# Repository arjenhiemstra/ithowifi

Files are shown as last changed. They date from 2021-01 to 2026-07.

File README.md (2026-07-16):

# ithowifi
ESP based WiFi controller for Itho devices

*(note: I'm in no way a professional hardware/software engineer and have no background in these subjects. I like this for a hobby, to learn and to share my projects)*

Finished boards can be ordered in my webshop:
[https://www.nrgwatch.nl](http://www.nrgwatch.nl)
or in my Tindie store:
[https://www.tindie.com/products/19680/](https://www.tindie.com/products/19680/)

|CVE Add-on|non-CVE wifi module|
|:---:|:---:|
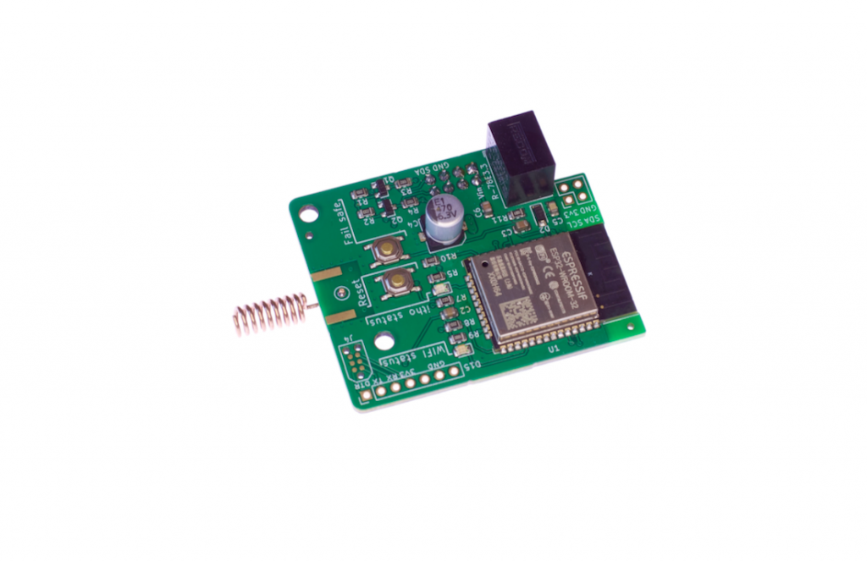
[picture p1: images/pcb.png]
CVE Add-on PCB
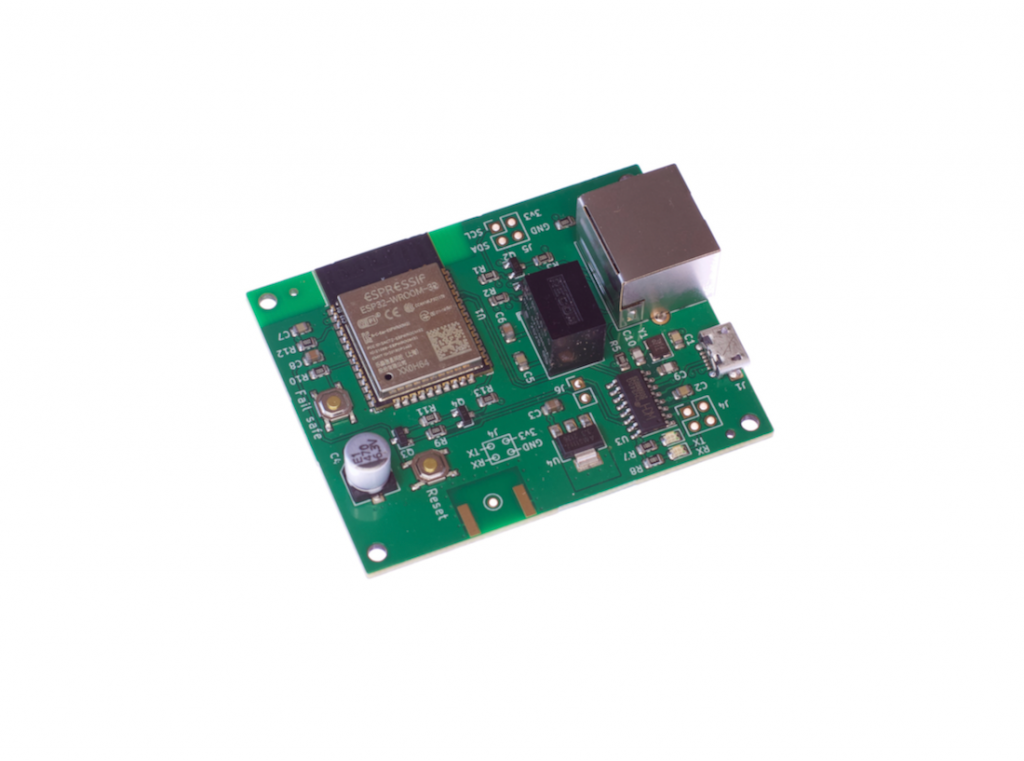
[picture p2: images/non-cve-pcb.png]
non-CVE module PCB
|  |  |

## WiFi add-on to control itho central ventilation units

-   Control your Itho Daalderop ventilation unit with one simple add-on module
-   No hardware changes needed to the Itho unit, no warranty void
-   Control fan speed through the web interface, REST API v2, MQTT, or Home Assistant
-   Send remote commands via virtual remotes (I2C) or RF remotes (CC1101 wireless)
-   RF standalone mode for devices without I2C connection (e.g. HRU 400)
-   OTA firmware updates directly from the web interface
-   Easily integrate in any home automation system through MQTT or REST API
-   Companion integrations available:
    - [Home Assistant](https://github.com/arjenhiemstra/ithowifi-ha-integration) (REST API, elementary)
    - [Home Assistant](https://github.com/jasperslits/haithowifi) (MQTT API, feature rich)
    - [Homey](https://homey.app/en-nl/app/nl.monkeysoft.nrgwatch/Itho-Daalderop/) (REST API)
    - [Homebridge](https://github.com/SanderBaron/homebridge-itho-daalderop-HUE) (Apple HomeKit, REST API / MQTT)
-   Installation can be done in minutes
-   Detailed installation manual and setup wizard

### CVE models (IthiWiFi CVE add-on - I2C):
-   CVE ECO 2 (also sold by 'Heatrae Sadia' in the UK)
-   CVE ECO RFT (SE/SP, HE/HP)
-   CVE-S ECO / PAK / Optima / CO2
-   HRU 200 ECO (also sold as 'Elektrodesign EHR 140 Akor BP' and 'Heatrae Sadia Advance Plus')

### NON-CVE models (IthiWiFi NON-CVE add-on - I2C):
-   HRU ECO fan
-   HRU 150 / 200 / 250 / 300 / 350
-   DemandFlow / QualityFlow
-   WPU 4G / 5G (heat pump)
-   AutoTemp

### RF standalone mode (IthiWiFi NON-CVE add-on wuth CC1101):
-   HRU 400
-   Most Itho devices controllable via RF (CC1101 module required)
-   Status data received wirelessly via 31DA/31D9 RF messages

####   Note about CVE and HRU200 firmware:
The CVE add-on controls the Itho unit in standard or medium mode setting only. If you leave the Itho in low or high setting, it won't accept I2C commands from the add-on (Itho designed behaviour). Adding a CC1101 RF module and/or using the virtual remote function can circumvent this issue. The virtual remote function can also be used to force medium mode before sending commands.

## APIs

The add-on provides multiple ways to integrate with your home automation system:

-   **REST API v2** — RESTful endpoints at `/api/v2/*` with JSON request/response format. [OpenAPI spec](https://github.com/arjenhiemstra/ithowifi/wiki/REST-API-v2) available.
-   **MQTT** — publish device status, receive commands. Compatible with Home Assistant MQTT Discovery.
-   **WebSocket** — real-time bidirectional communication used by the web interface.

## OTA Firmware Updates

Firmware can be updated directly from the web interface:
-   Select a firmware version from the dropdown (stable and beta versions available)
-   Click Install — the device downloads and flashes the firmware automatically
-   Manual upload via file is also supported

## Hardware:

A sample hardware design (KiCad) is included, this module can be plugged on the Itho main PCB directly without extra components.
The design files and BOM can be found in the [hardware repo](https://github.com/arjenhiemstra/ithowifi_hardware).

## Further information:

More information is available on the wiki and in the manual:
|  |  |
|---|---|
|Wiki:  |https://github.com/arjenhiemstra/ithowifi/wiki  |
|Dutch:  |https://github.com/arjenhiemstra/ithowifi/raw/master/handleiding.pdf  |
|English:  |https://github.com/arjenhiemstra/ithowifi/raw/master/manual.pdf  |

## Support this project:
If you like this project and would like to support it, please contribute with code updates, wiki edits, pull requests etc. You could also buy me a coffee as appreciation.
I will be really thankfull for anything even if it is just a kind comment towards my work, because that helps me a lot.

"Buy Me A Coffee" (https://www.buymeacoffee.com/nrgwatch)

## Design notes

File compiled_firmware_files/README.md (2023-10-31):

# Hardware revisions

Make sure to flash the correct firmware file! 
Flashing a firmware file for the wrong hardware revision will brick the device. This is reversible but especially with revision 2 you need extra hardware (USB-TTL adapter with a good power supply) to do so.

## CVE Add-on

Hardware revision 1:

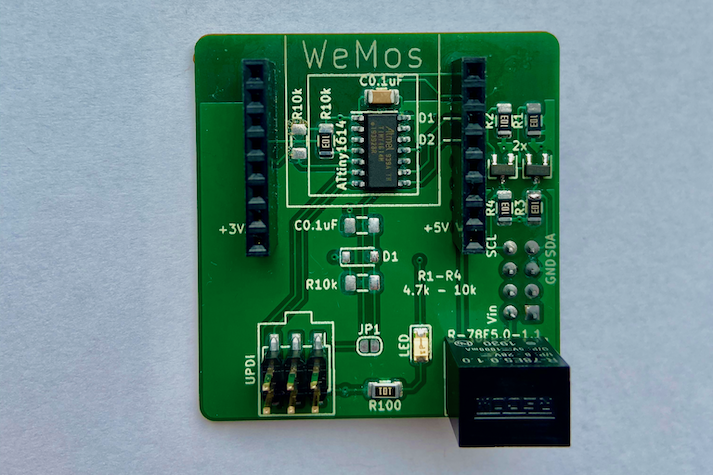
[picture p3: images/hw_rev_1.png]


Hardware revision 2:

Hardware revision 2

## non-CVE wifi module

Hardware revision 1:

Hardware revision 1

Since firmware version 2.6.0 hardware revision 2 and the non-cve module use the same firmware file.

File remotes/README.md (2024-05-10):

**Remotes known to be working**

An overview of supported remotes can be found here:
[remotes.pdf](https://github.com/arjenhiemstra/ithowifi/blob/master/remotes/remotes.pdf)

**Remotes known to be partly working**

RFT-Auto-N (04-00161) and RFT-N (04-00160) currently only work in legacy (uni-directional) mode

Since [2.9.0-beta1](https://github.com/arjenhiemstra/ithowifi/releases/tag/Version-2.9.0-beta1)
Bi-Directional join and communication is supported (partially). There might still be a error indication but most functionality should work for the RFT-Auto-N (04-00161), RFT-N (04-00160) and Itho Spider (03-00476) 

**Remotes known to be not working**

536-0106, seems like it uses a different (older) version of the protocol.

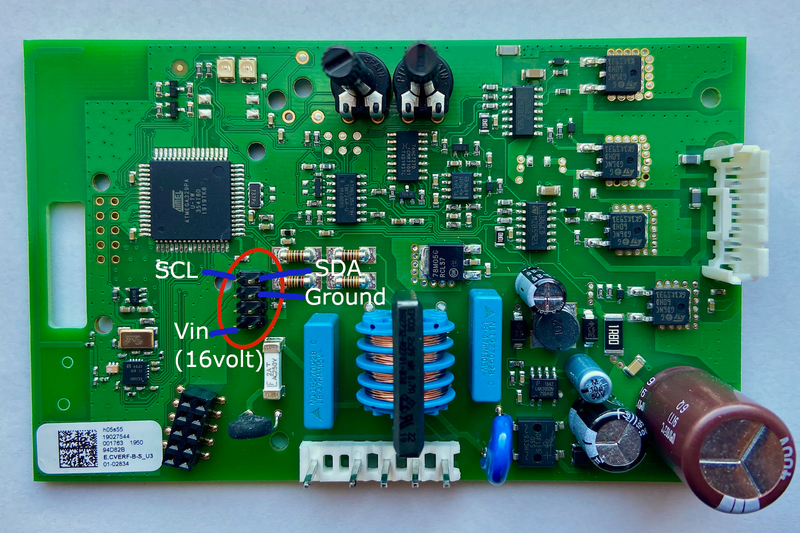
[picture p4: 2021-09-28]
images/wiki/pinout_itho.png

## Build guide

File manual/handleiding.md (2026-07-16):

NRG.Watch logo

# Itho WiFi add-on — Gebruikershandleiding

**Versie:** V1.13

**Datum:** 14-06-2026

| | |
|---|---|
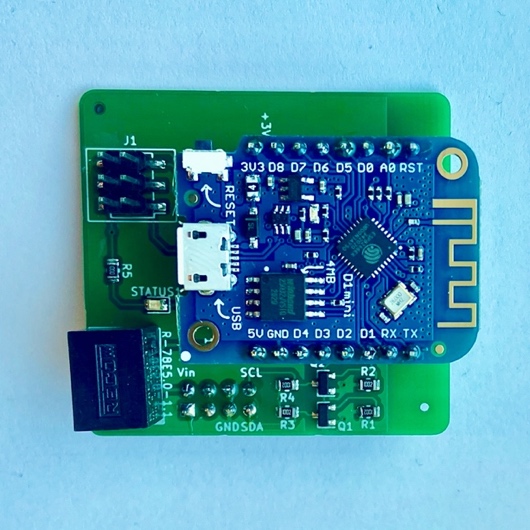
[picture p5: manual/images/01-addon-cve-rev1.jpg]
CVE add-on revisie 1.x
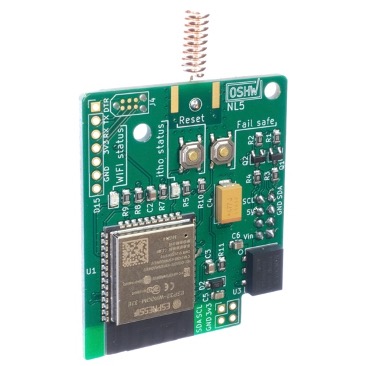
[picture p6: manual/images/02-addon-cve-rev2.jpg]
CVE add-on revisie 2.x
|  |  |
| **CVE add-on revisie 1.x** | **CVE add-on revisie 2.x** |
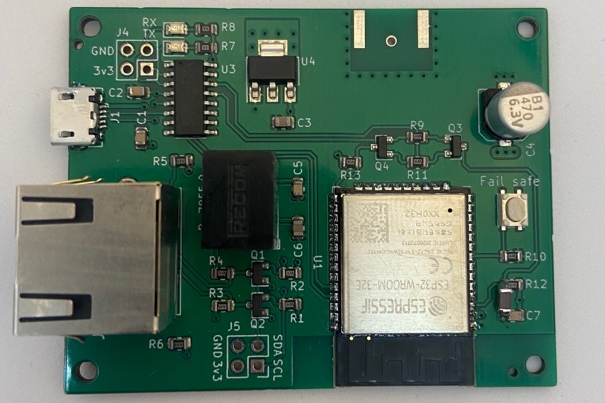
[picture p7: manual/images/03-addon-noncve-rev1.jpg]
Non-CVE add-on revisie 1.x
|  | |
| **Non-CVE add-on revisie 1.x** | |

---

## Inhoudsopgave

- [Voorwoord](#voorwoord)
- [Fysieke Installatie CVE Add-on](#fysieke-installatie-cve-add-on)
- [Fysieke Installatie non-CVE Add-on](#fysieke-installatie-non-cve-add-on)
- [Extra informatie voor de HRU250 en HRU300](#extra-informatie-voor-de-hru250-en-hru300)
- [Add-on Instellen](#add-on-instellen)
- [Gebruik (Webinterface, API)](#gebruik-webinterface-api)
- [Apparaat-specifieke informatie](#apparaat-specifieke-informatie)
- [Temperatuur/Vochtsensor](#temperatuurvochtsensor)
- [Virtual Remote](#virtual-remote)
- [RF-Module](#rf-module)
- [Firmware bijwerken](#firmware-bijwerken)
- [Module resetten](#module-resetten)
- [Hmmm, maar…. Waar vind ik verdere informatie?](#hmmm-maar-waar-vind-ik-verdere-informatie)
- [Hardware revisies](#hardware-revisies)
- [Installatievoorbeeld](#installatievoorbeeld)
- [Node-RED automatiseringsvoorbeeld](#node-red-automatiseringsvoorbeeld)
- [Ondersteunde afstandsbedieningen](#ondersteunde-afstandsbedieningen)

---

## Voorwoord

Bedankt voor de aanschaf van een (of meerdere) add-on modules, veel plezier met het gebruik!

Een belangrijke waarschuwing vooraf! Verschillende Itho apparaten (in ieder geval de CVE's en HRU200) zijn niet aanraakveilig als er spanning op staat, ook de laag voltage delen niet. Haal daarom altijd de spanning van het apparaat bij het installeren van een add-on op de printplaat. Zo voorkom je schade aan jezelf en je itho! Indien nodig, bedien de knopjes op de printplaat van de CVE add-on alleen met materiaal dat geen stroom kan geleiden.

Dit is een beknopte handleiding om je op weg te helpen de add-on fysiek te installeren en te verbinden met je eigen wifi netwerk. Informatie over verdere specifieke installaties is online te vinden.

Deze handleiding, de plug-ins voor oa. Home Assistant en Homey, de wiki en verdere informatie online zijn een community effort, een verzameling van bijdragen van gebruikers voor gebruikers. Zonder deze bijdragen was oa. dit document er niet geweest. Het wordt zeer gewaardeerd als je aanvullingen, aanpassingen en/of suggesties hebt!

**Bronnen waar verdere informatie te vinden is:**

- Wiki pagina: <https://github.com/arjenhiemstra/ithowifi/wiki>
- Tweakers.net forum: <https://gathering.tweakers.net/forum/list_message/82125986>
- Tweakers.net forum (WPU specifiek): <https://gathering.tweakers.net/forum/list_messages/2154474>
- Meest gestelde vragen: <https://gathering.tweakers.net/forum/list_messages/1976492/0#label-faq>

---

## Fysieke Installatie CVE Add-on

Om de add-on (PCB) goed te beschermen, leveren wij deze in een antistatisch zakje.

Hieronder volgt een genummerde lijst met handelingen, om de installatie van de add-on te realiseren.

1. Haal de add-on uit het antistatische zakje;
2. U treft naast de add-on, ook een PCB-afstandshouder aan, leg deze even apart.
3. Haal nu de spanning van de Itho ventilatie-unit, door de stekker uit de wandcontactdoos te halen;
4. Om bij de basisprint van de Itho te komen, haalt u de deksel van de unit. Dat kan door met een platte schroevendraaier de klemnokken aan de boven- en onderzijde te ontgrendelen. U ziet nu het kastje waarin de basisprint zit, deze is eenvoudig te bereiken door het deurtje te openen of in geval van een zwarte kap kan deze verwijderd worden door wat zijwaartse druk te combineren met een trek beweging naar boven. Zie de installatie & gebruik handleiding van de fabrikant, voor eventuele andere/specifieke instructies;
5. Plaats nu de PCB-afstandshouder met de kromme / korte kant in het gat op de itho basisprint dat overeenkomt met het gat op de add-on. Door gebruik van deze afstandshouder reduceert de kans, dat door trillingen, gesoldeerde punten mogelijk lostrillen. Eventueel kan deze stap ook na het testen van de add-on gedaan worden;
6. Het plaatsen van de add-on, benodigd geen speciaal gereedschap of andere materialen.
   U kunt, de add-on plaatsen door deze op de 2×4 pin interface aan te brengen.
   Zie Installatievoorbeeld, in het rood omcirkeld, waar de 2×4 pin interface zich bevindt op de basisprint;
7. Breng nu de spanning van de Itho terug door de stekker in de wandcontactdoos te plaatsen.
8. Als de initialisatie succesvol is, licht de Itho status led (zie Hardware revisies) kort op. Vervolgens blijft deze uit. Dit is een teken dat de communicatie, tussen de Itho basis/hoofdprint en add-on succesvol is gestart. De wifi status led zal knipperen als indicatie dat er een access point gestart is.
9. Nu is de add-on geïnstalleerd, sluit het kastje van de basisprint en plaatst u de deksel terug op de unit.

---

## Fysieke Installatie non-CVE Add-on

Om de add-on (PCB) goed te beschermen, leveren wij deze in een antistatisch zakje. Indien u een behuizing mee besteld hebt is de add-on al in de behuizing geplaatst. Laat de add-on in de behuizing zitten, het verwijderen van de print uit de behuizing kan de behuizing beschadigen.

Hieronder volgt een genummerde lijst met handelingen, om de fysieke installatie van de add-on te realiseren.

1. Haal, indien van toepassing, de add-on uit het antistatische zakje;
2. Zoek de COM/Service poort op je Itho device. Dit is aansluiting die lijkt op een netwerkpoort (RJ45 connector). Sluit de add-on met een goede, korte (CAT6a, STP, 25cm) netwerk kabel aan op de COM/Service poort;
3. De add-on is geïnstalleerd en zal een access point starten.

**Nb.** Stroom voor de add-on komt via de netwerkkabel vanuit de aangesloten Itho. In uitzonderlijke gevallen lijkt de Itho niet voldoende stroom te kunnen leveren (bepaalde revisies van de HRU300). Hierdoor is de communicatie met de HRU niet altijd stabiel. Sluit in dat geval een USB voeding aan op de add-on. In alle andere gevallen is dit niet nodig.

---

## Extra informatie voor de HRU250 en HRU300

Om de add-on te kunnen gebruiken met de HRU250 en HRU300 zijn een adapter bordje en PCI-e splitter kabel nodig.

Om deze te installeren:

1. Verwijder de PCI-e kabel uit de HMI van de HRU.
2. Sluit de PCI-e kabel van de HMI aan op de PCI-e splitterkabel.
3. Sluit 1 kant van de splitterkabel aan op de HMI, sluit de overgebleven kant aan op het HRU250/300 adapter bordje.
4. Met de netwerkkabel kan het adapter bordje verbonden worden met de add-on.

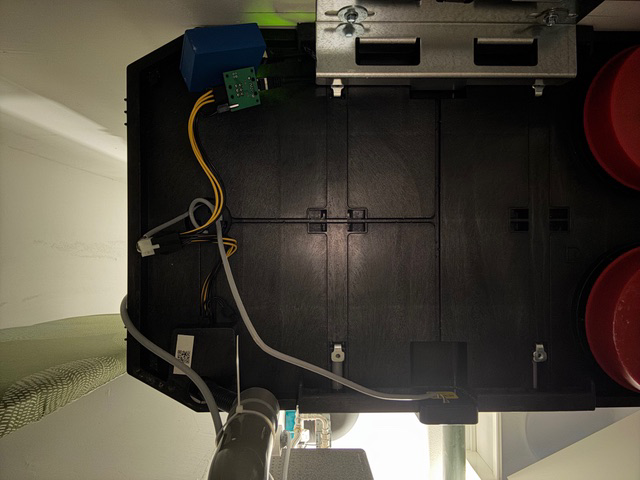
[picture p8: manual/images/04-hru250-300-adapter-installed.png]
HRU250/300 adapter installatie


### Bediening van de HRU250 en HRU300

Deze modellen zijn iets beperkter in de bediening via de add-on in vergelijking met andere Itho modellen. Om deze HRU te bedienen moet je gebruik maken van de CC1101 RF module op de add-on. De Virtual Remote optie werkt bij deze HRU modellen niet.

Om gebruik te maken van de RF module moet deze via de web interface van de add-on geactiveerd worden, dat kan onder het menu "System settings". Na een reboot komt er een menu item bij genaamd "RF Devices". Hier kan een RF device geconfigureerd worden. Dit RF device moet vervolgens gekoppeld worden aan de HRU. Volg hiervoor dezelfde procedure als waarmee ook fysieke remotes gekoppeld worden.

---

## Add-on Instellen

Hieronder treft je een genummerde lijst met stappen om de basis instellingen van de add-on te maken.

### Add-on instellen — *Verbinden met de add-on*

1. Na het aansluiten start de add-on automatisch een WiFi access point. De WiFi status led knippert dan 1x per seconde (zie Hardware revisies).

   Let op: zolang de add-on nog geen verbinding heeft met je WiFi-netwerk, blijft het access point actief. Zodra de add-on verbonden is, schakelt het access point na de ingestelde tijd (standaard 15 minuten) automatisch uit. Deze tijd is aan te passen in de instellingen.

2. Maak met je telefoon, tablet of computer verbinding met het WiFi netwerk van de add-on:
   - Netwerknaam (SSID): **nrg-itho-XXXX** (de laatste 4 tekens zijn uniek per add-on)
   - Wachtwoord: **password**

3. Open een browser en ga naar:
   `http://nrg-itho-XXXX.local` (vervang XXXX door de 4 tekens uit de netwerknaam)
   Werkt dit niet (bijv. op Android)? Ga dan naar <http://192.168.4.1>

### Add-on instellen — *Setup Wizard*

Vanaf firmware versie 3.0 start automatisch een Setup Wizard die je in een aantal stappen door de configuratie leidt:

**Stap 1 — WiFi**

Vul de naam (SSID) en het wachtwoord van je eigen WiFi netwerk in. Optioneel kun je een eigen hostname instellen. Klik op Connect en wacht tot de verbinding bevestigd wordt. Noteer het IP-adres dat getoond wordt — dit heb je nodig om de add-on later te bereiken vanuit je eigen netwerk.

**Stap 2 — Device**

De wizard detecteert automatisch welk type Itho apparaat is aangesloten (bijv. CVE-Silent, HRU 350, DemandFlow) en stelt de meest voorkomende standaardinstellingen in. Bij apparaten zonder I2C-verbinding (bijv. HRU 400) wordt de optie aangeboden om RF standalone modus te activeren.

**Stap 3 — RF** (wordt overgeslagen als er geen CC1101 RF module aanwezig is)

Hier configureer je de RF-afstandsbedieningen. Je kunt een afstandsbediening koppelen (join) met de Itho apparaat, of deze stap overslaan en later via het menu "RF Devices" instellen.

Werk je in RF-standalone modus (een apparaat zonder I2C, bijvoorbeeld de HRU 400)? Dan is dit het moment om een geëmuleerde RFT CO2-remote aan de Itho te koppelen — daarmee stuur je het apparaat vervolgens aan en lees je de status uit.

**Stap 4 — MQTT** (optioneel)

Vul de gegevens van je MQTT server in als je de add-on wilt koppelen aan Home Assistant, Domoticz of een ander domotica platform via MQTT. Schakel eventueel Home Assistant MQTT Auto Discovery in zodat de add-on automatisch als apparaat in Home Assistant verschijnt.

**Stap 5 — HA Discovery** (wordt overgeslagen als MQTT niet is ingeschakeld)

Configureer welke sensoren en statusinformatie via HA Auto Discovery beschikbaar worden gesteld aan Home Assistant.

### Add-on instellen — *Na de wizard*

Verbind je telefoon/computer weer met je eigen WiFi netwerk en open de browser op het IP-adres uit de wizard.

Alle instellingen zijn ook achteraf aan te passen via de web interface. De wizard hoeft niet opnieuw doorlopen te worden.

---

## Gebruik (Webinterface, API)

De Itho unit is nu d.m.v. de web interface (<http://nrg-itho-A1B2.local>, A1B2 vervangen), via MQTT of WebAPI te bedienen.

Wil je de add-on via MQTT koppelen aan domotica? Dan heb je een MQTT-server (broker) nodig. De web interface en de WebAPI werken overigens ook zonder MQTT. Heb je nog geen MQTT-server, dan vind je via onderstaande link een prima voorbeeld hoe je deze installeert op bijvoorbeeld een Raspberry Pi:

<https://randomnerdtutorials.com/how-to-install-mosquitto-broker-on-raspberry-pi/>

### Itho bedienen

Er zijn verschillende mogelijkheden om de Itho te bedienen en de settings aan te passen.

Voor CVE's en de HRU 200 zijn er 2 manieren om de snelheid te regelen: remote-commando's (virtual of RF) en het traploze PWM2I2C-protocol. Voor andere apparaten (bijvoorbeeld de HRU 350) zijn alleen de remote-commando's (virtual remote en/of RF-remote) beschikbaar. Voor de HRU 250 en HRU 300 werken uitsluitend RF-remote commando's. Om RF-remote commando's te versturen moet de CC1101 RF-module aanwezig zijn op de add-on. Virtual-remote commando's (waarbij de add-on een fysieke remote emuleert) worden via de fysieke I2C-verbinding met de Itho verstuurd.

Wat per apparaat precies mogelijk is, staat in het hoofdstuk [Apparaat-specifieke informatie](#apparaat-specifieke-informatie).

Meer details over de verschillende mogelijkheden en de eventuele beperkingen zijn op de wiki te vinden:

<https://github.com/arjenhiemstra/ithowifi/wiki/Controlling-the-speed-of-a-fan>

### Koppeling met Home Domotica software

De add-on kan met andere apparaten en domotica gekoppeld worden via MQTT en de WebAPI. De details hiervan staan in het kopje *De API gebruiken* hieronder.

Voor de meest gebruikte platforms zijn er kant-en-klare integraties:

- **Home Assistant — MQTT Auto Discovery.** Schakel je MQTT in met Home Assistant MQTT Auto Discovery, dan wordt de add-on automatisch als apparaat in Home Assistant geconfigureerd met een basis configuratie. Deze kan handmatig aangepast en uitgebreid worden.
- **Home Assistant — losse integraties.** Er zijn daarnaast twee community-integraties voor Home Assistant:
  - [ithowifi-ha-integration](https://github.com/arjenhiemstra/ithowifi-ha-integration) — gebruikt de REST API (lokaal, eenvoudig).
  - [haithowifi](https://github.com/jasperslits/haithowifi) — gebruikt de MQTT API (uitgebreider).
- **Homey.** De [Itho Daalderop-app](https://homey.app/en-nl/app/nl.monkeysoft.nrgwatch/Itho-Daalderop/) in de Homey app store gebruikt de WebAPI (REST); MQTT is daarvoor niet nodig.
- **Homebridge (Apple HomeKit).** De community-plugin [Homebridge Itho Daalderop HUE](https://github.com/SanderBaron/homebridge-itho-daalderop-HUE) brengt je CVE naar Apple HomeKit. Hij communiceert via de WebAPI of MQTT (MQTT aanbevolen voor directe updates) en biedt optioneel een koppeling met Philips Hue.
- **Domoticz en andere platforms.** Koppeling verloopt via MQTT (of de WebAPI).

### De API gebruiken (WebAPI en MQTT)

De add-on heeft twee API's waarmee je de Itho kunt uitlezen en bedienen, bijvoorbeeld vanuit eigen scripts of domotica: een **WebAPI** (HTTP) en een **MQTT API**. Beide accepteren dezelfde commando's.

De volledige en altijd actuele lijst met endpoints en commando's voor jouw firmwareversie vind je in de web interface onder het menu **API** (interactieve documentatie). De onderliggende OpenAPI-specificatie is ook rechtstreeks op te halen via `http://<add-on>/api/openapi.json`.

**WebAPI (HTTP)**

Er zijn twee varianten:

- **REST API (v2)** — een JSON-API onder `/api/v2/…`. Een greep uit de endpoints:
  - `GET /api/v2/deviceinfo` — apparaat- en firmware-informatie
  - `GET /api/v2/ithostatus` — alle actuele statuswaarden
  - `GET /api/v2/speed` en `GET /api/v2/lastcmd` — huidige snelheid en laatste commando
  - `GET /api/v2/remotes`, `/api/v2/vremotes` en `/api/v2/rfstatus` — (virtuele) remotes en RF-status
  - `GET` en `PUT /api/v2/settings` — instellingen uitlezen en wijzigen
  - `POST /api/v2/command` — een commando sturen (bijvoorbeeld een ventilatiestand)
  - `POST /api/v2/vremote` en `POST /api/v2/rfremote/command`, `/co2`, `/demand`, `/config` — virtual- en RF-remote commando's
  - `POST /api/v2/wpu/outside_temp` en `/api/v2/wpu/manual_control` — WPU-specifiek
- **Legacy API (v1)** — eenvoudige uitlees-API in query-stijl via `/api.html`, bijvoorbeeld:
  - `http://<add-on>/api.html?get=ithostatus`
  - `http://<add-on>/api.html?get=currentspeed` (overige waarden: `lastcmd`, `queue`, `remotesinfo`)

  Het uitlezen en wijzigen van instellingen is verplaatst naar de REST API (`GET`/`PUT /api/v2/settings`).

**MQTT API**

Als MQTT is geconfigureerd, gebruikt de add-on onderstaande topics. Het *base topic* is instelbaar (standaard `itho`):

- `itho/cmd` — publiceer hier je commando's naar de add-on (dezelfde set als de WebAPI).
- `itho/cmd/response` — het antwoord van de add-on op een commando.
- `itho/state` — hier publiceert de add-on een JSON met alle statuswaarden.
- `itho/lwt` — de online/offline status van de add-on (Last Will & Testament).

Een werkend voorbeeld (Node-RED) dat naar `itho/cmd` publiceert, staat in het [Node-RED automatiseringsvoorbeeld](#node-red-automatiseringsvoorbeeld).

---

## Apparaat-specifieke informatie

De add-on herkent automatisch welk Itho-apparaat is aangesloten en past de beschikbare instellingen en uitleesbare statuswaarden daarop aan. Hieronder staat per apparaat(groep) hoe het wordt aangestuurd, welke informatie de add-on uitleest en waar je op moet letten.

Naast de hieronder per apparaat beschreven aansturing kan vanaf de add-on bij **elke ventilator (CVE en HRU)** en **DemandFlow** een RFT CO2-remote geëmuleerd worden. Na koppeling met het apparaat kan het daarmee traploos van 0–100% aangestuurd worden, in stapjes van een half procent. Dit werkt zowel bij een I2C-aansluiting als in RF-standalone modus. Alleen bij de CVE's kan deze RF-communicatie minder betrouwbaar zijn; zie het hoofdstuk *CVE-familie* hieronder.

> **Let op:** welke statuswaarden en instellingen precies beschikbaar zijn, hangt af van het model én de firmwareversie van het Itho-apparaat. De web interface en de API-pagina tonen altijd de actuele, volledige lijst voor jouw apparaat. De waarden hieronder zijn voorbeelden van wat een apparaat zoal rapporteert.

### CVE-familie (CVE, CVE-Silent, HRU 200)

**Modellen:** CVE, CVE-Silent en de HRU 200 (in de web interface herkend als *CVE-SilentExtPlus*). Ook de CVE ECO2 en CVE-SilentExt worden herkend, maar bieden alleen basisstatus.

**Aansturing:** deze units communiceren via de fysieke I2C-verbinding op de basisprint. De snelheid kan op twee manieren geregeld worden:

- **Remote-commando's** — een *virtual remote* die de add-on emuleert, of een fysieke/RF-remote (RF vereist de CC1101-module).
- **PWM2I2C** — een traploos protocol voor staploze regeling (0–100%). Dit is alleen beschikbaar op de CVE's en de HRU 200, niet op de andere apparaten.

Standaard staat de add-on in PWM2I2C-modus; de remote-modus kun je instellen via *System settings*.

> **Let op (modellen met ingebouwde CO2-sensor):** bij CVE-S Optima Inside-modellen met een ingebouwde CO2-sensor werkt PWM2I2C niet — de PWM2I2C-commando's worden overruled door de interne CO2-sensor. Gebruik bij deze modellen virtual remote-aansturing.

**Wat de add-on uitleest (o.a.):** ventilatieniveau/-setpoint (%), gevraagd en actueel toerental (rpm), gekozen stand, foutcode, opstartteller, bedrijfsuren, **CO2-waarde (ppm)**, klepstand en aanwezigheidstimer. Nieuwere CVE's hebben een ingebouwde vochtsensor — zie het hoofdstuk [Temperatuur/Vochtsensor](#temperatuurvochtsensor).

De **CVE-Silent** meldt aanvullend onder meer de hoogst gemeten CO2 (ppm) en RH (%), de interne luchtvochtigheid (%) en temperatuur (°C) en afwezigheidstimers. De **HRU 200** heeft de meest uitgebreide set van de familie, met daarnaast onder meer filtergebruik (uren), buiten- en afblaastemperatuur, gemiddelde uitblaastemperatuur, bypassmodus en -stand, en de maximale CO2-/RH-niveaus.

> **Let op (RF bij CVE's):** bij de CVE's zitten de antennes van de add-on en de unit dicht bij elkaar. Dit kan bij RF-aansturing (zoals een geëmuleerde RFT CO2-remote) tot communicatieproblemen leiden. Gebruik bij de CVE's daarom bij voorkeur de I2C-aansturing (virtual remote of PWM2I2C).

### HRU warmteterugwinning via I2C (HRU 350, HRU ECO-fan)

**Modellen:** HRU 350 en HRU ECO-fan.

**Aansturing:** via de I2C-verbinding, met remote-commando's (virtual remote of RF). Het traploze PWM2I2C-protocol is bij deze modellen **niet** beschikbaar — alleen de remote-standen/commando's.

**Wat de add-on uitleest (o.a.):** gevraagde ventilatiestand (%), balans (%), toevoer- en afvoerventilator (zowel gevraagd als actueel toerental), toevoer-, afvoer-, ruimte- en buitentemperatuur (°C), klep- en bypassstand, vorst- en boilertimers, filterteller, globale foutcode, actuele modus, hoogst gemeten CO2 (ppm) en RH (%), luchtkwaliteit (%) en de resterende override-timer. De HRU ECO-fan rapporteert een vergelijkbare set rond toevoer/afvoer, temperaturen, bypass en filtergebruik.

> **DuoZone:** HRU-units met twee zones (DuoZone) worden herkend; de zonegegevens verschijnen op de RF Status-pagina van de web interface (en via `GET /api/v2/rfstatus`).

### HRU 250 / HRU 300

**Aansturing:** deze modellen worden **uitsluitend via RF (CC1101)** aangestuurd en uitgelezen — de Virtual Remote-optie werkt hier niet. Er moet daarvoor een RF-remote vanaf de add-on gekoppeld worden.

**Speciale hardware:** een adapterbordje en een PCI-e splitterkabel zijn nodig. De fysieke installatie hiervan staat in het hoofdstuk [Extra informatie voor de HRU250 en HRU300](#extra-informatie-voor-de-hru250-en-hru300). Bij sommige revisies van de HRU 300 kan de unit te weinig stroom leveren; sluit in dat geval een USB-voeding aan op de add-on.

**Wat de add-on uitleest (o.a.):** buiten- en gemengde-luchttemperatuur (°C), toevoer- en afvoerdebiet (m³/h), inlaat-, afvoer- en uitgeblazen-luchttemperatuur (°C), relatieve en absolute ventilatorsnelheid (%), de massflow in- en uitgaand (kg/h), bypassstand (%), gewenste inlaattemperatuur, uitgebreide vorstgegevens, motortoerental (rpm), de hoogst gemeten RH/CO2 en het stroomverbruik van de ventilator (mA).

### Apparaten zonder I2C — RF-standalone (bijv. HRU 400)

Sommige units (bijvoorbeeld de HRU 400) hebben geen voor de add-on bruikbare I2C-verbinding. Hiervoor is de **RF-standalone modus**: de add-on slaat I2C volledig over en werkt alleen via RF (CC1101).

- **Activeren:** de Setup Wizard biedt dit aan bij apparaten zonder I2C; later kan het ook via *System settings*.
- Vanaf de add-on kan een RFT CO2-remote geëmuleerd worden. Nadat deze aan de HRU is gekoppeld, kan de HRU hiermee traploos aangestuurd worden van 0–100% in stapjes van een half procent.
- Met een gekoppelde, geëmuleerde RFT CO2-remote kan periodiek de status (zoals ventilatiestand en temperaturen) opgevraagd worden.

Voor deze modus is een CC1101 RF-module vereist.

### DemandFlow

**Aansturing:** via de I2C-verbinding. DemandFlow is een vraaggestuurd ventilatiesysteem met meerdere ruimtes; bediening en uitlezing lopen via de web interface, MQTT en de WebAPI.

**Wat de add-on uitleest (o.a.):** bedrijfsstatus en -modus, relatieve vochtigheid per badkamer (%), afvoerventilator (%), CO2 in het plenum (ppm) plus de berekende CO2 per ruimte (keuken, toilet, woonkamer, slaapkamers, enzovoort), de berekende klep-/flapstanden en het berekende luchtdebiet per ruimte (m³/h), en de foutcode.

### AutoTemp

**Modellen:** AutoTemp en AutoTemp Basic.

**Aansturing:** via de I2C-verbinding. AutoTemp is een zoneregeling (per kamer), bijvoorbeeld voor vloerverwarming; bediening en uitlezing via de web interface, MQTT en de WebAPI.

**Wat de add-on uitleest (o.a.):** modus, conditie en foutcode, en per ruimte (tot 12 kamers) de gemeten temperatuur, het setpoint en het afgegeven vermogen (% en kW), plus de klepstanden per verdeler/zone.

### WPU (warmtepomp)

De WPU is een warmtepomp (in de firmware aangeduid als *Heatpump*), geen ventilatie-apparaat. Het heeft veruit de uitgebreidste set uitleesbare waarden.

**Aansturing:** via de I2C-verbinding; uitlezing en instellingen via de web interface, MQTT en de WebAPI.

**Wat de add-on uitleest (o.a.):** een groot aantal temperaturen (buiten, boiler boven/onder, verdamper, zuig- en persgas, vloeistof, bron aan/af, CV-aanvoer en -retour, °C), CV-druk (bar), het stroomverbruik van compressor en elektrisch element (A), pompsnelheden voor CV, bron en boiler (%), klepstanden, de status van compressor/element/steunverwarming, diverse timers en een foutcode met gedetailleerde foutbytes.

> De foutbytes worden als ruwe waarden getoond; een vertaaltabel naar omschrijvingen zit niet in de add-on. Raadpleeg voor de betekenis de documentatie van Itho.

### Overige herkende apparaten

De add-on herkent daarnaast nog diverse andere Itho-apparaten op naam (zoals Air curtain, LoadBoiler, GGBB, CO2 relay, OLB, RF+, Extended (Plus), AreaFlow en RF_CO2). Hiervan toont de add-on de basisinformatie, maar (nog) geen uitgebreide instellingen of statuslijst.

---

## Temperatuur/Vochtsensor

Nieuwe Itho CVE units worden standaard geleverd met een vochtsensor. De add-on kan deze sensor uitlezen.

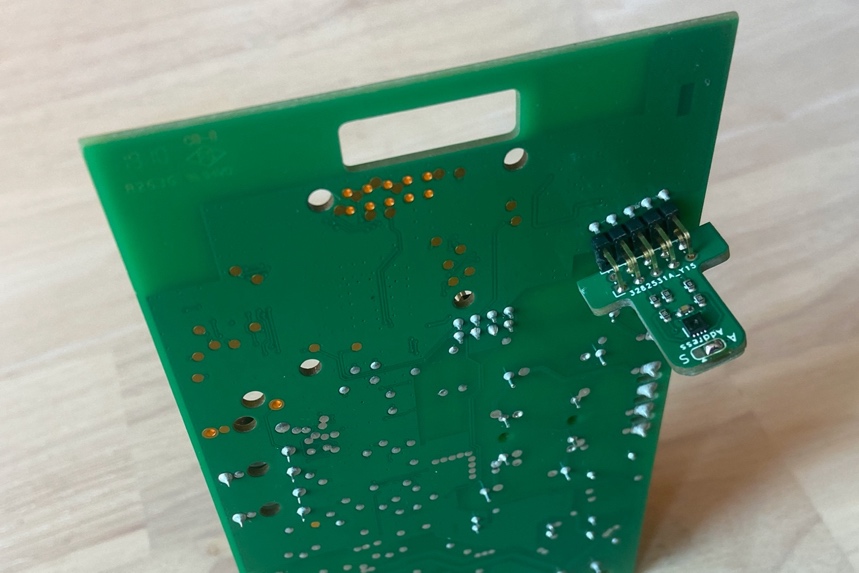
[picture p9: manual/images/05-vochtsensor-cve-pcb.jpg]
CVE PCB met vochtsensor


Oudere Itho modellen zonder vochtsensor zijn, met wat tweakers skills, ook uit te rusten met een temperatuur/vochtsensor.

De aansluitingen van de vochtsensor zijn als volgt en corresponderende aansluitingen op de add-on print zijn aangegeven met rode markeringen en labels.

| | |
|---|---|
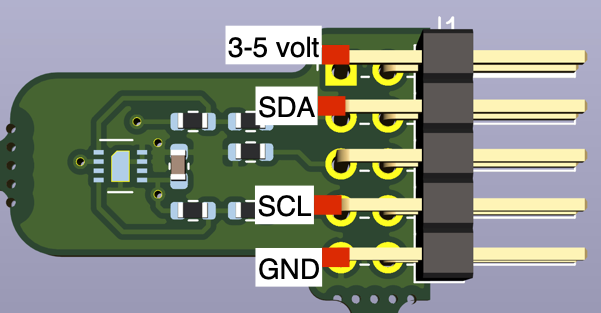
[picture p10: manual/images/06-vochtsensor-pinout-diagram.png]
Vochtsensor pinout diagram
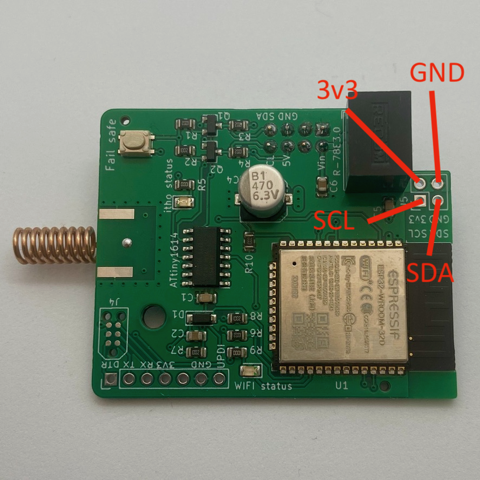
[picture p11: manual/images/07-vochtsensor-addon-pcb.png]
Add-on PCB met SCL/SDA/3v3/GND markering
|  |  |

Hier is een voorbeeld te vinden van een tweaker die dit succesvol heeft gedaan:

<https://gathering.tweakers.net/forum/list_message/66500576#66500576>

---

## Virtual Remote

De add-on kan zich voordoen als een of meer **virtuele remotes**. Een virtuele remote emuleert een fysieke afstandsbediening volledig in software en stuurt de Itho rechtstreeks aan via de **I2C-verbinding** (de bedrade verbinding op de basisprint). Hiervoor is dus géén CC1101 RF-module nodig.

**Welke apparaten?** Virtuele remotes werken bij de via I2C aangesloten ventilatie-apparaten, zoals de CVE-familie, de HRU 350 en de HRU ECO. De meeste fan-apparaten hebben baat bij minstens één virtuele remote voor de bediening. Ze werken **niet** bij de HRU 250, HRU 300 en HRU 400; die worden uitsluitend via RF aangestuurd (zie [RF-Module](#rf-module)).

**Koppelen.** Net als een fysieke remote moet ook een virtuele remote eerst aan de Itho gekoppeld (joined) worden. De add-on kan hiervoor automatisch een join-commando sturen (optie *Send join command*, bij de eerstvolgende keer inschakelen).

**Verschil met een geëmuleerde RF-remote.** Een *virtuele remote* communiceert via de bedrade **I2C-verbinding** met de Itho; een *geëmuleerde RF-remote* communiceert **draadloos via de CC1101-module** (868 MHz), net als een fysieke afstandsbediening. Gebruik een virtuele remote bij apparaten met een I2C-verbinding, en een geëmuleerde RF-remote bij apparaten die alleen via RF werken (HRU 250/300/400) of om draadloze sensoren (zoals RFT CO2) te emuleren.

---

## RF-Module

Voor RF-functionaliteit is een CC1101-module op de add-on nodig.

De CC1101 module kan de RF-signalen van Itho-afstandsbedieningen ontvangen en versturen.
De meest verkochte afstandsbedieningen van Itho worden ondersteund.

**Een bestaande remote overzetten naar de add-on.** Een bestaande fysieke afstandsbediening kan overgezet worden naar de add-on, zodat de add-on de RF-commando's van die remote ontvangt en vertaalt naar de Itho. De remote wordt daarbij van de Itho ontkoppeld en aan de add-on gekoppeld, volgens onderstaande procedure.

> **Let op:** de keuze voor het afhandelen van RF commando's van bestaande remotes via de add-on is niet beschikbaar voor de HRU 250, HRU 300 en HRU 400. Het monitoren van RF communicatie is wel mogelijk. Laat daarom bestaande RF remotes gekoppeld aan de Itho en koppel de add-on als extra remote aan je HRU.

1. Ontleer de afstandsbediening door een leave commando te versturen binnen de eerste 2 minuten nadat je de Itho unit aan hebt gezet (op de afstandsbediening doe je dat door alle 4 de knoppen tegelijkertijd in te drukken);
2. Als je dat nog niet gedaan hebt; stel de add-on module verder in en activeer (als laatste) de RF-module onder het menu "System settings";
3. De add-on reboot;
4. Als de RF-module correct gedetecteerd is verschijnt in hetzelfde menu de optie om Itho afstandsbedieningen te beheren. Voeg pas afstandsbedieningen toe, nadat de Itho unit uit learn/leave mode is (dus minimaal 2 minuten na inschakelen) anders wordt de remote opnieuw aan de Itho gekoppeld;
5. Zet de add-on in learn/leave mode (via de web interface);
6. Verstuur een learn commando met je remote (meestal 2 diagonaal tegenover elkaar liggende knoppen tegelijkertijd indrukken, zie anders de handleiding van de specifieke remote);
7. Als het goed is komt nu je remote ID op de eerste vrije positie te staan (zie plaatje hieronder), mocht na meerdere pogingen nog niet slagen, dan kan het zijn dat de remote (nog) niet wordt ondersteund. Neem dan contact op met support.

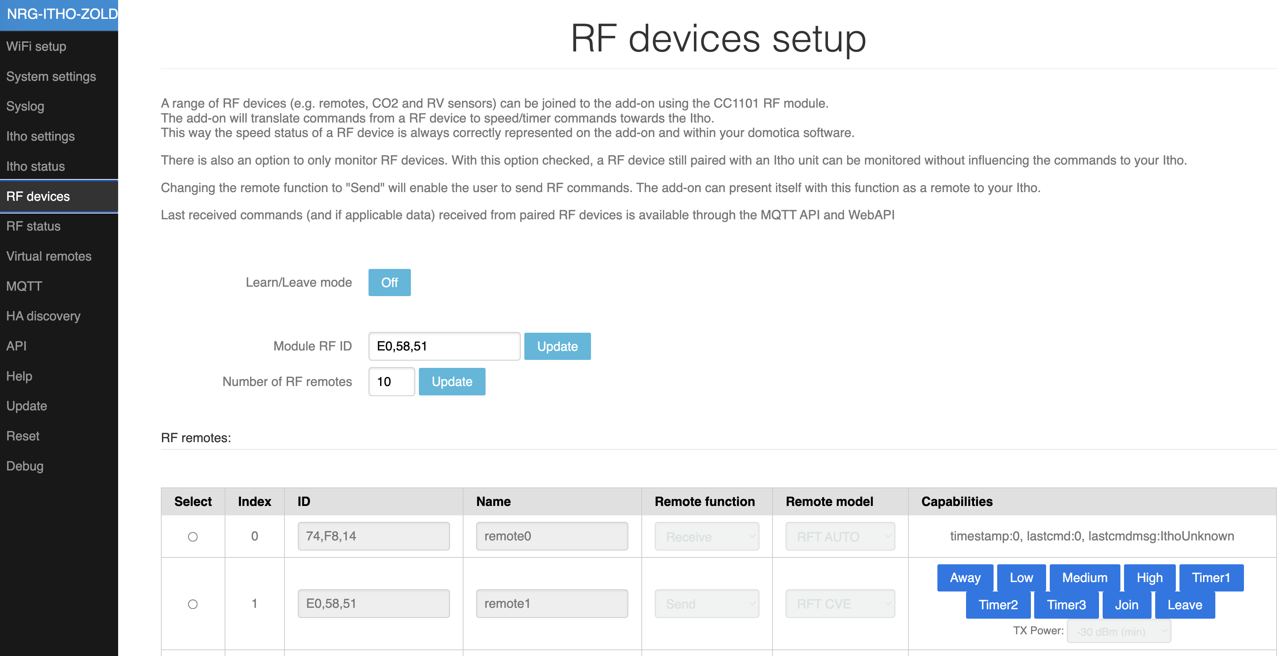
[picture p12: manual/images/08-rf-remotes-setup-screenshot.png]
RF Remotes setup screenshot


**De add-on als geëmuleerde RF-remote.** De add-on kan zich ook voordoen als een geëmuleerde RF-remote: via de CC1101-module gedraagt de add-on zich draadloos als een Itho-afstandsbediening. Met de *Remote function* op **Send** verstuurt de add-on draadloos snelheids- en timercommando's naar de Itho. Dit wordt gebruikt bij apparaten zonder bruikbare I2C-verbinding (zoals de HRU 250, HRU 300 en HRU 400) en om bijvoorbeeld een RFT CO2-sensor te emuleren.

Voordat een geëmuleerde RF-remote werkt, moet deze eenmalig aan de Itho gekoppeld (joined) worden — net als een fysieke remote. Zet de Itho daarvoor in zijn koppel-/learn-modus (zie handleiding van je Itho) en start het koppelen met de blauwe join-knop bij de betreffende remote op de **RF devices**-pagina. Daarna is de add-on te gebruiken zoals een echte fysieke remote.

**Opmerking:** Er is een debug optie om RF-commando's zichtbaar te maken in de web interface. Stel hiervoor op de **Syslog** pagina, bij *RF Debug log level*, één van de volgende niveaus in:

- **Level 1:** toont alle herkende Itho remote commando's incl. remote ID
- **Level 2:** toont alle RF-pakketten die vanaf een ingestelde remote komen (zie <https://github.com/arjenhiemstra/ithowifi/tree/master/remotes> voor meer details hoe dit te gebruiken)
- **Level 3:** toont alle RF-pakketten die verwerkt worden (hier zitten waarschijnlijk heel veel niet Itho gerelateerde pakketten tussen)
- **Level 0:** schakelt de debug-optie weer uit

De RF-log verschijnt op de **Syslog** pagina zodra het eerste RF-commando ontvangen is.

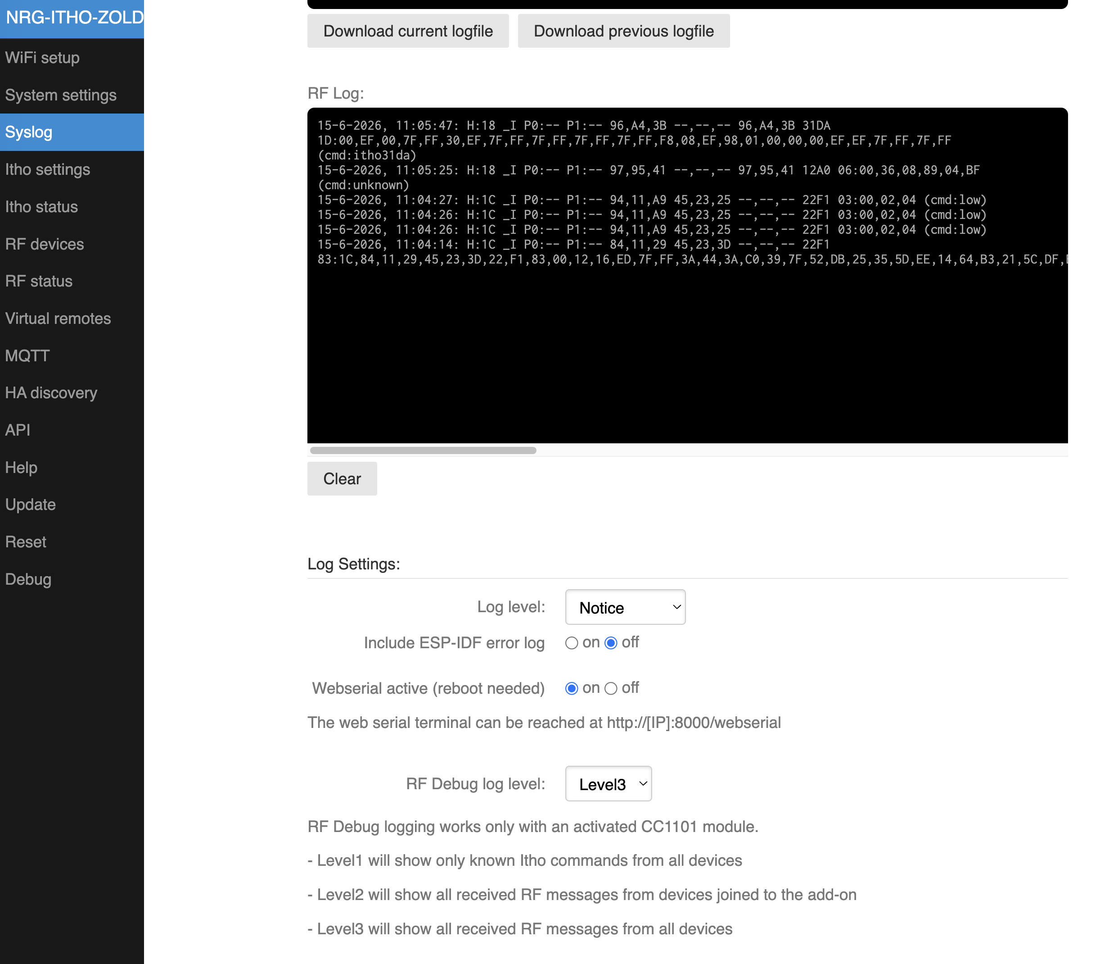
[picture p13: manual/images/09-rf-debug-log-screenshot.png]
RF debug log screenshot


---

## Firmware bijwerken

De firmware van de add-on werk je eenvoudig bij via de web interface.

1. Open de web interface en ga naar het menu **Update**.
2. Kies welke firmware je wilt installeren:
   - **Stable** — de aanbevolen, stabiele versie.
   - **Beta** — de nieuwste testversie met de laatste functies (kan nog fouten bevatten).
3. Klik op de knop **Install**.
4. De add-on haalt de gekozen firmware automatisch op van GitHub en installeert deze. Volg de voortgang op de pagina; zodra de update klaar is, herstart de add-on automatisch.

Bij een normale update blijven je instellingen behouden. Alleen een factory reset wist de configuratie (zie [Module resetten](#module-resetten)).

**Voortgang in Home Assistant.** Beide Home Assistant-integraties — de REST- en de MQTT-variant — tonen de add-on als *update entity*; tijdens een update wordt de voortgang als voortgangsbalk getoond.

**Zelf een firmwarebestand uploaden.** Lukt het automatisch ophalen niet (bijvoorbeeld zonder internetverbinding), dan kun je op de Update-pagina ook handmatig een `.bin`-firmwarebestand uploaden. Datzelfde kan via de nood-firmware na een failsafe boot (zie [Module resetten](#module-resetten)).

---

## Module resetten

### Fail safe boot / module factory reset

Mocht het onverhoopt voorkomen dat de module door een verkeerde configuratie niet meer bereikbaar is, dan is het mogelijk om de module te booten in fail safe mode. Hierbij wordt het bestandssysteem met configuratie bestanden geformatteerd, en start de module een vereenvoudigde web interface waarmee het mogelijk is om een nieuwe firmware te flashen.

De procedure voor deze reset is als volgt:

1. reset knop indrukken
2. wachten totdat de WiFi status led snel gaat knipperen (2x per sec)
3. druk vervolgens binnen 2 sec op de "Fail save" (sommige revisies "default") knop
4. Kort hierna zal het wifi ledje 1x per seconde gaan knipperen
5. Als je geen nieuwe firmware wilt flashen, sla dan deze stop over.
   De add-on heeft nu een access point gestart met een vereenvoudige "nood" firmware. Hiermee kan alleen een nieuwe firmware geflashed worden. De webpagina is te bereiken op het volgende adres: <http://192.168.4.1/update>
   Het uploaden van een nieuwe firmware kan een minuut duren, wacht rustig af totdat de pagina refreshed en het resultaat laat zien.
6. reset knop indrukken

hierna zijn alle instellingen gewist en zal de add-on in factory default mode starten.

Er is ook een youtube filmpje beschikbaar die deze procedure laat zien:
<https://youtu.be/3sWclzq73n4>

Deze methode is alleen beschikbaar als er gebruik wordt gemaakt van een 'officiële' firmware of, een firmware die hierop gebaseerd is.

**Hardware revisies t/m 2.5** (zie achterkant add-on):

Om deze mode te activeren voor de hardware revisies t/m versie 2.5 moet een andere procedure gevolgd worden:

Verbind de twee metalen vlakjes waarbij 'failsafe' staat op de print met elkaar. Dit gaat het makkelijkst met een soldeerbout en een beetje soldeer of door de vlakjes met bijvoorbeeld een schroevendraaier met elkaar te verbinden.

Bij het aanzetten van de Itho met de add-on geinstalleerd zal de add-on de fail save procedure uitvoeren en alle instellingen verwijderen. Ook kan eventueel een nieuwe firmware geladen worden zoals eerder beschreven.

Verwijder na deze procedure de eventueel aanwezige soldeerverbinding, en neem de module weer in gebruik zoals beschreven in deze handleiding.

---

## Hmmm, maar…. Waar vind ik verdere informatie?

Er staat ontzettend veel nuttige informatie op de wiki:
<https://github.com/arjenhiemstra/ithowifi/wiki>
Deze is voor gebruikers en door gebruikers. Voel je vrij om hier ook aanpassingen te doen.

Op tweakers.net, loopt een draadje op het forum over deze add-on.
Hier staat ook meer informatie over het gebruik van deze add-on, in combinatie met bv. Home Assistant, Domoticz andere systemen.

Verder kun je daar terecht voor vragen.
De link is: <https://gathering.tweakers.net/forum/list_messages/1976492/0>

Voor verdere vragen, feedback en code aanpassingen kun je contact opnemen via <info@nrgwatch.nl> of <https://www.github.com/arjenhiemstra/ithowifi>.

---

## Hardware revisies

Afbeeldingen kunnen iets afwijken met het product dat u ontvangen heeft, de werking is echter gelijk.

**Hardware revisie 1:**

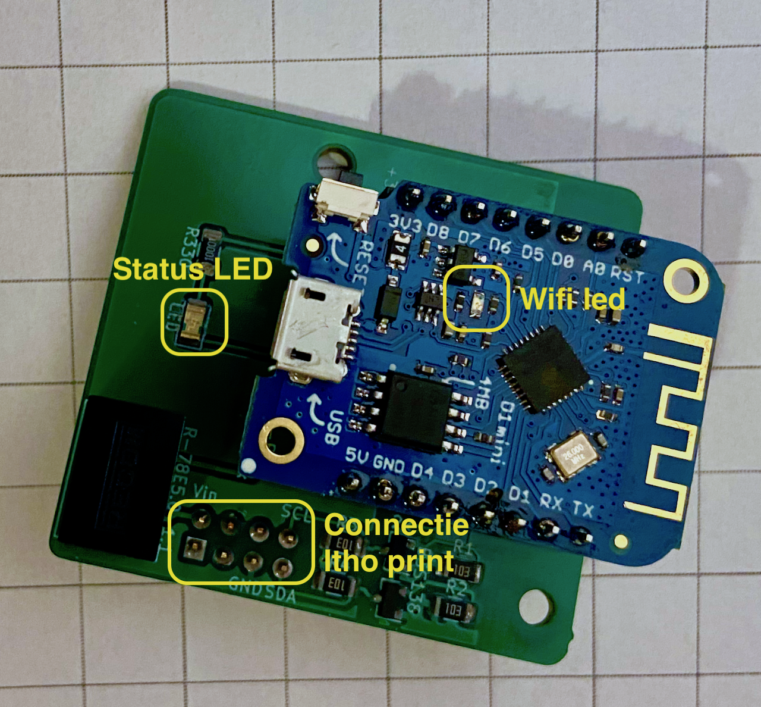
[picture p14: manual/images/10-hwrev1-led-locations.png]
Hardware revisie 1 — Status LED, Wifi led, Connectie itho print


**Hardware revisie 2 (nieuwe revisies met fail safe knop):**

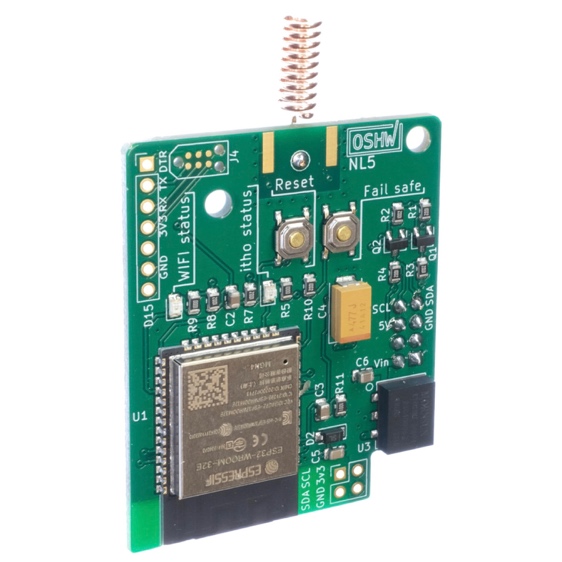
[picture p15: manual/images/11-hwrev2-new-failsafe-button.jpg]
Hardware revisie 2 met fail safe knop


**Hardware revisie 2 (oude revisies met failsafe soldeer optie):**

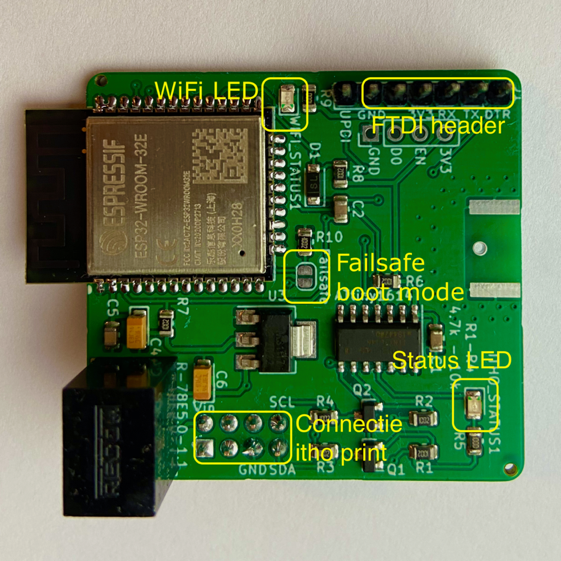
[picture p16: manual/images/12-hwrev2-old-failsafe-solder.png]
Hardware revisie 2 met failsafe soldeer optie


---

## Installatievoorbeeld

Installatie header voor de add-on in de rode cirkel.
Afhankelijk van de productiedatum van de Itho box, kan de print er iets anders uit zien.

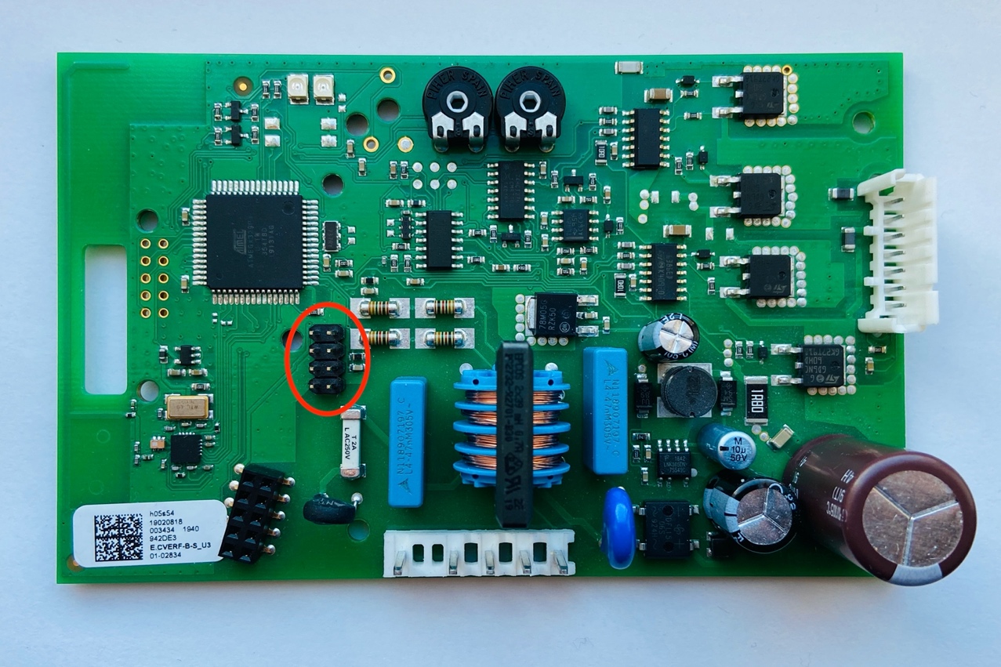
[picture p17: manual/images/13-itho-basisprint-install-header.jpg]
Itho basisprint met installatie header rood omcirkeld


Add-on correct geïnstalleerd:

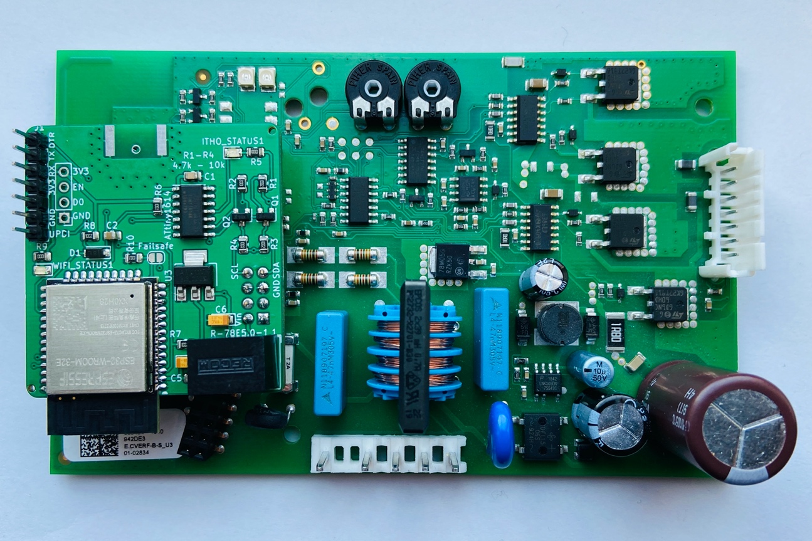
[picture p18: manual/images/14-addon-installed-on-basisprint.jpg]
Add-on correct geïnstalleerd op basisprint


---

## Node-RED automatiseringsvoorbeeld

Hieronder treft u een Node-red voorbeeld aan:

```json
[{"id":"78e45008.cda2f","type":"mqtt out","z":"79360772.4553e8","name":"itho","topic":"itho/cmd","qos":"0","retain":"true","broker":"b4eed736.102278","x":430,"y":1000,"wires":[]},{"id":"98cc2161.c3896","type":"inject","z":"79360772.4553e8","name":"itho level 127","topic":"","payload":"127","payloadType":"str","repeat":"","crontab":"","once":false,"onceDelay":0.1,"x":170,"y":1000,"wires":[["78e45008.cda2f"]]},{"id":"5a4ffa98.c88454","type":"inject","z":"79360772.4553e8","name":"itho level 254","topic":"","payload":"254","payloadType":"str","repeat":"","crontab":"","once":false,"onceDelay":0.1,"x":170,"y":1060,"wires":[["78e45008.cda2f"]]},{"id":"1e824b95.a04104","type":"inject","z":"79360772.4553e8","name":"itho level 0","topic":"","payload":"0","payloadType":"str","repeat":"","crontab":"","once":false,"onceDelay":0.1,"x":160,"y":940,"wires":[["78e45008.cda2f"]]},{"id":"b4eed736.102278","type":"mqtt-broker","z":"","name":"MQTT Server","broker":"192.168.1.2","port":"1883","clientid":"","usetls":false,"compatmode":false,"keepalive":"60","cleansession":true,"birthTopic":"","birthQos":"0","birthPayload":"","closeTopic":"","closeQos":"0","closePayload":"","willTopic":"","willQos":"0","willPayload":""}]
```

---

## Ondersteunde afstandsbedieningen

Itho afstandsbedieningen die werkend zijn getest:

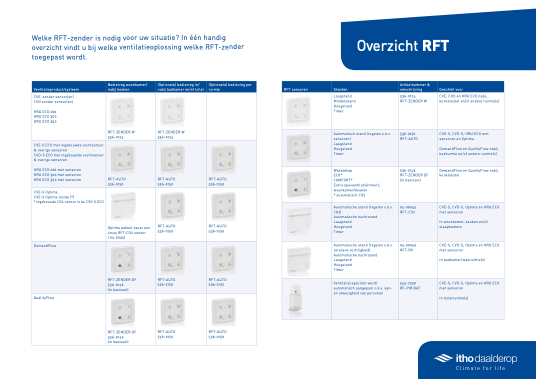
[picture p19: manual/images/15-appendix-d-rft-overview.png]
Overzicht RFT-zenders Itho Daalderop


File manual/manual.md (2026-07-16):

NRG.Watch logo

# Itho WiFi add-on — User Manual

**Version:** V1.13

**Date:** 14-06-2026

| | |
|---|---|
| CVE add-on revision 1.x | CVE add-on revision 2.x |
| **CVE add-on revision 1.x** | **CVE add-on revision 2.x** |
| Non-CVE add-on revision 1.x | |
| **Non-CVE add-on revision 1.x** | |

---

## Table of Contents

- [Foreword](#foreword)
- [Physical Installation CVE Add-on](#physical-installation-cve-add-on)
- [Physical Installation non-CVE Add-on](#physical-installation-non-cve-add-on)
- [Additional information for the HRU250 and HRU300](#additional-information-for-the-hru250-and-hru300)
- [Configuring the Add-on](#configuring-the-add-on)
- [Usage (Web interface, API)](#usage-web-interface-api)
- [Device-specific information](#device-specific-information)
- [Temperature/Humidity sensor](#temperaturehumidity-sensor)
- [Virtual Remote](#virtual-remote)
- [RF Module](#rf-module)
- [Updating firmware](#updating-firmware)
- [Resetting the module](#resetting-the-module)
- [Hmmm… where do I find more information?](#hmmm-where-do-i-find-more-information)
- [Hardware revisions](#hardware-revisions)
- [Installation example](#installation-example)
- [Node-red automation example](#node-red-automation-example)
- [Supported remotes](#supported-remotes)

---

## Foreword

Thank you for purchasing one (or more) add-on modules — enjoy using it!

An important warning first! Several Itho devices (at least the CVE's and the HRU200) are not touch-safe when powered, including the low-voltage parts. Therefore, always disconnect power from the device when installing an add-on on the circuit board. This prevents harm to yourself and to your Itho! If needed, operate the buttons on the CVE add-on circuit board only with a non-conductive material.

This is a concise manual to help you physically install the add-on and connect it to your own WiFi network. Information about further specific installations can be found online.

This manual, the plug-ins for e.g. Home Assistant and Homey, the wiki and further information online are a community effort — a collection of contributions from users for users. Without these contributions this document, among other things, would not exist. Additions, changes and/or suggestions are highly appreciated!

**Sources where further information can be found:**

- Wiki page: <https://github.com/arjenhiemstra/ithowifi/wiki>
- Tweakers.net forum: <https://gathering.tweakers.net/forum/list_message/82125986>
- Tweakers.net forum (WPU specific): <https://gathering.tweakers.net/forum/list_messages/2154474>
- Frequently asked questions: <https://gathering.tweakers.net/forum/list_messages/1976492/0#label-faq>

---

## Physical Installation CVE Add-on

To properly protect the add-on (PCB), we deliver it in an antistatic bag.

Below is a numbered list of steps to complete the installation of the add-on.

1. Take the add-on out of the antistatic bag;
2. Besides the add-on, you will also find a PCB spacer — set it aside for now.
3. Now disconnect power from the Itho ventilation unit by pulling the plug from the wall socket;
4. To reach the Itho's main board, remove the cover of the unit. This can be done by releasing the clips on the top and bottom with a flat screwdriver. You now see the housing that contains the main board; it is easily reached by opening the little door, or in case of a black cap it can be removed by combining some sideways pressure with an upward pulling motion. See the manufacturer's installation & user manual for any other/specific instructions;
5. Now place the PCB spacer with the curved / short side into the hole on the Itho main board that matches the hole on the add-on. Using this spacer reduces the chance of soldered joints vibrating loose over time. This step can optionally also be done after testing the add-on;
6. Placing the add-on requires no special tools or other materials.
   You can place the add-on by mounting it onto the 2×4 pin interface.
   See Installation example, circled in red, for where the 2×4 pin interface is located on the main board;
7. Now restore power to the Itho by inserting the plug into the wall socket.
8. If initialization is successful, the Itho status LED (see Hardware revisions) lights up briefly. After that it stays off. This indicates that communication between the Itho main board and the add-on has started successfully. The WiFi status LED will blink to indicate that an access point has been started.
9. The add-on is now installed; close the main board housing and place the cover back on the unit.

---

## Physical Installation non-CVE Add-on

To properly protect the add-on (PCB), we deliver it in an antistatic bag. If you ordered an enclosure with it, the add-on is already placed in the enclosure. Leave the add-on in the enclosure; removing the board from the enclosure can damage the enclosure.

Below is a numbered list of steps to complete the physical installation of the add-on.

1. If applicable, take the add-on out of the antistatic bag;
2. Find the COM/Service port on your Itho device. This is a connection that looks like a network port (RJ45 connector). Connect the add-on to the COM/Service port with a good, short (CAT6a, STP, 25cm) network cable;
3. The add-on is installed and will start an access point.

**Note.** Power for the add-on comes through the network cable from the connected Itho. In exceptional cases the Itho appears unable to supply enough power (certain revisions of the HRU300). As a result, communication with the HRU is not always stable. In that case, connect a USB power supply to the add-on. In all other cases this is not necessary.

---

## Additional information for the HRU250 and HRU300

To use the add-on with the HRU250 and HRU300, an adapter board and a PCI-e splitter cable are required.

To install these:

1. Remove the PCI-e cable from the HRU's HMI.
2. Connect the PCI-e cable of the HMI to the PCI-e splitter cable.
3. Connect one end of the splitter cable to the HMI, and the remaining end to the HRU250/300 adapter board.
4. The adapter board can be connected to the add-on with the network cable.

HRU250/300 adapter installation

### Controlling the HRU250 and HRU300

These models are somewhat more limited in control via the add-on compared to other Itho models. To control this HRU you must use the CC1101 RF module on the add-on. The Virtual Remote option does not work on these HRU models.

To use the RF module it must be activated via the add-on's web interface, under the "System settings" menu. After a reboot, an additional menu item named "RF Devices" appears. Here an RF device can be configured. This RF device must then be paired with the HRU. Follow the same procedure used to pair physical remotes.

---

## Configuring the Add-on

Below is a numbered list of steps to make the basic settings of the add-on.

### Configuring the add-on — *Connecting to the add-on*

1. After connecting, the add-on automatically starts a WiFi access point. The WiFi status LED then blinks once per second (see Hardware revisions).

   Note: as long as the add-on is not yet connected to your WiFi network, the access point stays active. Once the add-on is connected, the access point automatically switches off after the configured time (15 minutes by default). This time can be changed in the settings.

2. Connect your phone, tablet or computer to the add-on's WiFi network:
   - Network name (SSID): **nrg-itho-XXXX** (the last 4 characters are unique per add-on)
   - Password: **password**

3. Open a browser and go to:
   `http://nrg-itho-XXXX.local` (replace XXXX with the 4 characters from the network name)
   Doesn't work (e.g. on Android)? Then go to <http://192.168.4.1>

### Configuring the add-on — *Setup Wizard*

From firmware version 3.0 onward, a Setup Wizard automatically starts and guides you through the configuration in a number of steps:

**Step 1 — WiFi**

Enter the name (SSID) and password of your own WiFi network. Optionally you can set a custom hostname. Click Connect and wait until the connection is confirmed. Note the IP address that is shown — you need it to reach the add-on later from your own network.

**Step 2 — Device**

The wizard automatically detects which type of Itho device is connected (e.g. CVE-Silent, HRU 350, DemandFlow) and applies the most common default settings. For devices without an I2C connection (e.g. the HRU 400), the option to activate RF standalone mode is offered.

**Step 3 — RF** (skipped if no CC1101 RF module is present)

Here you configure the RF remotes. You can pair (join) a remote with the Itho device, or skip this step and set it up later via the "RF Devices" menu.

Working in RF-standalone mode (a device without I2C, for example the HRU 400)? Then this is the moment to pair an emulated RFT CO2 remote with the Itho — you then use it to control the device and read out its status.

**Step 4 — MQTT** (optional)

Enter the details of your MQTT server if you want to connect the add-on to Home Assistant, Domoticz or another home automation platform via MQTT. Optionally enable Home Assistant MQTT Auto Discovery so the add-on automatically appears as a device in Home Assistant.

**Step 5 — HA Discovery** (skipped if MQTT is not enabled)

Configure which sensors and status information are made available to Home Assistant via HA Auto Discovery.

### Configuring the add-on — *After the wizard*

Reconnect your phone/computer to your own WiFi network and open the browser at the IP address from the wizard.

All settings can also be changed afterwards via the web interface. The wizard does not need to be run again.

---

## Usage (Web interface, API)

The Itho unit can now be controlled via the web interface (<http://nrg-itho-A1B2.local>, replace A1B2), via MQTT or the WebAPI.

Do you want to connect the add-on to home automation via MQTT? Then you need an MQTT server (broker). Note that the web interface and the WebAPI also work without MQTT. If you don't have an MQTT server yet, the link below provides a good example of how to install one on, for example, a Raspberry Pi:

<https://randomnerdtutorials.com/how-to-install-mosquitto-broker-on-raspberry-pi/>

### Controlling the Itho

There are several ways to control the Itho and change its settings.

For CVE's and the HRU 200 there are 2 ways to control the speed: remote commands (virtual or RF) and the stepless PWM2I2C protocol. For other devices (for example the HRU 350) only the remote commands (virtual remote and/or RF remote) are available. For the HRU 250 and HRU 300 only RF remote commands work. To send RF remote commands the CC1101 RF module must be present on the add-on. Virtual remote commands (where the add-on emulates a physical remote) are sent via the physical I2C connection with the Itho.

What is exactly possible per device is described in the [Device-specific information](#device-specific-information) chapter.

More details about the various options and any limitations can be found on the wiki:

<https://github.com/arjenhiemstra/ithowifi/wiki/Controlling-the-speed-of-a-fan>

### Connecting to home automation software

The add-on can be connected to other devices and home automation via MQTT and the WebAPI. The details are described under the *Using the API* heading below.

For the most commonly used platforms there are ready-made integrations:

- **Home Assistant — MQTT Auto Discovery.** If you enable MQTT with Home Assistant MQTT Auto Discovery, the add-on is automatically configured as a device in Home Assistant with a basic configuration. This can be adjusted and extended manually.
- **Home Assistant — separate integrations.** In addition, there are two community integrations for Home Assistant:
  - [ithowifi-ha-integration](https://github.com/arjenhiemstra/ithowifi-ha-integration) — uses the REST API (local, basic).
  - [haithowifi](https://github.com/jasperslits/haithowifi) — uses the MQTT API (more extensive).
- **Homey.** The [Itho Daalderop app](https://homey.app/en-nl/app/nl.monkeysoft.nrgwatch/Itho-Daalderop/) in the Homey app store uses the WebAPI (REST); MQTT is not required for it.
- **Homebridge (Apple HomeKit).** The community plugin [Homebridge Itho Daalderop HUE](https://github.com/SanderBaron/homebridge-itho-daalderop-HUE) brings your CVE to Apple HomeKit. It talks to the add-on via the WebAPI or MQTT (MQTT recommended for instant updates) and optionally integrates with Philips Hue.
- **Domoticz and other platforms.** Integration is done via MQTT (or the WebAPI).

### Using the API (WebAPI and MQTT)

The add-on has two APIs with which you can read out and control the Itho, for example from your own scripts or home automation: a **WebAPI** (HTTP) and an **MQTT API**. Both accept the same commands.

The complete and always up-to-date list of endpoints and commands for your firmware version is in the web interface under the **API** menu (interactive documentation). The underlying OpenAPI specification can also be retrieved directly via `http://<add-on>/api/openapi.json`.

**WebAPI (HTTP)**

There are two variants:

- **REST API (v2)** — a JSON API under `/api/v2/…`. A selection of the endpoints:
  - `GET /api/v2/deviceinfo` — device and firmware information
  - `GET /api/v2/ithostatus` — all current status values
  - `GET /api/v2/speed` and `GET /api/v2/lastcmd` — current speed and last command
  - `GET /api/v2/remotes`, `/api/v2/vremotes` and `/api/v2/rfstatus` — (virtual) remotes and RF status
  - `GET` and `PUT /api/v2/settings` — read and change settings
  - `POST /api/v2/command` — send a command (for example a ventilation level)
  - `POST /api/v2/vremote` and `POST /api/v2/rfremote/command`, `/co2`, `/demand`, `/config` — virtual and RF remote commands
  - `POST /api/v2/wpu/outside_temp` and `/api/v2/wpu/manual_control` — WPU-specific
- **Legacy API (v1)** — a simple read-only API in query style via `/api.html`, for example:
  - `http://<add-on>/api.html?get=ithostatus`
  - `http://<add-on>/api.html?get=currentspeed` (other values: `lastcmd`, `queue`, `remotesinfo`)

  Reading and changing settings has moved to the REST API (`GET`/`PUT /api/v2/settings`).

**MQTT API**

If MQTT is configured, the add-on uses the topics below. The *base topic* is configurable (default `itho`):

- `itho/cmd` — publish your commands to the add-on here (same set as the WebAPI).
- `itho/cmd/response` — the add-on's response to a command.
- `itho/state` — the add-on publishes a JSON with all status values here.
- `itho/lwt` — the online/offline status of the add-on (Last Will & Testament).

A working example (Node-RED) that publishes to `itho/cmd` is in the [Node-red automation example](#node-red-automation-example).

---

## Device-specific information

The add-on automatically detects which Itho device is connected and adapts the available settings and readable status values accordingly. Below is described, per device (group), how it is controlled, which information the add-on reads out and what to watch out for.

In addition to the per-device control described below, the add-on can emulate an RFT CO2 remote for **every fan (CVE and HRU)** and for **DemandFlow**. After pairing it with the device, it can be controlled steplessly from 0–100%, in steps of half a percent. This works both with an I2C connection and in RF-standalone mode. Only with the CVE's can this RF communication be less reliable; see the *CVE family* section below.

> **Note:** which status values and settings are exactly available depends on the model and the firmware version of the Itho device. The web interface and the API page always show the current, complete list for your device. The values below are examples of what a device typically reports.

### CVE family (CVE, CVE-Silent, HRU 200)

**Models:** CVE, CVE-Silent and the HRU 200 (recognized in the web interface as *CVE-SilentExtPlus*). The CVE ECO2 and CVE-SilentExt are also recognized, but only provide basic status.

**Control:** these units communicate via the physical I2C connection on the main board. The speed can be controlled in two ways:

- **Remote commands** — a *virtual remote* emulated by the add-on, or a physical/RF remote (RF requires the CC1101 module).
- **PWM2I2C** — a stepless protocol for continuous control (0–100%). This is only available on the CVE's and the HRU 200, not on the other devices.

By default the add-on is in PWM2I2C mode; the remote mode can be set via *System settings*.

> **Note (models with a built-in CO2 sensor):** on CVE-S Optima Inside models with a built-in CO2 sensor, PWM2I2C does not work — the PWM2I2C commands are overruled by the internal CO2 sensor. Use virtual remote control on these models.

**What the add-on reads out (among others):** ventilation level/setpoint (%), requested and actual speed (rpm), selected mode, error code, startup counter, operating hours, **CO2 value (ppm)**, valve position and presence timer. Newer CVE's have a built-in humidity sensor — see the [Temperature/Humidity sensor](#temperaturehumidity-sensor) chapter.

The **CVE-Silent** additionally reports, among other things, the highest measured CO2 (ppm) and RH (%), the internal humidity (%) and temperature (°C), and absence timers. The **HRU 200** has the most extensive set of the family, additionally including filter usage (hours), outside and exhaust temperature, average outlet temperature, bypass mode and position, and the maximum CO2/RH levels.

> **Note (RF with CVE's):** on the CVE's the antennas of the add-on and the unit are close together. This can cause communication problems with RF control (such as an emulated RFT CO2 remote). On the CVE's, therefore, preferably use I2C control (virtual remote or PWM2I2C).

### HRU heat recovery via I2C (HRU 350, HRU ECO-fan)

**Models:** HRU 350 and HRU ECO-fan.

**Control:** via the I2C connection, with remote commands (virtual remote or RF). The stepless PWM2I2C protocol is **not** available on these models — only the remote modes/commands.

**What the add-on reads out (among others):** requested ventilation level (%), balance (%), supply and exhaust fan (both requested and actual speed), supply, exhaust, room and outside temperature (°C), valve and bypass position, frost and boiler timers, filter counter, global fault code, current mode, highest measured CO2 (ppm) and RH (%), air quality (%) and the remaining override timer. The HRU ECO-fan reports a comparable set around supply/exhaust, temperatures, bypass and filter usage.

> **DuoZone:** HRU units with two zones (DuoZone) are recognized; the zone data appears on the RF Status page of the web interface (and via `GET /api/v2/rfstatus`).

### HRU 250 / HRU 300

**Control:** these models are controlled and read out **exclusively via RF (CC1101)** — the Virtual Remote option does not work here. An RF remote must therefore be paired from the add-on.

**Special hardware:** an adapter board and a PCI-e splitter cable are required. The physical installation is described in the [Additional information for the HRU250 and HRU300](#additional-information-for-the-hru250-and-hru300) chapter. On some revisions of the HRU 300 the unit may supply too little power; in that case, connect a USB power supply to the add-on.

**What the add-on reads out (among others):** outside and mixed-air temperature (°C), supply and exhaust airflow (m³/h), inlet, exhaust and blown-out air temperature (°C), relative and absolute fan speed (%), the inbound and outbound mass flow (kg/h), bypass position (%), desired inlet temperature, extensive frost data, motor speed (rpm), the highest measured RH/CO2 and the fan's current consumption (mA).

### Devices without I2C — RF standalone (e.g. HRU 400)

Some units (for example the HRU 400) have no I2C connection usable by the add-on. For these there is **RF standalone mode**: the add-on skips I2C entirely and works only via RF (CC1101).

- **Activating:** the Setup Wizard offers this for devices without I2C; later it can also be done via *System settings*.
- The add-on can emulate an RFT CO2 remote. After it is paired with the HRU, the HRU can be controlled steplessly from 0–100% in steps of half a percent.
- With a paired, emulated RFT CO2 remote, the status (such as ventilation level and temperatures) can be requested periodically.

This mode requires a CC1101 RF module.

### DemandFlow

**Control:** via the I2C connection. DemandFlow is a demand-driven ventilation system with multiple rooms; control and read-out go via the web interface, MQTT and the WebAPI.

**What the add-on reads out (among others):** operating status and mode, relative humidity per bathroom (%), exhaust fan (%), CO2 in the plenum (ppm) plus the calculated CO2 per room (kitchen, toilet, living room, bedrooms, etc.), the calculated valve/flap positions and the calculated airflow per room (m³/h), and the error code.

### AutoTemp

**Models:** AutoTemp and AutoTemp Basic.

**Control:** via the I2C connection. AutoTemp is a zone control system (per room), for example for underfloor heating; control and read-out via the web interface, MQTT and the WebAPI.

**What the add-on reads out (among others):** mode, condition and error code, and per room (up to 12 rooms) the measured temperature, the setpoint and the delivered power (% and kW), plus the valve positions per manifold/zone.

### WPU (heat pump)

The WPU is a heat pump (referred to in the firmware as *Heatpump*), not a ventilation device. It has by far the most extensive set of readable values.

**Control:** via the I2C connection; read-out and settings via the web interface, MQTT and the WebAPI.

**What the add-on reads out (among others):** a large number of temperatures (outside, boiler top/bottom, evaporator, suction and compressed gas, liquid, source in/out, CV supply and return, °C), CV pressure (bar), the current consumption of the compressor and the electric element (A), pump speeds for CV, source and boiler (%), valve positions, the status of compressor/element/trickle heating, various timers and an error code with detailed error bytes.

> The error bytes are shown as raw values; a translation table to descriptions is not included in the add-on. Consult the Itho documentation for their meaning.

### Other recognized devices

The add-on also recognizes various other Itho devices by name (such as Air curtain, LoadBoiler, GGBB, CO2 relay, OLB, RF+, Extended (Plus), AreaFlow and RF_CO2). For these, the add-on shows basic information, but (as yet) no extensive settings or status list.

---

## Temperature/Humidity sensor

New Itho CVE units come standard with a humidity sensor. The add-on can read out this sensor.

CVE PCB with humidity sensor

Older Itho models without a humidity sensor can, with some tweaker skills, also be equipped with a temperature/humidity sensor.

The connections of the humidity sensor are as follows, and the corresponding connections on the add-on board are indicated with red markings and labels.

| | |
|---|---|
| Humidity sensor pinout diagram | Add-on PCB with SCL/SDA/3v3/GND marking |

Here you can find an example of a tweaker who did this successfully:

<https://gathering.tweakers.net/forum/list_message/66500576#66500576>

---

## Virtual Remote

The add-on can present itself as one or more **virtual remotes**. A virtual remote emulates a physical remote entirely in software and controls the Itho directly over the **I2C connection** (the wired connection on the main board) — so no CC1101 RF module is required.

**Which devices?** Virtual remotes work with the I2C-connected ventilation devices, such as the CVE family, the HRU 350 and the HRU ECO. Most fan devices benefit from at least one virtual remote for control. They do **not** work with the HRU 250, HRU 300 and HRU 400, which are controlled exclusively via RF (see [RF Module](#rf-module)).

**Pairing.** Like a physical remote, a virtual remote must first be joined to the Itho. The add-on can send a join command automatically (the *Send join command* option, on the next power-on).

**Difference from an emulated RF remote.** A *virtual remote* communicates with the Itho over the wired **I2C connection**; an *emulated RF remote* communicates **wirelessly via the CC1101 module** (868 MHz), just like a physical remote. Use a virtual remote for devices with an I2C connection, and an emulated RF remote for devices that only work via RF (HRU 250/300/400) or to emulate wireless sensors (such as RFT CO2).

---

## RF Module

RF functionality requires a CC1101 module on the add-on.

The CC1101 module can receive and send the RF signals of Itho remotes.
The most commonly sold Itho remotes are supported.

**Moving an existing remote to the add-on.** An existing physical remote can be moved to the add-on, so the add-on receives that remote's RF commands and translates them to the Itho. The remote is unpaired from the Itho and paired with the add-on, following the procedure below.

> **Note:** handling the RF commands of existing remotes via the add-on is not available for the HRU 250, HRU 300 and HRU 400. Monitoring RF communication is possible, however. Therefore, leave existing RF remotes paired with the Itho and pair the add-on as an additional remote with your HRU.

1. Unlearn the remote by sending a leave command within the first 2 minutes after powering on the Itho unit (on the remote you do this by pressing all 4 buttons simultaneously);
2. If you have not already done so, configure the add-on module further and (last) activate the RF module under the "System settings" menu;
3. The add-on reboots;
4. If the RF module is correctly detected, the option to manage Itho remotes appears in the same menu. Only add remotes after the Itho unit is out of learn/leave mode (so at least 2 minutes after powering on), otherwise the remote will be paired with the Itho again;
5. Put the add-on in learn/leave mode (via the web interface);
6. Send a learn command with your remote (usually press 2 diagonally opposite buttons simultaneously; otherwise see the manual of the specific remote);
7. If all goes well, your remote ID now appears in the first free position (see the image below). If it still does not succeed after several attempts, the remote may not (yet) be supported. In that case, contact support.

RF Remotes setup screenshot

**The add-on as an emulated RF remote.** The add-on can also present itself as an emulated RF remote: via the CC1101 module it behaves wirelessly like an Itho remote. With the *Remote function* set to **Send**, the add-on sends speed and timer commands to the Itho over the air. This is used for devices without a usable I2C connection (such as the HRU 250, HRU 300 and HRU 400) and to emulate, for example, an RFT CO2 sensor.

Before an emulated RF remote works, it must be joined to the Itho once — just like a physical remote. Put the Itho in its pairing/learn mode (see your Itho's manual) and start the join with the blue join button next to the relevant remote on the **RF devices** page. After that, the add-on can be used like a real physical remote.

**Note:** There is a debug option to make RF commands visible in the web interface. Set one of the following levels on the **Syslog** page, under *RF Debug log level*:

- **Level 1:** shows all recognized Itho remote commands incl. remote ID
- **Level 2:** shows all RF packets coming from a configured remote (see <https://github.com/arjenhiemstra/ithowifi/tree/master/remotes> for more details on how to use this)
- **Level 3:** shows all RF packets that are processed (this probably includes a lot of non-Itho-related packets)
- **Level 0:** turns the debug option off again

The RF log appears on the **Syslog** page once the first RF command has been received.

RF debug log screenshot

---

## Updating firmware

You can easily update the add-on's firmware via the web interface.

1. Open the web interface and go to the **Update** menu.
2. Choose which firmware you want to install:
   - **Stable** — the recommended, stable version.
   - **Beta** — the newest test version with the latest features (may still contain bugs).
3. Click the **Install** button.
4. The add-on automatically retrieves the chosen firmware from GitHub and installs it. Follow the progress on the page; once the update is done, the add-on automatically reboots.

With a normal update your settings are preserved. Only a factory reset erases the configuration (see [Resetting the module](#resetting-the-module)).

**Progress in Home Assistant.** Both Home Assistant integrations — the REST and the MQTT one — show the add-on as an *update entity*; during an update the progress is shown as a progress bar.

**Uploading a firmware file yourself.** If the automatic retrieval does not work (for example without an internet connection), you can also manually upload a `.bin` firmware file on the Update page. The same can be done via the emergency firmware after a failsafe boot (see [Resetting the module](#resetting-the-module)).

---

## Resetting the module

### Fail safe boot / module factory reset

Should it unexpectedly happen that the module is no longer reachable due to an incorrect configuration, it is possible to boot the module in fail safe mode. This formats the file system with the configuration files, and the module starts a simplified web interface with which it is possible to flash new firmware.

The procedure for this reset is as follows:

1. press the reset button
2. wait until the WiFi status LED starts blinking rapidly (2x per sec)
3. then, within 2 sec, press the "Fail save" (on some revisions "default") button
4. shortly after, the WiFi LED will start blinking once per second
5. If you do not want to flash new firmware, skip this step.
   The add-on has now started an access point with a simplified "emergency" firmware. With this, only new firmware can be flashed. The web page can be reached at the following address: <http://192.168.4.1/update>
   Uploading new firmware can take a minute; wait calmly until the page refreshes and shows the result.
6. press the reset button

After this, all settings are erased and the add-on will start in factory default mode.

There is also a YouTube video available that shows this procedure:
<https://youtu.be/3sWclzq73n4>

This method is only available when using 'official' firmware, or firmware based on it.

**Hardware revisions up to 2.5** (see the back of the add-on):

To activate this mode for hardware revisions up to version 2.5, a different procedure must be followed:

Connect the two metal pads labelled 'failsafe' on the board to each other. This is easiest with a soldering iron and a bit of solder, or by connecting the pads with, for example, a screwdriver.

When powering on the Itho with the add-on installed, the add-on will perform the fail save procedure and remove all settings. New firmware can optionally also be loaded as described earlier.

After this procedure, remove any solder connection that is present, and put the module back into use as described in this manual.

---

## Hmmm… where do I find more information?

There is an enormous amount of useful information on the wiki:
<https://github.com/arjenhiemstra/ithowifi/wiki>
It is for users and by users. Feel free to make changes here too.

On tweakers.net there is a thread on the forum about this add-on.
It also contains more information about using this add-on in combination with e.g. Home Assistant, Domoticz and other systems.

You can also go there for questions.
The link is: <https://gathering.tweakers.net/forum/list_messages/1976492/0>

For further questions, feedback and code changes, you can get in touch via <info@nrgwatch.nl> or <https://www.github.com/arjenhiemstra/ithowifi>.

---

## Hardware revisions

Images may differ slightly from the product you received; the operation is identical.

**Hardware revision 1:**

Hardware revision 1 — Status LED, WiFi LED, connection to Itho board

**Hardware revision 2 (newer revisions with fail safe button):**

Hardware revision 2 with fail safe button

**Hardware revision 2 (older revisions with failsafe solder option):**

Hardware revision 2 with failsafe solder option

---

## Installation example

Installation header for the add-on in the red circle.
Depending on the production date of the Itho box, the board may look slightly different.

Itho main board with installation header circled in red

Add-on correctly installed:

Add-on correctly installed on the main board

---

## Node-red automation example

Below is a Node-RED example:

```json
[{"id":"78e45008.cda2f","type":"mqtt out","z":"79360772.4553e8","name":"itho","topic":"itho/cmd","qos":"0","retain":"true","broker":"b4eed736.102278","x":430,"y":1000,"wires":[]},{"id":"98cc2161.c3896","type":"inject","z":"79360772.4553e8","name":"itho level 127","topic":"","payload":"127","payloadType":"str","repeat":"","crontab":"","once":false,"onceDelay":0.1,"x":170,"y":1000,"wires":[["78e45008.cda2f"]]},{"id":"5a4ffa98.c88454","type":"inject","z":"79360772.4553e8","name":"itho level 254","topic":"","payload":"254","payloadType":"str","repeat":"","crontab":"","once":false,"onceDelay":0.1,"x":170,"y":1060,"wires":[["78e45008.cda2f"]]},{"id":"1e824b95.a04104","type":"inject","z":"79360772.4553e8","name":"itho level 0","topic":"","payload":"0","payloadType":"str","repeat":"","crontab":"","once":false,"onceDelay":0.1,"x":160,"y":940,"wires":[["78e45008.cda2f"]]},{"id":"b4eed736.102278","type":"mqtt-broker","z":"","name":"MQTT Server","broker":"192.168.1.2","port":"1883","clientid":"","usetls":false,"compatmode":false,"keepalive":"60","cleansession":true,"birthTopic":"","birthQos":"0","birthPayload":"","closeTopic":"","closeQos":"0","closePayload":"","willTopic":"","willQos":"0","willPayload":""}]
```

---

## Supported remotes

Itho remotes that have been tested working:

Overview of Itho Daalderop RFT transmitters

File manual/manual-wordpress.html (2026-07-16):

NRG.Watch

Nederlands English

🖨 Print / PDF

# Itho WiFi add-on — Gebruikershandleiding

Versie: V1.13

Datum: 14-06-2026

CVE add-on revisie 1.x | CVE add-on revisie 2.x
CVE add-on revisie 1.x | CVE add-on revisie 2.x
Non-CVE add-on revisie 1.x
Non-CVE add-on revisie 1.x

## Voorwoord

Bedankt voor de aanschaf van een (of meerdere) add-on modules, veel plezier met het gebruik!

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

Bronnen waar verdere informatie te vinden is:

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

## Fysieke Installatie CVE Add-on

Om de add-on (PCB) goed te beschermen, leveren wij deze in een antistatisch zakje.

Hieronder volgt een genummerde lijst met handelingen, om de installatie van de add-on te realiseren.

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

## Fysieke Installatie non-CVE Add-on

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

## Extra informatie voor de HRU250 en HRU300

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

Om deze te installeren:

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

HRU250/300 adapter installatie

### Bediening van de HRU250 en HRU300

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

## Add-on Instellen

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

### Add-on instellen — Verbinden met de add-on

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

### Add-on instellen — Setup Wizard

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

Stap 1 — WiFi

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

Stap 2 — Device

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

Stap 3 — RF (wordt overgeslagen als er geen CC1101 RF module aanwezig is)

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

Stap 4 — MQTT (optioneel)

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

Stap 5 — HA Discovery (wordt overgeslagen als MQTT niet is ingeschakeld)

Configureer welke sensoren en statusinformatie via HA Auto Discovery beschikbaar worden gesteld aan Home Assistant.

### Add-on instellen — Na de wizard

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

## Gebruik (Webinterface, API)

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

https://randomnerdtutorials.com/how-to-install-mosquitto-broker-on-raspberry-pi/

### Itho bedienen

Er zijn verschillende mogelijkheden om de Itho te bedienen en de settings aan te passen.

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

Wat per apparaat precies mogelijk is, staat in het hoofdstuk Apparaat-specifieke informatie.

Meer details over de verschillende mogelijkheden en de eventuele beperkingen zijn op de wiki te vinden:

https://github.com/arjenhiemstra/ithowifi/wiki/Controlling-the-speed-of-a-fan

### Koppeling met Home Domotica software

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

Voor de meest gebruikte platforms zijn er kant-en-klare integraties:

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

### De API gebruiken (WebAPI en MQTT)

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

WebAPI (HTTP)

Er zijn twee varianten:

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

MQTT API

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

Een werkend voorbeeld (Node-RED) dat naar itho/cmd publiceert, staat in het Node-RED automatiseringsvoorbeeld.

## Apparaat-specifieke informatie

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

### CVE-familie (CVE, CVE-Silent, HRU 200)

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

### HRU warmteterugwinning via I2C (HRU 350, HRU ECO-fan)

Modellen: HRU 350 en HRU ECO-fan.

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

### HRU 250 / HRU 300

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

### Apparaten zonder I2C — RF-standalone (bijv. HRU 400)

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

Voor deze modus is een CC1101 RF-module vereist.

### DemandFlow

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

### AutoTemp

Modellen: AutoTemp en AutoTemp Basic.

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

### WPU (warmtepomp)

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

Aansturing: via de I2C-verbinding; uitlezing en instellingen via de web interface, MQTT en de WebAPI.

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

### Overige herkende apparaten

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

## Temperatuur/Vochtsensor

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

CVE PCB met vochtsensor

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

Vochtsensor pinout diagram | Add-on PCB met SCL/SDA/3v3/GND markering

Hier is een voorbeeld te vinden van een tweaker die dit succesvol heeft gedaan:

https://gathering.tweakers.net/forum/list_message/66500576#66500576

## Virtual Remote

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

## RF-Module

Voor RF-functionaliteit is een CC1101-module op de add-on nodig.

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

RF Remotes setup screenshot

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

De RF-log verschijnt op de Syslog pagina zodra het eerste RF-commando ontvangen is.

RF debug log screenshot

## Firmware bijwerken

De firmware van de add-on werk je eenvoudig bij via de web interface.

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

## Module resetten

### Fail safe boot / module factory reset

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

De procedure voor deze reset is als volgt:

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

hierna zijn alle instellingen gewist en zal de add-on in factory default mode starten.

Er is ook een youtube filmpje beschikbaar die deze procedure laat zien: https://youtu.be/3sWclzq73n4

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

Hardware revisies t/m 2.5 (zie achterkant add-on):

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

## Hmmm, maar…. Waar vind ik verdere informatie?

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

## Hardware revisies

Afbeeldingen kunnen iets afwijken met het product dat u ontvangen heeft, de werking is echter gelijk.

Hardware revisie 1:

Hardware revisie 1 — Status LED, Wifi led, Connectie itho print

Hardware revisie 2 (nieuwe revisies met fail safe knop):

Hardware revisie 2 met fail safe knop

Hardware revisie 2 (oude revisies met failsafe soldeer optie):

Hardware revisie 2 met failsafe soldeer optie

## Installatievoorbeeld

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

Itho basisprint met installatie header rood omcirkeld

Add-on correct geïnstalleerd:

Add-on correct geïnstalleerd op basisprint

## Node-RED automatiseringsvoorbeeld

Hieronder treft u een Node-red voorbeeld aan:

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

## Ondersteunde afstandsbedieningen

Itho afstandsbedieningen die werkend zijn getest:

Overzicht RFT-zenders Itho Daalderop

# Itho WiFi add-on — User Manual

Version: V1.13

Date: 14-06-2026

CVE add-on revision 1.x | CVE add-on revision 2.x
CVE add-on revision 1.x | CVE add-on revision 2.x
Non-CVE add-on revision 1.x
Non-CVE add-on revision 1.x

## Foreword

Thank you for purchasing one (or more) add-on modules — enjoy using it!

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

Sources where further information can be found:

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

## Physical Installation CVE Add-on

To properly protect the add-on (PCB), we deliver it in an antistatic bag.

Below is a numbered list of steps to complete the installation of the add-on.

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

## Physical Installation non-CVE Add-on

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

Below is a numbered list of steps to complete the physical installation of the add-on.

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

## Additional information for the HRU250 and HRU300

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

To install these:

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

HRU250/300 adapter installation

### Controlling the HRU250 and HRU300

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

## Configuring the Add-on

Below is a numbered list of steps to make the basic settings of the add-on.

### Configuring the add-on — Connecting to the add-on

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

### Configuring the add-on — Setup Wizard

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

Step 1 — WiFi

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

Step 2 — Device

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

Step 3 — RF (skipped if no CC1101 RF module is present)

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

Step 4 — MQTT (optional)

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

Step 5 — HA Discovery (skipped if MQTT is not enabled)

Configure which sensors and status information are made available to Home Assistant via HA Auto Discovery.

### Configuring the add-on — After the wizard

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

## Usage (Web interface, API)

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

https://randomnerdtutorials.com/how-to-install-mosquitto-broker-on-raspberry-pi/

### Controlling the Itho

There are several ways to control the Itho and change its settings.

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

What is exactly possible per device is described in the Device-specific information chapter.

More details about the various options and any limitations can be found on the wiki:

https://github.com/arjenhiemstra/ithowifi/wiki/Controlling-the-speed-of-a-fan

### Connecting to home automation software

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

For the most commonly used platforms there are ready-made integrations:

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

### Using the API (WebAPI and MQTT)

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

WebAPI (HTTP)

There are two variants:

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

Reading and changing settings has moved to the REST API (GET/PUT /api/v2/settings).

MQTT API

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

## Device-specific information

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

### CVE family (CVE, CVE-Silent, HRU 200)

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

What the add-on reads out (among others): ventilation level/setpoint (%), requested and actual speed (rpm), selected mode, error code, startup counter, operating hours, CO2 value (ppm), valve position and presence timer. Newer CVE's have a built-in humidity sensor — see the Temperature/Humidity sensor chapter.

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

### HRU heat recovery via I2C (HRU 350, HRU ECO-fan)

Models: HRU 350 and HRU ECO-fan.

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

### HRU 250 / HRU 300

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

### Devices without I2C — RF standalone (e.g. HRU 400)

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

This mode requires a CC1101 RF module.

### DemandFlow

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

### AutoTemp

Models: AutoTemp and AutoTemp Basic.

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

### WPU (heat pump)

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

### Other recognized devices

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

## Temperature/Humidity sensor

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

CVE PCB with humidity sensor

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

Humidity sensor pinout diagram | Add-on PCB with SCL/SDA/3v3/GND marking

Here you can find an example of a tweaker who did this successfully:

https://gathering.tweakers.net/forum/list_message/66500576#66500576

## Virtual Remote

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

## RF Module

RF functionality requires a CC1101 module on the add-on.

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

RF Remotes setup screenshot

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

The RF log appears on the Syslog page once the first RF command has been received.

RF debug log screenshot

## Updating firmware

You can easily update the add-on's firmware via the web interface.

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

## Resetting the module

### Fail safe boot / module factory reset

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

The procedure for this reset is as follows:

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

After this, all settings are erased and the add-on will start in factory default mode.

There is also a YouTube video available that shows this procedure: https://youtu.be/3sWclzq73n4

This method is only available when using 'official' firmware, or firmware based on it.

Hardware revisions up to 2.5 (see the back of the add-on):

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

## Hmmm… where do I find more information?

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

## Hardware revisions

Images may differ slightly from the product you received; the operation is identical.

Hardware revision 1:

Hardware revision 1 — Status LED, WiFi LED, connection to Itho board

Hardware revision 2 (newer revisions with fail safe button):

Hardware revision 2 with fail safe button

Hardware revision 2 (older revisions with failsafe solder option):

Hardware revision 2 with failsafe solder option

## Installation example

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

Itho main board with installation header circled in red

Add-on correctly installed:

Add-on correctly installed on the main board

## Node-red automation example

Below is a Node-RED example:

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

## Supported remotes

Itho remotes that have been tested working:

Overview of Itho Daalderop RFT transmitters

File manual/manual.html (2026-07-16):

# Itho WiFi add-on — Gebruikershandleiding

Versie: V1.13

Datum: 14-06-2026

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

## Inhoudsopgave

- Voorwoord
- Fysieke Installatie CVE Add-on
- Fysieke Installatie non-CVE Add-on
- Extra informatie voor de HRU250 en HRU300
- Add-on Instellen
- Gebruik (Webinterface, API)
- Apparaat-specifieke informatie
- Temperatuur/Vochtsensor
- Virtual Remote
- RF-Module
- Firmware bijwerken
- Module resetten
- Hmmm, maar…. Waar vind ik verdere informatie?
- Hardware revisies
- Installatievoorbeeld
- Node-RED automatiseringsvoorbeeld
- Ondersteunde afstandsbedieningen

## Voorwoord

Bedankt voor de aanschaf van een (of meerdere) add-on modules, veel plezier met het gebruik!

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

Bronnen waar verdere informatie te vinden is:

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

## Fysieke Installatie CVE Add-on

Om de add-on (PCB) goed te beschermen, leveren wij deze in een antistatisch zakje.

Hieronder volgt een genummerde lijst met handelingen, om de installatie van de add-on te realiseren.

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

## Fysieke Installatie non-CVE Add-on

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

## Extra informatie voor de HRU250 en HRU300

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

Om deze te installeren:

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

### Bediening van de HRU250 en HRU300

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

## Add-on Instellen

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

### Add-on instellen — Verbinden met de add-on

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

### Add-on instellen — Setup Wizard

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

Stap 1 — WiFi

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

Stap 2 — Device

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

Stap 3 — RF (wordt overgeslagen als er geen CC1101 RF module aanwezig is)

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

Stap 4 — MQTT (optioneel)

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

Stap 5 — HA Discovery (wordt overgeslagen als MQTT niet is ingeschakeld)

Configureer welke sensoren en statusinformatie via HA Auto Discovery beschikbaar worden gesteld aan Home Assistant.

### Add-on instellen — Na de wizard

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

## Gebruik (Webinterface, API)

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

https://randomnerdtutorials.com/how-to-install-mosquitto-broker-on-raspberry-pi/

### Itho bedienen

Er zijn verschillende mogelijkheden om de Itho te bedienen en de settings aan te passen.

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

Wat per apparaat precies mogelijk is, staat in het hoofdstuk Apparaat-specifieke informatie.

Meer details over de verschillende mogelijkheden en de eventuele beperkingen zijn op de wiki te vinden:

https://github.com/arjenhiemstra/ithowifi/wiki/Controlling-the-speed-of-a-fan

### Koppeling met Home Domotica software

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

Voor de meest gebruikte platforms zijn er kant-en-klare integraties:

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

### De API gebruiken (WebAPI en MQTT)

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

WebAPI (HTTP)

Er zijn twee varianten:

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

MQTT API

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

Een werkend voorbeeld (Node-RED) dat naar itho/cmd publiceert, staat in het Node-RED automatiseringsvoorbeeld.

## Apparaat-specifieke informatie

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

### CVE-familie (CVE, CVE-Silent, HRU 200)

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

### HRU warmteterugwinning via I2C (HRU 350, HRU ECO-fan)

Modellen: HRU 350 en HRU ECO-fan.

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

### HRU 250 / HRU 300

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

### Apparaten zonder I2C — RF-standalone (bijv. HRU 400)

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

Voor deze modus is een CC1101 RF-module vereist.

### DemandFlow

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

### AutoTemp

Modellen: AutoTemp en AutoTemp Basic.

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

### WPU (warmtepomp)

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

Aansturing: via de I2C-verbinding; uitlezing en instellingen via de web interface, MQTT en de WebAPI.

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

### Overige herkende apparaten

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

## Temperatuur/Vochtsensor

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

Hier is een voorbeeld te vinden van een tweaker die dit succesvol heeft gedaan:

https://gathering.tweakers.net/forum/list_message/66500576#66500576

## Virtual Remote

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

## RF-Module

Voor RF-functionaliteit is een CC1101-module op de add-on nodig.

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

De RF-log verschijnt op de Syslog pagina zodra het eerste RF-commando ontvangen is.

## Firmware bijwerken

De firmware van de add-on werk je eenvoudig bij via de web interface.

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

## Module resetten

### Fail safe boot / module factory reset

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

De procedure voor deze reset is als volgt:

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

hierna zijn alle instellingen gewist en zal de add-on in factory default mode starten.

Er is ook een youtube filmpje beschikbaar die deze procedure laat zien: https://youtu.be/3sWclzq73n4

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

Hardware revisies t/m 2.5 (zie achterkant add-on):

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

## Hmmm, maar…. Waar vind ik verdere informatie?

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

## Hardware revisies

Afbeeldingen kunnen iets afwijken met het product dat u ontvangen heeft, de werking is echter gelijk.

Hardware revisie 1:

Hardware revisie 2 (nieuwe revisies met fail safe knop):

Hardware revisie 2 (oude revisies met failsafe soldeer optie):

## Installatievoorbeeld

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

Add-on correct geïnstalleerd:

## Node-RED automatiseringsvoorbeeld

Hieronder treft u een Node-red voorbeeld aan:

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

## Ondersteunde afstandsbedieningen

Itho afstandsbedieningen die werkend zijn getest:

# Itho WiFi add-on — User Manual

Version: V1.13

Date: 14-06-2026

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

## Table of Contents

- Foreword
- Physical Installation CVE Add-on
- Physical Installation non-CVE Add-on
- Additional information for the HRU250 and HRU300
- Configuring the Add-on
- Usage (Web interface, API)
- Device-specific information
- Temperature/Humidity sensor
- Virtual Remote
- RF Module
- Updating firmware
- Resetting the module
- Hmmm… where do I find more information?
- Hardware revisions
- Installation example
- Node-red automation example
- Supported remotes

## Foreword

Thank you for purchasing one (or more) add-on modules — enjoy using it!

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

Sources where further information can be found:

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

## Physical Installation CVE Add-on

To properly protect the add-on (PCB), we deliver it in an antistatic bag.

Below is a numbered list of steps to complete the installation of the add-on.

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

## Physical Installation non-CVE Add-on

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

Below is a numbered list of steps to complete the physical installation of the add-on.

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

## Additional information for the HRU250 and HRU300

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

To install these:

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

### Controlling the HRU250 and HRU300

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

## Configuring the Add-on

Below is a numbered list of steps to make the basic settings of the add-on.

### Configuring the add-on — Connecting to the add-on

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

### Configuring the add-on — Setup Wizard

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

Step 1 — WiFi

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

Step 2 — Device

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

Step 3 — RF (skipped if no CC1101 RF module is present)

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

Step 4 — MQTT (optional)

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

Step 5 — HA Discovery (skipped if MQTT is not enabled)

Configure which sensors and status information are made available to Home Assistant via HA Auto Discovery.

### Configuring the add-on — After the wizard

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

## Usage (Web interface, API)

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

https://randomnerdtutorials.com/how-to-install-mosquitto-broker-on-raspberry-pi/

### Controlling the Itho

There are several ways to control the Itho and change its settings.

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

What is exactly possible per device is described in the Device-specific information chapter.

More details about the various options and any limitations can be found on the wiki:

https://github.com/arjenhiemstra/ithowifi/wiki/Controlling-the-speed-of-a-fan

### Connecting to home automation software

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

For the most commonly used platforms there are ready-made integrations:

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

### Using the API (WebAPI and MQTT)

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

WebAPI (HTTP)

There are two variants:

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

Reading and changing settings has moved to the REST API (GET/PUT /api/v2/settings).

MQTT API

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

## Device-specific information

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

### CVE family (CVE, CVE-Silent, HRU 200)

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

### HRU heat recovery via I2C (HRU 350, HRU ECO-fan)

Models: HRU 350 and HRU ECO-fan.

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

### HRU 250 / HRU 300

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

### Devices without I2C — RF standalone (e.g. HRU 400)

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

This mode requires a CC1101 RF module.

### DemandFlow

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

### AutoTemp

Models: AutoTemp and AutoTemp Basic.

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

### WPU (heat pump)

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

### Other recognized devices

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

## Temperature/Humidity sensor

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

Here you can find an example of a tweaker who did this successfully:

https://gathering.tweakers.net/forum/list_message/66500576#66500576

## Virtual Remote

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

## RF Module

RF functionality requires a CC1101 module on the add-on.

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

The RF log appears on the Syslog page once the first RF command has been received.

## Updating firmware

You can easily update the add-on's firmware via the web interface.

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

## Resetting the module

### Fail safe boot / module factory reset

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

The procedure for this reset is as follows:

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

After this, all settings are erased and the add-on will start in factory default mode.

There is also a YouTube video available that shows this procedure: https://youtu.be/3sWclzq73n4

This method is only available when using 'official' firmware, or firmware based on it.

Hardware revisions up to 2.5 (see the back of the add-on):

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

## Hmmm… where do I find more information?

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

## Hardware revisions

Images may differ slightly from the product you received; the operation is identical.

Hardware revision 1:

Hardware revision 2 (newer revisions with fail safe button):

Hardware revision 2 (older revisions with failsafe solder option):

## Installation example

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

Add-on correctly installed:

## Node-red automation example

Below is a Node-RED example:

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

## Supported remotes

Itho remotes that have been tested working:

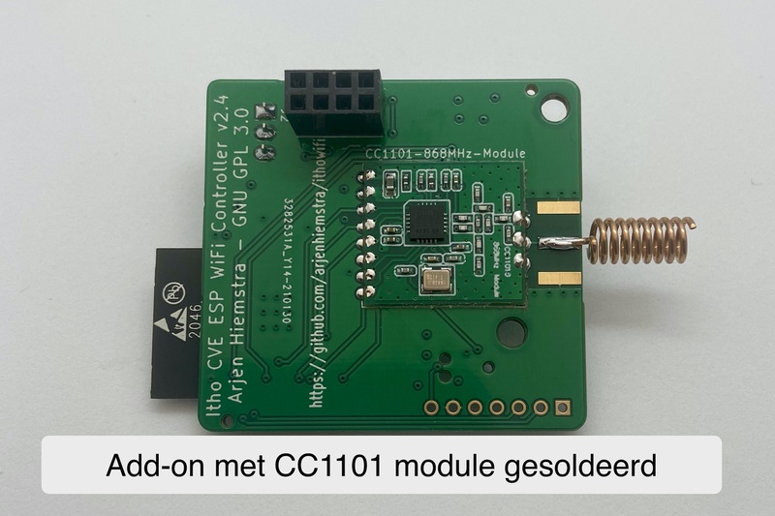
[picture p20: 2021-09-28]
images/wiki/with_cc1101_installed.jpg

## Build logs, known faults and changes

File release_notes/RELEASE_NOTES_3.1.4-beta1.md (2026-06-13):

# Version 3.1.4-beta1

This is a beta release focused on stability fixes that surfaced after 3.1.3 went out. Most users should be safe to install; users on WPU units in particular benefit. Please report back via GitHub issues if you see anything unexpected.

## Highlights

- **Memory stability**: long-running units no longer suffer slow heap erosion that eventually triggers `SDIO_RESET` after a few days of uptime. Verified on a CVE-Silent test unit running ~14 days continuously without reset since the fixes were applied.
- **WPU status reliability**: addresses the "status sometimes there, sometimes not" complaint reported with 3.1.3. A boot-time `QueryStatusFormat` race could leave the device in a state where the status board never populated until the next reboot. Now retried automatically and a partial / corrupt I2C reply no longer wipes a previously-good status list.

## Bug fixes

### Memory & heap

- Skip WebSocket `systemstat` broadcasts when no clients are connected — every broadcast otherwise allocated a per-client buffer + deque node, accumulating fragmentation over days even when nobody was listening.
- WebSocket broadcast now bails out when free heap drops below 80 KB, preventing fragmentation spirals during transient memory pressure.
- `notifyClients` switched to `std::nothrow` allocation so a failed allocation degrades gracefully instead of throwing.
- MQTT publish buffer is now grow-only — repeated realloc cycles between the default and a larger size were a major source of long-term heap fragmentation.
- HA Discovery publish skipped when free heap is below 100 KB. Fixes a crash path where an already-low-heap device cascaded into `SDIO_RESET` while building the (large) discovery JSON.
- WebSocket queued-message cap reduced from 64 to 8.
- REST `503` log now includes free heap and largest-block size for diagnosis.

### I2C status reliability

- `QueryStatusFormat` is retried once at boot if the first attempt returned 0 entries. Previously a transient mutex-contention or partial I2C reply at boot would leave the status board permanently empty until the user rebooted manually.
- Status-format parsing now happens into a local list and is only swapped into the live state if the new reply has at least one entry. A 0-length / corrupt reply at runtime no longer wipes the previous (good) data.
- Same defensive 0-length check added to the 31DA and 31D9 paths.
- Mutex acquire timeout raised from 100 ms to 500 ms for the `QueryStatusFormat`, `QueryStatus`, `Query31DA`, and `Query31D9` paths. Failure to acquire now logs a warning instead of silently dropping the update.

### Cosmetic / diagnostic

- The `RF: TX power 0x... for Send remotes` log line and the corresponding remote-flash write are now skipped on units without a CC1101 module — the value was meaningless and the log line was confusing on I2C-only setups.

## Known issues / not addressed in this release

- CVE ECO 2 SP fan control after upgrade ([#364](https://github.com/arjenhiemstra/ithowifi/issues/364) / [#365](https://github.com/arjenhiemstra/ithowifi/issues/365)): if your fan does not respond to the speed slider, please confirm **System Settings → Enable/Disable I2C commands → CVE fan control (PWM2I2C)** is set to **on**. We are still investigating whether anything in the firmware needs to change beyond this user setting.

## How to test

If you upgrade and notice anything off, please open a GitHub issue with:
- Your `/api/v2/deviceinfo` output
- The first ~50 lines of the System Log after a fresh boot (so we can see `QueryDevicetype`, `QueryStatusFormat - items:N`, etc.)
- A description of what you expected vs. what you saw

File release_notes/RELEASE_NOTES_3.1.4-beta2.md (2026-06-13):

# Version 3.1.4-beta2

Hotfix on top of [3.1.4-beta1](https://github.com/arjenhiemstra/ithowifi/releases/tag/Version-3.1.4-beta1). All beta1 fixes still apply — see those release notes for the full list.

## Bug fix

- **RF CO2 mode: demand slider on the index page now works in both directions.** When dragging the index-page slider down (to a lower demand), the unit previously kept running at the higher previous value. Same bug affected the REST `percentage` / `fandemand` endpoints (used by the Home Assistant integration) and the MQTT command path.
  - Root cause: an "auto" RF command was sent immediately before the 31E0 demand frame; the RFT CO2 unit then treated the demand as an upward-only boost relative to its current state and ignored values lower than the previous one.
  - Fix: send only the 31E0 demand command, matching the RF devices page (which never had this bug).

If you installed beta1 in RF CO2 mode and noticed "fan stuck at higher speed", this is the fix.

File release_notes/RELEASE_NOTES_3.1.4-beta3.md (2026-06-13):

# Version 3.1.4-beta3

Iterative beta on top of 3.1.4-beta2. Two functional changes, plus diagnostics that will help us close out [#365](https://github.com/arjenhiemstra/ithowifi/issues/365) (CVE ECO 2 SP fan control after power cycle).

## Bug fix

- **RF CO2 demand dispatch now respects the unit's current mode.** The 3.1.4-beta2 fix removed the unconditional `auto` precursor before the 31E0 demand frame. That fixed "drag slider down while in auto" but broke "drag slider while not in auto", because the unit only accepts a 31E0 frame when in auto mode. This release reads the unit's `FanInfo` (from the I2C 31DA path when `itho_31da` is enabled, or from a tracked RF 31DA source in RF-standalone mode) and only precedes the demand with an `auto` command when the unit isn't already in auto. If `FanInfo` is unknown (no 31DA polling configured), the firmware errs on the side of sending `auto + demand`, matching pre-3.1.4-beta2 behaviour for that case.

  Affects:
  - Web UI index-page demand slider (RF CO2 mode)
  - `POST /api/v2/command` with `percentage` or `fandemand` (the path used by the HA integration)
  - MQTT `cmd` topic with `percentage` or `fandemand`

  For RF-standalone setups, configure an **RF status source** (or enable I2C 31DA polling) so the firmware can see the unit's current mode and pick the optimised path. Without it the firmware always sends `auto + demand`, which works but re-introduces the boost-mode side-effect when the unit was already in auto.

## Diagnostics (no behaviour change)

Investigating the CVE ECO 2 SP "fan stops responding to slider after a power cycle" reports in [#346](https://github.com/arjenhiemstra/ithowifi/issues/346) / [#364](https://github.com/arjenhiemstra/ithowifi/issues/364) / [#365](https://github.com/arjenhiemstra/ithowifi/issues/365) traced to a regression in 2.9.0-beta13 where the boot-time `sendI2CPWMinit()` handshake (the I2C frame that asks the unit to enable PWM-over-I2C acceptance) silently stopped firing on cold boot. The 2.9.0-beta13 commit that simplified pin definitions repurposed `status_pin` on CVE hardware rev "2" from an INPUT (reading the unit's readiness signal) to an OUTPUT (signalling our readiness to the unit), without updating the `digitalRead(status_pin)` in `ithoInitCheck()`. So on cold boot the firmware reads its own output line — which it just drove LOW — and never opens the gate that calls `sendI2CPWMinit()`.

Only `type:0x04 fw:0x01` units (the very first CVE I2C-protocol generation, sold as CVE ECO 2 SP) actually require the handshake; every other CVE / HRU variant accepts PWM2I2C frames directly. That's why the bug has been silent on almost every unit.

This release adds three log lines to confirm the diagnosis on affected hardware before shipping the fix:

- `I2C: ithoInitCheck status_pin=LOW/HIGH, pwm2i2c=N` — surfaces what `ithoInitCheck()` actually reads on cold boot.
- `I2C: sendI2CPWMinit triggered by ithoInitCheck (boot)` — fires only when the cold-boot path successfully calls `sendI2CPWMinit()`.
- `I2C: sendI2CPWMinit triggered by settings save` — fires when the websocket settings-save handler calls it (the path that, when triggered by toggling the debug switch, currently "fixes" the problem until the next power cycle on affected units).

If you have a CVE ECO 2 SP whose slider stops responding after a power cycle, please install this beta and share the System Log around the boot + the moment you toggle the I2C debug switch. The expected pattern is `status_pin=LOW`, no `triggered by ithoInitCheck (boot)` line, then `triggered by settings save` the moment you save any setting.

## Carries forward from 3.1.4-beta1 and beta2

All the memory-stability and I2C-status-format-flake fixes from beta1, and the index-page / REST / MQTT demand-slider fix from beta2.

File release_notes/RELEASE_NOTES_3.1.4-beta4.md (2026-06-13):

# Version 3.1.4-beta4

Iterative beta on top of 3.1.4-beta3. Headline change is the structural fix for CVE ECO 2 SP fan control after a cold power cycle — the regression behind issues [#346](https://github.com/arjenhiemstra/ithowifi/issues/346), [#364](https://github.com/arjenhiemstra/ithowifi/issues/364) and [#365](https://github.com/arjenhiemstra/ithowifi/issues/365).

## Bug fix — CVE ECO 2 SP fan control after a cold power cycle

Since 2.9.0-beta13 the boot-time `sendI2CPWMinit()` handshake had been silently skipped on CVE hardware rev "2" because a pin-naming refactor caused the boot-state check (`ithoInitCheck()`) to read the add-on's *output* line back into itself. The line is always LOW (we drove it LOW ourselves in `hardwareInit`), so the gate never opened, and the PWM-mode wake-up frame was never sent.

For modern CVE / HRU units the missing frame was a no-op — they accept PWM2I2C frames without it — so they kept working. But the first-generation CVE ECO 2 SP (`type:0x04 fw:0x01`) still requires the handshake to enable PWM-accept mode, and on every cold boot it would silently drop every PWM frame the add-on sent. Symptom: fan speed reads were fine, slider had no effect.

The boot init state machine now no longer reads any physical pin to decide what to do — `sendI2CPWMinit()` is issued from `initI2cFunctions()` the moment `QueryDevicetype` confirms a CVE unit responded on I2C. This is the strictly stronger and reliable readiness signal that the GPIO read was meant to be a proxy for.

Affected CVE ECO 2 SP users who'd reverted to 2.8.1 should be able to update to this build and have the slider work after both OTA upgrade *and* full power cycle.

## Internal change — status LED behaviour

The boot-time LED indication that the CC1101 module was detected is now a non-blocking 30-second blink instead of a brief blocking on/off pulse. Visible only on units with a CC1101 fitted; otherwise the LED behaves identically to beta3. (Internal testing helper — feel free to ignore unless you're staring at the PCB.)

## Investigation diagnostics

The `I2C: ithoInitCheck status_pin=…` log line from beta3 is gone (the function it lived in has been deleted). The replacement is one log line on every successful boot init: `I2C: sendI2CPWMinit triggered by initI2cFunctions (boot)`. The settings-save trigger keeps its own log line (`triggered by settings save`).

## Upgrade

Users on 2.8.1 who reverted because of the CVE ECO 2 SP regression can pick this beta up via the Update page (beta channel) or directly from the release asset.

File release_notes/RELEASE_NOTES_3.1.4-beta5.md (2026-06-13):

# Version 3.1.4-beta5

Iterative beta on top of 3.1.4-beta4. Adds add-on-tracked timer visibility for PWM2I2C timer / cook commands.

## Feature — expose add-on timer remaining on `/api/v2/speed`

For CVE / HRU200 units controlled via PWM2I2C, the `timer1` / `timer2` / `timer3` and `cook30` / `cook60` web-UI buttons drive the fan to a fixed speed for N minutes via the add-on's internal `IthoQueue`. The Itho unit itself only sees a PWM speed write, so the protocol-level `FanInfo` / `Selection` / `RemainingTime` fields stay at their pre-timer values — there's no way for a consumer (HA integration, MQTT subscriber, dashboard) to tell that a timer is running.

The `/api/v2/speed` endpoint now also returns the head-of-queue timer state from `ithoQueue`:

```json
{
    "status": "success",
    "data": {
        "currentspeed": 220,
        "timer_remaining_ms": 581600,
        "timer_speed": 220,
        "timestamp": 1780600058
    }
}
```

`timer_remaining_ms` is the milliseconds left on the active (head-of-queue) timer (0 when no timer is queued). `timer_speed` is the PWM speed value that was queued for that timer (`-1` when none).

The HA integration v0.5.7 picks this up automatically and adds an "Add-on timer remaining" diagnostic sensor in minutes. Older integration versions ignore the new fields safely. Issue [#368](https://github.com/arjenhiemstra/ithowifi/issues/368).

This is purely additive — no existing field renamed or removed, no behaviour change on the I2C side.

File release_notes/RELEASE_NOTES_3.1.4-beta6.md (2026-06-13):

# Version 3.1.4-beta6

Iterative beta on top of 3.1.4-beta5. Fixes the root cause of [#365](https://github.com/arjenhiemstra/ithowifi/issues/365) (CVE ECO 2 SP slider not driving the fan after a cold power-cycle) and tidies up the web UI text.

## Fix — PWM-init payload restored (#365)

`sendI2CPWMinit()` had been sending the wrong frame since commit [1efa17e](https://github.com/arjenhiemstra/ithowifi/commit/1efa17e) (Nov 2024). The two init helpers (PWM-init and CO2-init) share the same frame layout and differ only in bytes 8 and 10 — `0x09/0x09` for PWM, `0x13/0x13` for CO2. A copy/paste while adding the new `sendCO2init()` helper next to it pasted the CO2 bytes into the PWM frame. Every release from then on shipped the wrong payload.

CVE/HRU200 units other than the first-generation CVE ECO 2 SP silently accept either frame, so the bug stayed invisible. The CVE ECO 2 SP (`type 0x04 fw 0x01`) needs the correct `0x09/0x09` PWM-init before it will act on subsequent PWM speed writes, so after a cold power-cycle the slider would move but the fan would not respond. Downgrading to 2.8.0 / 2.8.1 worked because those releases predate the regression.

The fix is the one-line revert in `IthoVirtualRemoteCmd.cpp::sendI2CPWMinit()`. Combined with the boot-time `sendI2CPWMinit()` call added in beta3, affected units now recover automatically on the first I2C handshake — no manual intervention.

## Web UI — typo and capitalisation pass

Spelling fixes (`succesful` → `successful`, `normlized` → `normalized`, `satus` → `status`, `explaination` → `explanation`, `dataype` → `datatype`, `Github` → `GitHub`, `to you Itho` → `to your Itho`, a few `a RF/MQTT` → `an RF/MQTT`, and the broken "Command topicmands are sent as JSON to the MQTT com" sentence on the API page), plus the `ttype="text"` attribute typo on the debug page.

Normalised brand / acronym capitalisation across the UI (`Itho`, `I2C`, `CVE`, `CO2`, `RV`, `RF`, `JSON`, `API`, `WiFi`) and brought all page headers and menu items to sentence case so the setup wizard matches the rest of the UI. Also replaced `ie.` with `e.g.` everywhere — every use was an example, not a clarification.

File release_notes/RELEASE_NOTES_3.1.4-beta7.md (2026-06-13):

# Version 3.1.4-beta7

Iterative beta on top of 3.1.4-beta6. Stops the device from panicking when MQTT Home Assistant Discovery runs out of memory on devices with many status items.

## Fix — HA Discovery no longer panics on heap exhaustion

`mqttHomeAssistantDiscovery` could hit `std::bad_alloc` inside `generateHADiscoveryJson` on devices with many status items (134 on a WPU). The exception was uncaught, so the runtime called `std::terminate()` → `abort()` → panic → reboot loop. Total free heap could read fine at the point of failure — the heap was just fragmented from the many small `std::string` / `JsonDocument` allocations the JSON build does.

Two changes:

- The pre-flight heap check now guards on the largest contiguous free block (`heap_caps_get_largest_free_block(MALLOC_CAP_8BIT)`) instead of total free. Total free can read fine while contiguous is too small for the allocations the build actually needs.
- The build + publish is wrapped in `try { … } catch (const std::bad_alloc&) { … }`. If fragmentation tips the heap mid-run after the gate passes, the firmware logs `HAD: out of memory during HA Discovery (largest free block now N), skipping` and bails instead of taking the whole device down.

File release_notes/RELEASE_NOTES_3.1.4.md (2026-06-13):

## Version 3.1.4

Rolls up 3.1.4-beta1 through beta7. Headline fixes: CVE ECO 2 SP fan control after a cold power cycle, the RF CO2 demand slider direction, the MQTT HA Discovery crash, and the memory / I2C stability issues that surfaced in long-running 3.1.3 installs.

### Bug Fixes

- **CVE ECO 2 SP slider no longer leaves the fan unresponsive after a cold power cycle** ([#346](https://github.com/arjenhiemstra/ithowifi/issues/346), [#364](https://github.com/arjenhiemstra/ithowifi/issues/364), [#365](https://github.com/arjenhiemstra/ithowifi/issues/365)) — `sendI2CPWMinit()` had been sending the CO2-init bytes (`0x13/0x13`) instead of the PWM-init bytes (`0x09/0x09`) since November 2024. First-generation CVE ECO 2 SP (`type 0x04 fw 0x01`) needs the correct frame to enter PWM-accept mode; modern CVE / HRU units accepted either. Boot-time init now fires the moment `QueryDevicetype` confirms a CVE unit, so affected boards recover on the first I2C handshake.
- **RF CO2 demand slider drives the unit in both directions and respects its current mode.** 3.1.3 always sent an `auto` command before each 31E0 demand, which the RFT CO2 unit treated as a boost — so downward slider moves were ignored when the unit was already in auto. The firmware now reads `FanInfo` (from I2C 31DA polling or a tracked RF 31DA source) and only sends `auto` when the unit isn't already in it. Affects the index slider, the REST `percentage` / `fandemand` endpoints, and the MQTT `cmd` topic.
- **MQTT Home Assistant Discovery no longer panics the device on heap exhaustion.** On devices with many status items (notably WPU, 134 items) the JSON build could hit `std::bad_alloc`; the uncaught exception fell to `std::terminate()` → reboot loop. The pre-flight check now guards on the largest contiguous block instead of total free, and the build is wrapped in `try / catch (std::bad_alloc)` so a mid-run OOM logs and skips.
- **Itho status no longer "sometimes empty until reboot".** `QueryStatusFormat` is retried once at boot if the first attempt returns zero entries, and partial / corrupt replies at runtime no longer wipe the previously good list. Mutex acquire timeout raised from 100 ms to 500 ms for the status / 31DA / 31D9 paths.

### Memory & Heap Stability

- WebSocket `systemstat` broadcasts skipped when no clients are connected — per-client allocations on every broadcast were a major source of long-term fragmentation.
- WebSocket broadcast bails when free heap drops below 80 KB; `notifyClients` uses `std::nothrow`.
- MQTT publish buffer is grow-only — the post-publish shrink-back was reallocating thousands of times per day.
- WebSocket queued-message cap reduced from 64 to 8.

### API

- **`GET /api/v2/speed` now also returns `timer_remaining_ms` and `timer_speed`** for add-on-tracked PWM2I2C timers ([#368](https://github.com/arjenhiemstra/ithowifi/issues/368)). Additive — older consumers ignore the new fields. HA integration v0.5.7+ surfaces this as "Add-on timer remaining".

### Web UI

- Spelling, grammar and capitalisation pass: typos fixed (`succesful` → `successful`, `normlized` → `normalized`, `satus` → `status`, `explaination` → `explanation`, `dataype` → `datatype`, `Github` → `GitHub`), brand and acronym capitalisation normalised (Itho, I2C, CVE, CO2, RV, RF, JSON, API, WiFi), page headers and menu items brought to sentence case, `ie.` → `e.g.` throughout.

### Firmware binary

https://github.com/arjenhiemstra/ithowifi/releases/download/Version-3.1.4/nrgitho-v3.1.4.bin

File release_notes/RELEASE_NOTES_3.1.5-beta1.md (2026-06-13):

# Version 3.1.5-beta1

First iteration beyond 3.1.4 stable. One user-visible change so far: Home Assistant's firmware update button now shows progress.

## Feat — OTA progress visible in Home Assistant ([#371](https://github.com/arjenhiemstra/ithowifi/issues/371))

Clicking the firmware "Install" button in HA used to silently download and flash with no visible feedback until the device rebooted on the new version about two minutes later. HA's MQTT Update integration renders a progress bar when the value template emits `in_progress` and `update_percentage`, but the firmware-update discovery entity only emitted `installed_version` / `latest_version`.

This release:

- Adds an `ota_progress` integer (`-1` idle, `0-100` active, `101` done, `-2` error) to the MQTT `deviceinfo` topic.
- Updates the HA Discovery value template to derive `in_progress` and `update_percentage` from `ota_progress`.
- Republishes `deviceinfo` whenever `ota_progress` crosses idle ↔ active, otherwise rate-limited to once per second, so the progress bar moves smoothly instead of waiting on the periodic status tick.

No HA integration update needed — the new template is in the discovery payload itself. After this firmware boots once, HA picks up the updated entity definition on the next discovery republish.

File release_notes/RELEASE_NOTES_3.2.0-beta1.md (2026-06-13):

## Version 3.2.0-beta1

First beta of the 3.2 line. Carries forward the work from the (skipped) 3.1.5-beta line and adds active RF status polling for RF-standalone setups.

### Features

- **Periodic 31DA + 31D9 RF status request in RF standalone mode.** When `itho_rf_standalone == 1`, the add-on now actively requests `31DA` and `31D9` from the Itho over RF on the same interval as the existing **Itho status update frequency** setting. Each request is addressed from the first bi-directional Send remote that's been joined to the unit, so an HRU 400 / RF-only setup can see live status without an I2C connection. Skipped silently when no qualifying remote is configured, when the CC1101 is absent, or when the update frequency is 0.
- **Debug page: Request 31DA / Request 31D9 buttons** with an RF remote selector and an optional 3-byte destination-ID override. Lets you probe an arbitrary Itho's RF address from an arbitrary slot — handy when a slot was never actually joined to a real unit. Override is one-shot: the slot's stored destinationID is snapshotted and restored after the request.
- **OTA progress over MQTT** so Home Assistant's firmware-update entity shows a progress bar instead of silently downloading and flashing ([#371](https://github.com/arjenhiemstra/ithowifi/issues/371)). The HA Discovery value template emits `in_progress` and `update_percentage`, and the firmware republishes `deviceinfo` ~once per second during OTA so the bar moves. No HA integration update needed — the new template ships in the discovery payload itself. End-to-end visibility kicks in on the *next* OTA after a 3.2.0-beta1 device republishes Discovery.
- **Multi-zone HRU support.** `parseRF31DA` / `parseRF31D9` accept any payload[0] "domain" byte instead of dropping everything non-zero, so Itho DuoZone HRUs no longer look offline on the RF Status page ([#366](https://github.com/arjenhiemstra/ithowifi/issues/366)). The latest seen domain byte is surfaced as `zone31DA` / `zone31D9` on `/api/v2/rfstatus`. Single-zone units stay at `0` and behave exactly as before. Proper per-zone storage is a follow-up.

### Bug fixes

- **`POST /api/v2/rfremote/config` with `setrfdevicedestid` now persists** to flash, not just the runtime CC1101 state. The value previously only lived in the in-memory CC1101 layer, so it was lost on reboot and on the next Update click on the RF Devices page.
- **destinationID survives the Update click on the RF Devices page.** The web-UI Update was calling `updateRFDevice`, which resets the in-memory `destinationID` to the slot's own sourceID and silently wiped anything a join handshake or the `setrfdevicedestid` API had put there. The persisted destID is now re-applied right after `updateRFDevice`.
- **Paired 31DA + 31D9 RF status request actually sends both opcodes.** Stuffing them into one ISR-disabled critical section left the CC1101 in an intermediate state for the second TX, so it silently didn't go out. Each frame now gets its own ISR cycle with a 50 ms gap.
- **Debug page buttons no longer reload the page.** Every button on the Debug page was inside a `<form>` with no `type="button"` attribute, so the browser treated each click as a form submit and navigated away before the websocket message could land. Marked them `type="button"`.
- **TX Power dropdown on the RF Devices page activates the correct slot.** The dropdown is only rendered for SEND remotes, so the `forEach` iteration index didn't match the slot index — selecting one Send remote enabled the previously-selected remote's TX Power dropdown.

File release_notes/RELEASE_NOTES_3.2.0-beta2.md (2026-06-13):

## Version 3.2.0-beta2

Single-fix beta — flushes a long-standing HA Discovery template error for HRU users.

### Bug fixes

- **Fan entity no longer spams `'int object' has no attribute 'Requested fanspeed (%)'` in Home Assistant.** The fan's `percentage_state_topic` is `<base>/state`, which publishes a plain integer (the current ventilation percentage), but the HRU 350 / HRU-eco / HRU 250-300 / CVE-without-PWM2I2C branch of the HA Discovery builder was emitting `{{ value_json['Requested fanspeed (%)'] | int }}` — a JSON-object lookup on what is just a number. HA logged a template error on every state update. Template fixed to `{{ value | int }}`, matching what the CVE-with-PWM2I2C path already did. Pre-existing since the original HA Auto Discovery feature.

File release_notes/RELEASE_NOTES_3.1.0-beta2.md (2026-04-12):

## Version 3.1.0-beta2

Adds an RF standalone setup wizard for devices with no I2C connection (e.g. HRU 400), a redesigned firmware update page, a dedicated REST resource for OTA so external tools (like the [Home Assistant integration](https://github.com/arjenhiemstra/ithowifi-ha-integration)) can natively show update status and trigger installs, and several smaller API additions plus bug fixes.

**⚠️ This is a beta release — please report issues at https://github.com/arjenhiemstra/ithowifi/issues**

### Highlights

- **RF standalone setup wizard** — first-boot wizard now detects "no I2C device" and offers a guided RF-only setup path including automatic RF remote config and an interactive Join step
- **Redesigned Update page** — single firmware dropdown listing all available versions (stable, beta, historical), inline install button, embedded progress bar driven by live OTA status
- **New REST resource `/api/v2/ota`** — single endpoint for firmware version info AND install/progress tracking, intended for HA and other integrations
- **`/api/v2/remotes`** now exposes full remote config alongside the existing `remotesinfo` (backwards compatible)
- **`itho_control_interface`** added to `/api/v2/deviceinfo`
- **`firmware.json` fixes** — release-download URLs (no more 404s when binary isn't on master), compile-time sized response cap (no more silent failures when the file grows past 2KB), full error logging on every failure path

### New Features

#### RF standalone setup wizard

- New "**RF standalone mode**" option in System Settings (CC1101 section) for devices with no I2C connection
- Wizard auto-detects the no-I2C scenario (Generic Itho device / no detected I2C type) and presents an info box: *"No I2C connection detected. If your Itho device does not have an I2C connector (e.g. HRU 400), you can use RF standalone mode."* Two buttons: **Use RF Standalone Mode** or **Keep trying I2C**
- In RF standalone mode the wizard:
  - Hides the I2C section and disables I2C status queries (`itho_pwm2i2c=0`, `itho_31da=0`, `itho_31d9=0`, `itho_4210=0`, `itho_sendjoin=0`, `itho_forcemedium=0`, `itho_numvrem=0`)
  - Auto-configures RF remote slot 0 as **Send + RFT CO2** (`0x1298`)
  - Adds a **Join** step (Step 3) to pair the add-on with the Itho unit interactively, with success/failure feedback via a new `bind_result` websocket message
  - Sets `itho_rf_standalone=1` and `itho_control_interface=1` on finish
  - Skips the post-install power-cycle step (just reboot is enough since join already happened in the wizard)
- When `itho_rf_standalone=1` is active, the I2C, virtual remotes, and status menus are hidden in the web UI
- Wizard also recognises "Generic Itho device" as a no-device-type scenario

#### Update page rewrite

- Single dropdown listing **all available firmware versions** populated from `firmware.json` — current stable, current beta, and any historical versions in the `versions` array. Current version is annotated with "- current"
- **Show beta firmware version(s)** checkbox to filter the list
- Single **Install** button (replaces the separate "download stable / download beta" buttons) plus a single **Release notes** link
- **Embedded progress bar** that shows download/flash percentage live, driven by the `systemstat.ota_progress` websocket field
- **2-minute stuck-progress watchdog** — if no progress update arrives for 2 minutes the install is considered stuck and the UI shows an error
- Auto-reload after device returns from reboot
- Manual `.bin` upload still works as before (fieldset renamed to "Manual firmware update")

#### REST API additions

- **`GET /api/v2/ota`** — returns `installed_version`, `latest_fw`, `latest_beta_fw`, `fw_update_available`, plus live `state` and `progress` for an in-progress install. State is one of `idle`, `starting`, `downloading`, `done`, `error`
- **`POST /api/v2/ota`** — trigger a firmware install. Body is either `{"channel":"stable"}`, `{"channel":"beta"}`, or `{"url":"https://github.com/arjenhiemstra/ithowifi/..."}` for a pinned release asset. The URL form is domain-locked to the project's GitHub repo
- **OpenAPI spec updated** with the new GET / POST endpoints and the `OtaInstallRequest` schema. Visible in the device's Swagger UI
- **`GET /api/v2/remotes`** now returns the full remote configuration in a new top-level `remotes` array. The existing `remotesinfo` object is preserved for backwards compatibility
- **`GET /api/v2/deviceinfo`** now includes `itho_control_interface`, allowing API consumers to distinguish RF CO2 control mode from regular operation

### Bug Fixes

- **`firmware.json` fetch silently failed** when the file grew past 2000 bytes, leaving `latest_fw` / `latest_beta_fw` empty and breaking the device's firmware update card. The cap is now derived from the actual `firmware.json` size at compile time with ample headroom, and overridable via the `MAX_FIRMWARE_HTTPS_RESPONSE_SIZE` build flag
- **`checkFirmwareUpdate()` had no error logging** on any failure path. Every step now emits an `E_LOG` line on failure (alloc, `https.begin`, `GET`, HTTP status, oversized response, JSON parse, missing `hw_rev` entry), making remote diagnosis possible without serial access
- **`firmware.json` `link` and `link_beta`** previously pointed at `raw.githubusercontent.com/.../master/...`, which 404'd whenever the binary wasn't yet on master. Both now use `https://github.com/arjenhiemstra/ithowifi/releases/download/Version-X.Y.Z/...` so binaries are reachable from the GH release directly
- **`build_script.py`** updated to write the same release-download URL form for new releases, so future builds get this right automatically
- **`WiFiClientSecure` leak** in `checkFirmwareUpdate()` — the allocation was leaked on every error path. All paths now `delete secclient` before returning

### API

- **NEW**: `GET /api/v2/ota`, `POST /api/v2/ota`
- **CHANGED**: `GET /api/v2/remotes` now also returns a `remotes` array (existing `remotesinfo` preserved)
- **CHANGED**: `GET /api/v2/deviceinfo` now includes `itho_control_interface`
- **UNCHANGED**: `POST /api/v2/debug` — the existing `update` / `update_beta` / `update_url` actions there continue to work and remain available; new integrations should prefer `/api/v2/ota`

### Web Interface

- New **RF standalone mode** radio in System Settings → CC1101 section
- New **wizard step** for RF standalone setup with Join button and live join-result feedback
- **Wizard info box** offering RF standalone when no I2C device is detected
- Update page redesigned with dropdown, install button, and embedded progress bar
- Standalone-mode menu visibility: I2C, virtual remotes, and status menus hidden when `itho_rf_standalone=1`

### Compatibility

This release is fully backwards-compatible with 3.1.0-beta1.

- All existing REST API endpoints continue to return the same fields they did before; `remotes` and `itho_control_interface` are additions, not replacements
- The legacy `POST /api/v2/debug` update actions and the WebSocket-based `update_url` flow are unchanged
- The HA integration version `0.4.0` of [ithowifi-ha-integration](https://github.com/arjenhiemstra/ithowifi-ha-integration) requires this firmware (3.1.0-beta2 or newer) to register the firmware update entity. Older firmware will simply omit the entity rather than fail

### Firmware binary

Firmware binary (CVE HW rev.2 and NON-CVE):
https://github.com/arjenhiemstra/ithowifi/releases/download/Version-3.1.0-beta2/nrgitho-v3.1.0-beta2.bin

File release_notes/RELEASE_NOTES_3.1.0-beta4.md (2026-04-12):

## Version 3.1.0-beta4

Corrects the per-remote-type preset tables used by HA Auto Discovery and exposes them via the REST API so external integrations (HA custom integration, scripts) know exactly which commands each configured remote supports.

**⚠️ This is a beta release — please report issues at https://github.com/arjenhiemstra/ithowifi/issues**

### Highlights

- **Preset tables now match the actual RF command maps** in `IthoCC1101.cpp`. Previously several remote types had a too-narrow preset list (e.g. RFT RV / RFT CO2 / RFT CVE). The published presets are now derived from the same `RFT*_Remote_Map[]` that the radio uses for transmission.
- **New `presets` field on every remote entry** in `GET /api/v2/remotes` and `GET /api/v2/vremotes`, in wire format (e.g. `low,medium,high,timer1,timer2,timer3`). Intended for external consumers that need to know which commands each remote supports without duplicating the table client-side.
- **Web UI label fix**: the `itho_vremoteapi` setting's label was misleading — it's now labelled "Map API key "command" to virtual remote 0", which is what it actually does.

### Bug Fixes

- **RFT CVE remotes were missing `Away`** from the preset list. The RF command map has a valid `ithoMessageAwayCommandBytes` entry for CVE. Added.
- **RFT RV remotes were missing `Low` and `High`**. Same cause. Added.
- **RFT CO2 remotes were missing `Low` and `High`**. Same cause. Added.
- **RFT AutoN remotes were missing `Away` and `Medium`** (they were sharing a preset row with RFT Auto, which is a different type). Split into their own case with the correct set: `Away,Low,Medium,High,Auto,AutoNight,Timer 10/20/30min`.
- **RFT Spider remotes were missing almost everything** — the preset list was just `Low,High` but the RF command map supports Low, Medium, High, Auto, AutoNight, and all three timers. Full list now published.

### API

- **CHANGED**: `GET /api/v2/remotes` — `remotes[*]` entries now include a `presets` field (wire-format comma-separated string) reflecting the commands supported by each remote's type.
- **CHANGED**: `GET /api/v2/vremotes` — same addition on `vremotesinfo[*]`.
- **UNCHANGED**: `remotesinfo` shape, MQTT publish format, existing preset commands — all backwards-compatible.

### Internal

- New `HADiscConfig::getWirePresetsForType(uint16_t remoteType)` static helper, declared in `HADiscConfig.h` and defined in `HADiscConfig.cpp`. Kept in lockstep with the existing human-readable `getPresetsForType()` used by HA MQTT auto-discovery.
- `IthoRemote::Remote::get()` now emits `obj["presets"]` for every remote it serializes.

### Compatibility

Fully backwards-compatible with 3.1.0-beta3.

- Existing consumers of `/api/v2/remotes` and `/api/v2/vremotes` see only new fields; nothing removed or renamed.
- HA MQTT Auto Discovery users see the corrected preset list on their remotes' `select` entities after the next discovery cycle. Automations that previously worked with the (too-narrow) list still work; automations that tried to use a preset the device silently ignored may now actually apply.
- The Home Assistant integration [ithowifi-ha-integration](https://github.com/arjenhiemstra/ithowifi-ha-integration) version `0.5.0` requires this firmware release to get accurate per-remote preset lists. On older firmware (`3.1.0-beta3` or earlier) it falls back to a conservative `low / medium / high` set.

### Firmware binary

Firmware binary (CVE HW rev.2 and NON-CVE):
https://github.com/arjenhiemstra/ithowifi/releases/download/Version-3.1.0-beta4/nrgitho-v3.1.0-beta4.bin

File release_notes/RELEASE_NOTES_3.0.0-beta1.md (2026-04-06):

## Version 3.0.0-beta1

Major release with new features, new RESTful API, and significant improvements to RF communication.

**⚠️ This is a beta release — please report issues at https://github.com/arjenhiemstra/ithowifi/issues**

### Highlights

- **RESTful API v2** — Proper REST API with GET/POST/PUT at `/api/v2/*`, OpenAPI spec, and Swagger UI
- **Bidirectional RF** — The add-on can now join as an RF remote (RFT CO2, RFT Auto-N, RFT-N, RFT RV, RFT Spider) and send commands directly to your Itho
- **RF CO2 demand control** — Ventilation demand slider (0–200) on the index page for CO2-based fan control
- **Setup wizard** — First-boot wizard for guided configuration
- **HA Auto Discovery** — RF devices, virtual remotes, fan component, Itho status items, and firmware update sensor
- **Security** — Encrypted credential exchange (AES-256-CTR), HTTP Basic Auth, CSRF protection, API parameter whitelisting
- **jQuery removed** — Full migration to vanilla JS (~30KB flash savings)

### Changes since 2.8.0

### Breaking Changes

- `/api.html` now always returns v1 plain text (OK/NOK); the query-parameter v2 style was removed
- `api_version` setting removed from system configuration
- REST API v2 at `/api/v2/*` is the new JSON API
- RF remote types auto-detect the bidirectional flag based on remote type

### New Features

- **Setup wizard** for first-boot configuration with step-by-step guidance
- **Encrypted credential exchange** (AES-256-CTR) between browser and device
- **RESTful API v2** with proper HTTP methods (GET/POST/PUT) at `/api/v2/*`
- **OpenAPI specification** and interactive Swagger UI at `/api/openapi.json` and `/swagger`
- **RF CO2 control interface** with demand slider (0–200) on the index page
- **RF CO2 join on boot** setting to auto-send join after power cycle
- **Bidirectional RF** for RFT-N, RFT Auto-N, RFT RV, RFT CO2, and RFT Spider remote types
- **RF binding initiator** — send join/bind requests from the add-on to pair with Itho units
- **Per-remote TX power** — configurable per RF device; auto-detected based on device type and I2C connection
- **Unified fan control** via `percentage` (0–100) and `fandemand` (0–200), available on REST, MQTT, and WebSocket; maps to RF CO2 demand or PWM speed depending on device type
- **MQTT command responses** published on `{base_topic}/cmd/response`
- **I2C status queries on boot** — all enabled queries (2401, 31DA, 31D9, 4210) run immediately after device init instead of waiting for their normal interval
- **RF status monitoring** with source tracking, custom names, and MQTT/Web API integration
- **HA Auto Discovery** for RF devices, virtual remote fan entities, Itho status items, fan component, and firmware update sensor (requires HA Core 2024.11+)
- **HA Auto Discovery State Class** as configurable option
- **CVE ECO2** device support in HA Auto Discovery
- **WPU firmware v41** status labels
- **Outside temperature API** for WPU devices
- **WPU manual control** (4030 command) via REST API
- **RFT-N remote type** support
- **Configurable number of RF remotes** as a system setting
- **Device info** extended on MQTT API and WebAPI
- **RF log** moved from debug page to syslog page with configurable log level
- **WebSerial** debug interface at `http://IP:8000/webserial`
- **Automatic firmware update check**
- **Changeable RF source ID** for the add-on
- **Raw 31D9 and 31DA** I2C message requests
- **HTTP Basic Auth** for API endpoints
- **get=vremotesinfo** command added to WebAPI v1
- **Option to reset HA Discovery config**
- **WiFi MAC address** in boot logging
- **Boot LED states** to visually confirm CC1101 module detection
- **api_reboot** setting to gate device reboot via API (default off)

### API

**REST API v2 Endpoints**
- **GET**: `/api/v2/speed`, `/ithostatus`, `/deviceinfo`, `/queue`, `/lastcmd`, `/remotes`, `/vremotes`, `/rfstatus`, `/settings`
- **POST**: `/api/v2/command` (with `percentage`/`fandemand`), `/vremote`, `/rfremote/command`, `/rfremote/co2`, `/rfremote/demand`, `/rfremote/config`, `/debug`, `/wpu/outside_temp`, `/wpu/manual_control`
- **PUT**: `/api/v2/settings`
- **CORS** support on all endpoints
- **Parameter whitelisting** on legacy `/api.html`

**MQTT**
- Command responses on `{base_topic}/cmd/response` with status, command, and timestamp
- `percentage`, `fandemand`, `rfco2`, `rfdemand`, `rfzone` keys supported
- Fix: vremote logic bug when both index and name provided (now `vremotename` takes precedence)
- Fix: MQTT cmd topic cleaned after successful command

### Web Interface

- **jQuery fully removed** — migrated to vanilla JS (~30KB flash savings)
- Setup wizard with device-specific defaults and instructions
- Swagger UI for interactive API exploration
- RF CO2 demand slider on index page with actual fan demand readback
- RF status monitoring page with tracked source data
- Per-remote TX power dropdown in RF Devices page (Send remotes only)
- WiFi status mapped to user-friendly text (Connected, Disconnected, etc.)
- Hostname moved above Advanced settings in WiFi wizard
- Auto-save remote config before entering learn/leave mode
- Auto-generate remote ID when switching to Send mode
- Remote capabilities inputs disabled until remote is selected

### RF / CC1101

- Bidirectional RF communication with full bind handshake (offer → accept → confirm)
- Split `receivePacket` into ISR read and deferred decode with double buffering
- End byte selection based on decoded message length parity (even → 0xAC, odd → 0xCA)
- Per-remote TX power with auto-detect: CVE/HRU200 at −30 dBm, other I2C at +5 dBm, standalone at +10 dBm
- Source ID set per Send remote at boot and on config update
- Binding accept matched against source ID (not just module default ID)
- RF CO2 send functions: `send1298` (CO2 ppm), `send12A0` (temp/humidity), `send31E0` (demand), `sendRQ31DA` (status request)
- 200ms delay between auto and demand RF commands to prevent collisions
- CC1101 SPI lockup prevention with chip version check
- RF ISR reentry prevention with mutex
- Wizard defaults to RFT CO2 for non-PWM2I2C HRU devices (HRU350, HRU250-300, HRU ECO)

### Bug Fixes

- Fix: force medium doesn't work when virtual remote is not RFTCVE, RFTCO2, or RFTRV type
- Fix: duplicate utc-time key for WPU
- Fix: remote learn/leave mode not deactivated after timer runs out
- Fix: web UI hex remote ID entry with values < 0x10
- Fix: rounding issues from double-to-float migration
- Fix: remotes received but not processed
- Fix: config not saved when done in a certain order [#294](https://github.com/arjenhiemstra/ithowifi/issues/294)
- Fix: settings not updated in Itho Settings dialog [#310](https://github.com/arjenhiemstra/ithowifi/issues/310)
- Fix: setting not updated on 1st try from browser cache [#310](https://github.com/arjenhiemstra/ithowifi/issues/310)
- Fix: Itho settings via API causes reboot [#316](https://github.com/arjenhiemstra/ithowifi/issues/316)
- Fix: MQTT RF command crash [#350](https://github.com/arjenhiemstra/ithowifi/issues/350)
- Fix: web socket parsing issues
- Fix: mDNS hostname lowercase only
- Fix: config save before load protection
- Fix: HA Discovery support for larger config files (8K)
- Fix: websocket receive refactored for multi-frame large messages
- Fix: setrfdevicesourceid API call handling
- Fix: favicon URL
- Fix: factory reset uses delayed reboot instead of immediate esp_restart
- Fix: encrypted credential decryption bypassing password filter
- Fix: password masking in presentation layer (not in config get)
- Fix: empty remote slots properly identified and skipped
- Fix: WebSocket message handlers null-check DOM elements
- Fix: device type check for pwm2i2c support (|| vs && logic error)
- Fix: empty API request returns fail instead of error
- Fix: operator precedence bug in IthoSettings.cpp
- Fix: API error messages now list valid options instead of generic "cmdvalue not valid"
- Fix: end byte encoding based on decoded message length parity
- Fix: binding accept matched against source ID (not just default module ID)
- Fix: auto-save remote config before entering learn/leave mode
- Skip I2C check for WPU devices

### Security

- AES-256-CTR encrypted credential exchange (SecureWebCommLite)
- HTTP Basic Auth on all REST API v2 endpoints
- Parameter whitelisting on legacy `/api.html`
- Reboot via API gated by `api_reboot` setting (default off)
- CSRF inherently blocked on REST API (POST/PUT require `Content-Type: application/json`)

### Build & Dependencies

- jQuery removed
- Switched from stale ESPAsyncWebServer to maintained ESP32Async repos
- ArduinoJson updated to v7.4.3
- ArduinoStreamUtils updated to v1.9.2
- AsyncTCP v3.4.10
- ESPAsyncWebServer v3.10.0
- Switched to PubSubClient3
- Mongoose removed
- Build flags for C (gnu17) / C++ (gnu20)

### Testing

- 304 native unit tests on x86 (PlatformIO native_test environment)
- 250+ integration tests (Python/pytest against live device)
- MQTT integration tests with broker authentication
- Schemathesis OpenAPI fuzzing support
- Test coverage for: config serialization, JSON parsing, speed/timer validation, API parameter validation, queue logic, remote management, RF logic, UUID, WiFi config, MQTT responses

### Documentation

- OpenAPI 3.0 specification at `/api/openapi.json`
- Interactive Swagger UI at `/swagger`
- API documentation page with REST API v2 examples, MQTT reference, and full parameter table
- Web UI text updated for remotes, virtual remotes, and status pages

### Firmware binary

Firmware binary (CVE HW rev.2 and NON-CVE):
https://github.com/arjenhiemstra/ithowifi/raw/master/compiled_firmware_files/unified_hw2_noncve/nrgitho-v3.0.0-beta1.bin

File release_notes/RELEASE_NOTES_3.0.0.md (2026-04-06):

## Version 3.0.0

Major release with new features, new RESTful API, and significant improvements to RF communication.

### Highlights

- **RESTful API v2** — Proper REST API with GET/POST/PUT at `/api/v2/*`, OpenAPI spec, and Swagger UI
- **Bidirectional RF** — The add-on can now join as an RF remote (RFT CO2, RFT Auto-N, RFT-N, RFT RV, RFT Spider) and send commands directly to your Itho
- **RF CO2 demand control** — Ventilation demand slider (0–200) on the index page for CO2-based fan control
- **Setup wizard** — First-boot wizard for guided configuration
- **HA Auto Discovery** — RF devices, virtual remotes, fan component, Itho status items, and firmware update sensor
- **Security** — Encrypted credential exchange (AES-256-CTR), HTTP Basic Auth, CSRF protection, API parameter whitelisting
- **jQuery removed** — Full migration to vanilla JS (~30KB flash savings)

### Changes since 2.8.x

### Breaking Changes

- `/api.html` now always returns v1 plain text (OK/NOK); the query-parameter v2 style was removed
- `api_version` setting removed from system configuration
- REST API v2 at `/api/v2/*` is the new JSON API
- RF remote types auto-detect the bidirectional flag based on remote type

### New Features

- **Setup wizard** for first-boot configuration with step-by-step guidance
- **Encrypted credential exchange** (AES-256-CTR) between browser and device
- **RESTful API v2** with proper HTTP methods (GET/POST/PUT) at `/api/v2/*`
- **OpenAPI specification** and interactive Swagger UI at `/api/openapi.json` and `/swagger`
- **RF CO2 control interface** with demand slider (0–200) on the index page
- **RF CO2 join on boot** setting to auto-send join after power cycle
- **Bidirectional RF** for RFT-N, RFT Auto-N, RFT RV, RFT CO2, and RFT Spider remote types
- **RF binding initiator** — send join/bind requests from the add-on to pair with Itho units
- **Per-remote TX power** — configurable per RF device; auto-detected based on device type and I2C connection
- **Unified fan control** via `percentage` (0–100) and `fandemand` (0–200), available on REST, MQTT, and WebSocket; maps to RF CO2 demand or PWM speed depending on device type
- **MQTT command responses** published on `{base_topic}/cmd/response`
- **I2C status queries on boot** — all enabled queries (2401, 31DA, 31D9, 4210) run immediately after device init instead of waiting for their normal interval
- **RF status monitoring** with source tracking, custom names, and MQTT/Web API integration
- **HA Auto Discovery** for RF devices, virtual remote fan entities, Itho status items, fan component, and firmware update sensor (requires HA Core 2024.11+)
- **HA Auto Discovery State Class** as configurable option
- **CVE ECO2** device support in HA Auto Discovery
- **WPU firmware v41** status labels
- **Outside temperature API** for WPU devices
- **WPU manual control** (4030 command) via REST API
- **RFT-N remote type** support
- **Configurable number of RF remotes** as a system setting
- **Device info** extended on MQTT API and WebAPI
- **RF log** moved from debug page to syslog page with configurable log level
- **WebSerial** debug interface at `http://IP:8000/webserial`
- **Automatic firmware update check**
- **Changeable RF source ID** for the add-on
- **Raw 31D9 and 31DA** I2C message requests
- **HTTP Basic Auth** for API endpoints
- **get=vremotesinfo** command added to WebAPI v1
- **Option to reset HA Discovery config**
- **WiFi MAC address** in boot logging
- **Boot LED states** to visually confirm CC1101 module detection
- **api_reboot** setting to gate device reboot via API (default off)

### API

**REST API v2 Endpoints**
- **GET**: `/api/v2/speed`, `/ithostatus`, `/deviceinfo`, `/queue`, `/lastcmd`, `/remotes`, `/vremotes`, `/rfstatus`, `/settings`
- **POST**: `/api/v2/command` (with `percentage`/`fandemand`), `/vremote`, `/rfremote/command`, `/rfremote/co2`, `/rfremote/demand`, `/rfremote/config`, `/debug`, `/wpu/outside_temp`, `/wpu/manual_control`
- **PUT**: `/api/v2/settings`
- **CORS** support on all endpoints
- **Parameter whitelisting** on legacy `/api.html`

**MQTT**
- Command responses on `{base_topic}/cmd/response` with status, command, and timestamp
- `percentage`, `fandemand`, `rfco2`, `rfdemand`, `rfzone` keys supported
- Fix: vremote logic bug when both index and name provided (now `vremotename` takes precedence)
- Fix: MQTT cmd topic cleaned after successful command

### Web Interface

- **jQuery fully removed** — migrated to vanilla JS (~30KB flash savings)
- Setup wizard with device-specific defaults and instructions
- Swagger UI for interactive API exploration
- RF CO2 demand slider on index page with actual fan demand readback
- RF status monitoring page with tracked source data
- Per-remote TX power dropdown in RF Devices page (Send remotes only)
- WiFi status mapped to user-friendly text (Connected, Disconnected, etc.)
- Hostname moved above Advanced settings in WiFi wizard
- Auto-save remote config before entering learn/leave mode
- Auto-generate remote ID when switching to Send mode
- Remote capabilities inputs disabled until remote is selected
- DemandFlow/QualityFlow wizard defaults (12 virtual remotes, RFT DF/QF type)

### RF / CC1101

- Bidirectional RF communication with full bind handshake (offer → accept → confirm)
- Split `receivePacket` into ISR read and deferred decode with double buffering
- End byte selection based on decoded message length parity (even → 0xAC, odd → 0xCA)
- Per-remote TX power with auto-detect: CVE/HRU200 at −30 dBm, other I2C at +5 dBm, standalone at +10 dBm
- Source ID set per Send remote at boot and on config update
- Binding accept matched against source ID (not just module default ID)
- RF CO2 send functions: `send1298` (CO2 ppm), `send12A0` (temp/humidity), `send31E0` (demand), `sendRQ31DA` (status request)
- 200ms delay between auto and demand RF commands to prevent collisions
- CC1101 SPI lockup prevention with chip version check
- RF ISR reentry prevention with mutex
- Wizard defaults to RFT CO2 for non-PWM2I2C HRU devices (HRU350, HRU250-300, HRU ECO)

### Bug Fixes

- Fix: coredump download crashed device (use-after-free in chunked response) *(beta2)*
- Fix: WebSocket buffer race condition causing heap corruption *(beta2)*
- Fix: OTA static buffer overflow on repeated updates *(beta2)*
- Fix: I2C safe guard null pointer dereference *(beta2)*
- Fix: uninitialized decrypt buffer *(beta2)*
- Fix: strncpy replaced with strlcpy throughout codebase *(beta2)*
- Fix: force medium doesn't work when virtual remote is not RFTCVE, RFTCO2, or RFTRV type
- Fix: duplicate utc-time key for WPU
- Fix: remote learn/leave mode not deactivated after timer runs out
- Fix: web UI hex remote ID entry with values < 0x10
- Fix: rounding issues from double-to-float migration
- Fix: remotes received but not processed
- Fix: config not saved when done in a certain order [#294](https://github.com/arjenhiemstra/ithowifi/issues/294)
- Fix: settings not updated in Itho Settings dialog [#310](https://github.com/arjenhiemstra/ithowifi/issues/310)
- Fix: setting not updated on 1st try from browser cache [#310](https://github.com/arjenhiemstra/ithowifi/issues/310)
- Fix: Itho settings via API causes reboot [#316](https://github.com/arjenhiemstra/ithowifi/issues/316)
- Fix: web socket parsing issues
- Fix: mDNS hostname lowercase only
- Fix: config save before load protection
- Fix: HA Discovery support for larger config files (8K)
- Fix: websocket receive refactored for multi-frame large messages
- Fix: setrfdevicesourceid API call handling
- Fix: favicon URL
- Fix: factory reset uses delayed reboot instead of immediate esp_restart
- Fix: encrypted credential decryption bypassing password filter
- Fix: password masking in presentation layer (not in config get)
- Fix: empty remote slots properly identified and skipped
- Fix: WebSocket message handlers null-check DOM elements
- Fix: device type check for pwm2i2c support (|| vs && logic error)
- Fix: empty API request returns fail instead of error
- Fix: operator precedence bug in IthoSettings.cpp
- Fix: API error messages now list valid options instead of generic "cmdvalue not valid"
- Fix: end byte encoding based on decoded message length parity
- Fix: binding accept matched against source ID (not just default module ID)
- Fix: auto-save remote config before entering learn/leave mode
- Fix: MQTT crash when rfremoteindex sent as JSON integer [#350](https://github.com/arjenhiemstra/ithowifi/issues/350)
- Fix: auto-fill module RF ID when switching remote to Send mode [#352](https://github.com/arjenhiemstra/ithowifi/issues/352)
- Fix: Itho status I2C mutex to prevent bus lockup under high fan demand
- Fix: wizard settings not saved (ArduinoJson v7 string-to-int conversion)
- Fix: wizard systemsettings response overwriting user-configured form fields
- Fix: wizard RF remote config not persisted (shared DelayedSave ticker race)
- Fix: wizard RF remote type read from global dropdown instead of per-remote selection
- Fix: wizard state not preserved across WiFi reboot on first boot
- Fix: wizard WiFi status flashing "Disconnected" instead of "Connecting..."
- Fix: Send remote buttons routed to virtual remote I2C path instead of RF command path
- Fix: per-remote TX power ignored — hardcoded low power used for all Send remotes
- Fix: OTA progress percentage exceeding 100%
- Skip I2C check for WPU devices

### Security

- AES-256-CTR encrypted credential exchange (SecureWebCommLite)
- HTTP Basic Auth on all REST API v2 endpoints
- Parameter whitelisting on legacy `/api.html`
- Reboot via API gated by `api_reboot` setting (default off)
- CSRF inherently blocked on REST API (POST/PUT require `Content-Type: application/json`)
- WebSocket buffer mutex for thread-safe concurrent access *(beta2)*
- I2C mutex for Itho status queries to prevent bus lockup

### Build & Dependencies

- jQuery removed
- Switched from stale ESPAsyncWebServer to maintained ESP32Async repos
- ArduinoJson updated to v7.4.3
- ArduinoStreamUtils updated to v1.9.2
- AsyncTCP v3.4.10
- ESPAsyncWebServer v3.10.0
- Switched to PubSubClient3
- Mongoose removed
- Build flags for C (gnu17) / C++ (gnu20)

### Testing

- 304 native unit tests on x86 (PlatformIO native_test environment)
- 250+ integration tests (Python/pytest against live device)
- MQTT integration tests with broker authentication
- Schemathesis OpenAPI fuzzing support
- Test coverage for: config serialization, JSON parsing, speed/timer validation, API parameter validation, queue logic, remote management, RF logic, UUID, WiFi config, MQTT responses

### Documentation

- OpenAPI 3.0 specification at `/api/openapi.json` and as standalone file at `docs/openapi.json`
- Interactive Swagger UI at `/swagger`
- API documentation page with REST API v2 examples, MQTT reference, and full parameter table
- Web UI text updated for remotes, virtual remotes, and status pages

### Firmware binary

Firmware binary (CVE HW rev.2 and NON-CVE):
https://github.com/arjenhiemstra/ithowifi/releases/download/Version-3.0.0/nrgitho-v3.0.0.bin

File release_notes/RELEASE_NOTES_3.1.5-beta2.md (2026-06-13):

# Version 3.1.5-beta2

Iterative beta on top of 3.1.5-beta1. One change: multi-zone HRUs (Itho DuoZone) now show up on the RF Status page instead of looking offline.

## Feat — multi-zone 31DA / 31D9 acceptance ([#366](https://github.com/arjenhiemstra/ithowifi/issues/366))

`parseRF31DA` and `parseRF31D9` dropped every frame whose first payload byte wasn't `0x00`. On Itho DuoZone HRUs (e.g. HRU ECO 300 R, model `03-00630`) the unit broadcasts the same opcode once per zone, with the zone ID in that byte (`0x15` / `0x16` / `0x17` for the typical living + sleeping + combined arrangement). All frames were therefore dropped and the source looked offline on `/api/v2/rfstatus`.

The guard is gone. The latest seen domain byte is now recorded on the `rfStatusSource` as `lastZone31DA` / `lastZone31D9` and surfaced as `zone31DA` / `zone31D9` in the `/api/v2/rfstatus` JSON output. Multi-zone consumers see the most recently broadcast zone's data rotating between zones; the new fields tell them which zone the current snapshot is from. Single-zone units stay at `0` and behave exactly as before.

Proper per-zone storage — separate measurements per zone surfaced simultaneously — is a follow-up. This release is the minimum unblock: from "no data" to "live data with a zone indicator".

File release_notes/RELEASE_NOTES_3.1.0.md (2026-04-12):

## Version 3.1.0

> **⚠️ This version is superseded by [3.1.3](https://github.com/arjenhiemstra/ithowifi/releases/tag/Version-3.1.3).** Please upgrade to 3.1.3.

### Highlights

- **RF standalone mode** — full RF-only operation for devices without I2C (e.g. HRU 400), with guided first-boot setup wizard including interactive RF Join
- **OTA firmware update** — download and flash from GitHub releases via the web UI or REST API. New `GET/POST /api/v2/ota` enables firmware updates from external tools like the [Home Assistant integration](https://github.com/arjenhiemstra/ithowifi-ha-integration)
- **Channel-aware HA MQTT discovery** — auto-detects stable vs beta channel; beta users no longer see bogus "downgrade to stable" prompts ([#358](https://github.com/arjenhiemstra/ithowifi/issues/358))
- **Per-remote tracking** — new `last_cmd` and `presets` fields per remote in `/api/v2/remotes` and `/api/v2/vremotes`
- **Preset tables corrected** to match actual RF command maps (several remote types had missing presets)
- **Update page rewrite** — single firmware dropdown, inline install button, embedded progress bar
- **Swagger UI crash fixed** — OpenAPI spec moved to compile-time generation, eliminating stack overflow on the AsyncTCP task

### New REST API Endpoints

- `GET /api/v2/ota` — firmware versions, update channel, OTA progress
- `POST /api/v2/ota` — trigger install (`{"channel":"stable|beta"}` or `{"url":"..."}`)

### API Changes

- `/api/v2/remotes` — new `remotes` array with full config + `last_cmd` + `presets` per remote (backwards-compatible; `remotesinfo` unchanged)
- `/api/v2/vremotes` — now returns data (was broken), includes `last_cmd` + `presets` per virtual remote
- `/api/v2/deviceinfo` — new fields: `itho_control_interface`, `add-on_update_channel`, `add-on_latest_for_channel`
- MQTT command topic accepts `{"update":"auto"}` (resolves to stable/beta based on running version)

### Bug Fixes

- `firmware.json` fetch silently failed when file exceeded 2KB — now compile-time sized with headroom
- `checkFirmwareUpdate()` had no error logging — every failure path now logged
- `WiFiClientSecure` leaked on error paths in `checkFirmwareUpdate()`
- `firmware.json` URLs pointed at `raw/master/...` (404-prone) — now use release-download URLs
- `GET /api/v2/vremotes` returned empty `{}` — fixed (`as<>` vs `to<>` on fresh JsonDocument)
- OpenAPI spec handler caused device lockups (stack overflow on 4KB AsyncTCP task) — moved to compile-time gzip'd blob
- `CONFIG_ASYNC_TCP_STACK_SIZE` doubled from 4KB to 8KB as defense in depth

### Compatibility

Fully backwards-compatible with 3.0.0. All existing REST, MQTT, and WebSocket interfaces continue to work. New fields and endpoints are additive.

The [ithowifi-ha-integration](https://github.com/arjenhiemstra/ithowifi-ha-integration) v0.4.0+ requires this firmware for the native update entity; v0.5.0 requires it for per-remote fan entities.

### Firmware binary

https://github.com/arjenhiemstra/ithowifi/releases/download/Version-3.1.0/nrgitho-v3.1.0.bin

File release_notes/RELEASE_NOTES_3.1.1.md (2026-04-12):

## Version 3.1.1

> **⚠️ This version is superseded by [3.1.3](https://github.com/arjenhiemstra/ithowifi/releases/tag/Version-3.1.3).** Please upgrade to 3.1.3.

Patch release fixing a crash during OTA firmware updates when REST API requests arrive concurrently.

### Bug Fixes

- **Device crash during OTA when REST API is polled** — serializing a JSON response (e.g. `GET /api/v2/remotes`) while an OTA download is in progress could exhaust the heap, causing `std::bad_alloc` → `abort()` → watchdog reset on the `async_tcp` task. The `sendSuccess` / `sendFail` / `sendError` helpers now catch allocation failures and return a `503 Service Unavailable` plain-text response instead of crashing.

### Firmware binary

https://github.com/arjenhiemstra/ithowifi/releases/download/Version-3.1.1/nrgitho-v3.1.1.bin

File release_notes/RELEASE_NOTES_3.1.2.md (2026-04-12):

## Version 3.1.2

> **⚠️ This version is superseded by [3.1.3](https://github.com/arjenhiemstra/ithowifi/releases/tag/Version-3.1.3).** Please upgrade to 3.1.3.

### Highlights

- **RF standalone mode** — full RF-only operation for devices without I2C (e.g. HRU 400), with guided first-boot setup wizard including interactive RF Join
- **OTA firmware update** — download and flash from GitHub releases via the web UI or REST API. New `GET/POST /api/v2/ota` enables firmware updates from external tools like the [Home Assistant integration](https://github.com/arjenhiemstra/ithowifi-ha-integration)
- **Channel-aware HA MQTT discovery** — auto-detects stable vs beta channel; beta users no longer see bogus "downgrade to stable" prompts ([#358](https://github.com/arjenhiemstra/ithowifi/issues/358))
- **Per-remote tracking** — new `last_cmd` and `presets` fields per remote in `/api/v2/remotes` and `/api/v2/vremotes`
- **Preset tables corrected** to match actual RF command maps (several remote types had missing presets)
- **Update page rewrite** — single firmware dropdown, inline install button, embedded progress bar
- **Swagger UI crash fixed** — OpenAPI spec moved to compile-time generation, eliminating stack overflow on the AsyncTCP task

### New REST API Endpoints

- `GET /api/v2/ota` — firmware versions, update channel, OTA progress
- `POST /api/v2/ota` — trigger install (`{"channel":"stable|beta"}` or `{"url":"..."}`)

### API Changes

- `/api/v2/remotes` — new `remotes` array with full config + `last_cmd` + `presets` per remote (backwards-compatible; `remotesinfo` unchanged)
- `/api/v2/vremotes` — now returns data (was broken), includes `last_cmd` + `presets` per virtual remote
- `/api/v2/deviceinfo` — new fields: `itho_control_interface`, `add-on_update_channel`, `add-on_latest_for_channel`
- MQTT command topic accepts `{"update":"auto"}` (resolves to stable/beta based on running version)
- All REST endpoints return `503 Service Unavailable` during active OTA download (except `GET /api/v2/ota` for progress monitoring)

### Bug Fixes

- `firmware.json` fetch silently failed when file exceeded 2KB — now compile-time sized with headroom
- `checkFirmwareUpdate()` had no error logging — every failure path now logged
- `WiFiClientSecure` leaked on error paths in `checkFirmwareUpdate()`
- `firmware.json` URLs pointed at `raw/master/...` (404-prone) — now use release-download URLs
- `GET /api/v2/vremotes` returned empty `{}` — fixed (`as<>` vs `to<>` on fresh JsonDocument)
- OpenAPI spec handler caused device lockups (stack overflow on 4KB AsyncTCP task) — moved to compile-time gzip'd blob
- `CONFIG_ASYNC_TCP_STACK_SIZE` doubled from 4KB to 8KB as defense in depth
- REST API response serialization catches `std::bad_alloc` and returns 503 instead of crashing
- REST API blocked during OTA download to prevent heap exhaustion from concurrent pollers (HA integration, MQTT scripts, browser tabs)

### Compatibility

Fully backwards-compatible with 3.0.0. All existing REST, MQTT, and WebSocket interfaces continue to work. New fields and endpoints are additive.

The [ithowifi-ha-integration](https://github.com/arjenhiemstra/ithowifi-ha-integration) v0.4.0+ requires this firmware for the native update entity; v0.5.0+ requires it for per-remote fan entities.

### Firmware binary

https://github.com/arjenhiemstra/ithowifi/releases/download/Version-3.1.2/nrgitho-v3.1.2.bin

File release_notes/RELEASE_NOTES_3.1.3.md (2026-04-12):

## Version 3.1.3

Latest stable release. Supersedes all previous 3.1.x releases.

### Bug Fixes

- **"Retrieve settings" triggered an accidental OTA firmware reinstall** ([#359](https://github.com/arjenhiemstra/ithowifi/issues/359)) — the websocket message `{"ithogetsetting": true, "index": 0, "update": false}` contained an `"update"` key with a boolean value. The websocket and MQTT handlers only checked `isNull()` on the `"update"` key, not its type, so the boolean `false` was interpreted as a string and triggered `triggerOTAUpdate()`. Fixed by adding a `is<const char *>()` type check so only string values (`"stable"`, `"beta"`, `"auto"`) are accepted as OTA commands.
- **JavaScript console error: Maximum call stack size exceeded on `messageHandlers.systemstat`** — the Update page's inline script wrapped the `systemstat` handler with a decorator every time the page was loaded. Navigating to the Update page multiple times built up recursive layers until the call stack overflowed. Fixed by guarding the decorator with a one-time flag.

### Firmware binary

https://github.com/arjenhiemstra/ithowifi/releases/download/Version-3.1.3/nrgitho-v3.1.3.bin

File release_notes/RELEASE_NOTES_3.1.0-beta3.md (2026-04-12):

## Version 3.1.0-beta3

Fixes the Home Assistant MQTT-discovery firmware-update entity for beta-channel users, adds per-remote `last_cmd` tracking so external integrations can read the last command dispatched via each remote, and fixes a silent bug in `GET /api/v2/vremotes` that caused it to return an empty response.

**⚠️ This is a beta release — please report issues at https://github.com/arjenhiemstra/ithowifi/issues**

### Highlights

- **Channel-aware HA Discovery firmware update entity** — no more bogus "update available" notifications for users running a beta, no more empty release URLs when `firmware.json` hasn't been fetched yet
- **Per-remote `last_cmd` field** in `GET /api/v2/remotes` and `GET /api/v2/vremotes`, populated when an RF SEND remote or virtual remote dispatches a user-facing fan command (low / medium / high / auto / timer1-3 / cook30 / cook60 / away / autonight / etc.)
- **`GET /api/v2/vremotes` now actually returns data** — previously silently returned `{}` due to a `JsonDocument::as<>()` vs `to<>()` bug

### New Features

- **`add-on_update_channel` and `add-on_latest_for_channel`** added to `GET /api/v2/deviceinfo`. The channel is auto-detected from the running firmware version: a pre-release string (`-beta` / `-rc` / `-alpha` / `-dev`) pins the device to the beta channel, otherwise stable. `add-on_latest_for_channel` is clamped to the installed version if no newer firmware is available on the active channel — this means HA's update entity stays quiet for beta users running the latest beta, and never shows an empty `latest_version` if `firmware.json` hasn't been fetched.
- **HA Auto Discovery update entity** value template updated to use `add-on_latest_for_channel` for both `latest_version` and the GitHub `release_url`. The `release_url` is now computed dynamically from the template instead of baked in at discovery publish time.
- **`payload_install` is now `{"update":"auto"}`** — resolves on the device to stable or beta based on the running version, so the install button always installs the channel matching what the user is currently on. No more accidental downgrades for beta users.
- **MQTT command `{"update":"auto"}`** — new value accepted on the command topic, equivalent behavior to the new `payload_install`. The existing `"stable"` and `"beta"` values continue to work unchanged.
- **`last_cmd` field on RF SEND remotes** — populated in `ithoExecRFCommand()` after a successful dispatch, only for remotes with function `SEND`. Visible in the new `remotes` array of `GET /api/v2/remotes`.
- **`last_cmd` field on virtual remotes** — populated in `sendRemoteCmd()` (the chokepoint for all vremote command dispatch). Visible in `GET /api/v2/vremotes` response under `vremotesinfo[*].last_cmd`.
- **New helpers in `IthoRemote`**: `setLastCmd(index, cmd)`, `getLastCmd(index)`, and `static ithoCommandToShortName(code)` for converting `IthoCommand` enum values to their short lowercase API names.

### Bug Fixes

- **`GET /api/v2/vremotes` returned an empty object.** The handler used `JsonDocument::as<JsonObject>()` on a fresh document, which returns a null `JsonObject`, so `virtualRemotes.get(obj, "vremotesinfo")` silently wrote into a dead object. Fixed to use `data.to<JsonObject>()` to match the sibling `handleGetRemotes`. Any caller of `/api/v2/vremotes` now gets the actual virtual remote configuration.
- **Beta user on `3.1.0-beta2` saw bogus "update to 3.0.0" notification in HA** (issue #358). Fixed by the new channel-aware logic above.
- **Empty `release_url` in HA** when `firmware.json` hadn't been fetched (issue #358) — the link ended at `.../releases/tag/Version-` with nothing after it. Fixed by clamping `add-on_latest_for_channel` to the installed version when no newer version is known.

### API

- **CHANGED**: `GET /api/v2/deviceinfo` — new fields `add-on_update_channel` and `add-on_latest_for_channel`
- **CHANGED**: `GET /api/v2/remotes` — `remotes` array entries now include `last_cmd` when a command has been dispatched via a SEND remote
- **CHANGED**: `GET /api/v2/vremotes` — now actually returns the `vremotesinfo` array (was returning empty), entries now include `last_cmd` when a command has been dispatched
- **CHANGED**: MQTT command topic — accepts `{"update":"auto"}` in addition to `"stable"` / `"beta"`
- **UNCHANGED**: `remotesinfo` shape (used by MQTT publish, legacy WebAPIv1, and the `remotesinfo` field of `GET /api/v2/remotes`) — fully backwards-compatible. The existing `capabilities.lastcmd` / `capabilities.lastcmdmsg` fields on RX remotes are untouched

### Compatibility

Fully backwards-compatible with 3.1.0-beta2.

- Existing REST fields all still present with their previous shapes; new fields are additive.
- Existing MQTT discovery consumers see a firmware update entity that behaves correctly for the first time if they're on a beta, and unchanged if they're on stable.
- The `POST /api/v2/debug` update actions (`update`, `update_beta`, `update_url`) are unchanged.
- `capabilities.lastcmdmsg` on RX remotes (used by HA discovery templates) is untouched.

### Closes

- [#358](https://github.com/arjenhiemstra/ithowifi/issues/358) — Wrong URL in release notes link for firmware update (Home Assistant)

### Firmware binary

Firmware binary (CVE HW rev.2 and NON-CVE):
https://github.com/arjenhiemstra/ithowifi/releases/download/Version-3.1.0-beta3/nrgitho-v3.1.0-beta3.bin

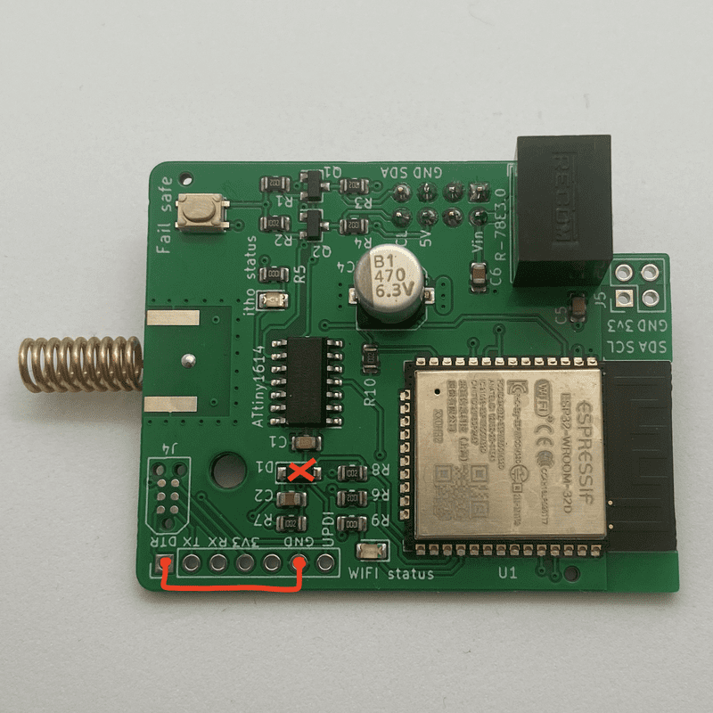
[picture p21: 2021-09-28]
images/wiki/hw-issue1.png

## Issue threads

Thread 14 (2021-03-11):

Looks like faulty flash memory

t3hk0d3, 2021-03-11:
Looks like i've found an issue when an add-on module is used with a wifi mesh network.

When the module first starts with its own AP network everything works fine, even connects to specified Wi-Fi after a soft restart from WebUI.

However, after hard restart (pulling MV plug from the outlet) it never connects to the configured WiFi network.
Wi-Fi LED never flashes.

Only rebooting into fail-safe mode helps.

I've tried it with a regular (non-Mesh) wifi network, and it works fine.

I think it gets confused when several different APs respond to the same SSID.

Firmware version: 2.1.2

TD-er, 2021-03-11:
What I do in ESPEasy is to perform a scan and pick out all known SSIDs and keep records of the best RSSI + BSSID + channel.
Then I connect to the specific AP with the best RSSI by handing over the BSSID + channel to the WiFi.begin call.

Maybe that will help here too?

N.B. do you use hidden SSIDs?

t3hk0d3, 2021-03-11:
@TD-er No, SSID is visible.

TD-er, 2021-03-11:
Some mesh APs support a range of acceptable RSSI values for the initial connection and some threshold for kicking it so it will reconnect to another AP in the mesh.
Maybe you can check your AP settings / logs to see why it can't reconnect?

t3hk0d3, 2021-03-11:
@TD-er MV is quite close to Wi-Fi AP. Also it connects and works fine after soft-reset. Problem is hard-reset.

t3hk0d3, 2021-03-11:
I'll try to get my hands on the FTDI serial port connector, maybe logs can provide more information.

t3hk0d3, 2021-03-11:
Also it should create WiFi hotspot if it can't connect to Wi-Fi network, but it doesn't happen:

https://github.com/arjenhiemstra/ithowifi/blob/master/software/NRG_itho_wifi/09_init_code.ino#L279

arjenhiemstra, 2021-03-11:
If @TD-er is out of ideas and starts asking for a real developer than I'm scared ;-)

@t3hk0d3, with a hard-restart you mean a power cycle of the itho I guess? In that case, does the itho status led light up briefly (depending on you itho model somewhere between 1 and 7 seconds) and thereafter turns off?

TD-er, 2021-03-11:
Could it be the node is waiting for a DHCP indefinately?

t3hk0d3, 2021-03-11:
@arjenhiemstra
exactly. Itho status flashes briefly and nothing flashes afterwards.

@TD-er
I'd seen it connected to wifi ap in peer list. Also with soft-reset it works flawlessly.

arjenhiemstra, 2021-03-11:
Ok thanks, that confirms that you waited long enough before powering on again (I have seen otherwise so please forgive me for checking)

If the wifi status led doesn't show any activity after 'cold' start this indicates a hardware issue.
Before anything else happens the add-on checks the failsave pin, the wifi status led then flashes rapidly about 5x a second. Only after this part of the code anything Wifi related starts.
Your description of the issue indicates the code never reaches the part where even the pin status check happens. My conclusion is then that this cannot have anything to do with the wifi settings or code but must be something in hardware or closely related.

t3hk0d3, 2021-03-11:
@arjenhiemstra well, a fail-safe pin works for me, and I can connect to the 192.168.4.1/update page. Power-cycling MV box (with waiting until capacitors discharge), connecting to AP hotspot, configuring wifi and doing soft-reset make it works....until next power cycle.

arjenhiemstra, 2021-03-11:
I know and agree it is not completely logical and I don't not exactly what the reason could be. But I know for sure that there is one piece of code that gets executed before anything else, flash the led. In all circumstances, before anything gets loaded, whatever the config is.
If the wifi led doesn't flash on power on, the code doesn't start is my conclusion. There is normally nothing you as a user can do to influence that proces (at least not with the firmware versions I publish).
I'm happy to supply you with a replacement module, I will include a return label so that you can return the current module.

t3hk0d3, 2021-03-11:
@arjenhiemstra Strange thing when I short fail-safe pin WiFi led flashes normally. I made a short video to illustrate issues:
https://www.youtube.com/watch?v=wVbBjLmOQwU&feature=youtu.be

My Tindie order Id is #251001.

arjenhiemstra, 2021-03-11:
>Strange thing when I short fail-safe pin WiFi led flashes normally.
That contradicts my line of thinking. Very strange.

If you could test the following (only use DHCP please cause there is a static IP bug in this version)
Please install firmware version 2.1 instead of 2.1.1 or the 2.2 beta version and test if the issues are still there? There has been a small change in 2.1.1 to the failsafe code, basically the first since version 2.0. You never know.... maybe I'm overlooking something stupid here

t3hk0d3, 2021-03-12:
@arjenhiemstra I've tried 2.1, unfortunately it has same behavior.

arjenhiemstra, 2021-03-12:
Ok, thanks a lot for trying! I will send you a new module later today.

t3hk0d3, 2021-03-12:
> Ok, thanks a lot for trying! I will send you a new module later today.

Dankjewel! I am looking forward for it.

arjenhiemstra, 2021-03-14:
Have you had a change to try the replacement module?

t3hk0d3, 2021-03-15:
@arjenhiemstra Yes, replacement module works perfectly. Thanks a lot!

arjenhiemstra, 2021-03-15:
Great! Then I'll close the issue.

Closed 2021-03-15.

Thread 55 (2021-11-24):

HRU 350 firmware v4 support

janbredenbeek, 2021-11-24:
I have a HRU 350 with firmware v4 and a 'retrieve settings' command returns an error 'Message: Settings not available for this device or its firmware version'. Also status information doesn't return any useful results.

arjenhiemstra, 2021-11-24:
[NRG_itho_wifi.ino.esp32.bin.zip](https://github.com/arjenhiemstra/ithowifi/files/7599018/NRG_itho_wifi.ino.esp32.bin.zip)
Could you test this firmware?

janbredenbeek, 2021-11-25:
I do get status information now (thanks!)
When retrieving settings I do get the descriptions but no values (only the 3 bullets), and then it seems to lose connection.
Haven't tested the remotes yet (I have touch key remotes, one Co2 and one RH).

arjenhiemstra, 2021-11-25:
I heard the same from Jasper in this issue:
https://github.com/arjenhiemstra/ithowifi/issues/54

I need to dive in a bit further to find out what is happing. Thanks for testing!

jasperslits, 2021-11-29:
Copy of setting current values didn't quite work but they look OK.
For status 'label out of bound error' is still there.

**Status:**

Label | Value
---- | ----
Requested fanspeed (%) | 6552.6
Balance (%) | 149.8
Supply fan (RPM) | 1141
Supply fan actual (RPM) | 1148
Exhaust fan (RPM) | 762
Exhaust fan actual (RPM) | 768
Supply temp (°C) | 11.65
Exhaust temp (°C) | 4.96
Status | 0
Room temp (°C) | 11.65
Outdoor temp (°C) | 4.96
Valve position | 0
Bypass position | 0
Summercounter | 0
Summerday (K_min) | 0
Frost timer | 0
Boiler timer | 177
Frost block | 120
Current position | 0
VKKswitch | 0
GHEswitch | 0
Airfilter counter | 3040
Global fault code | 0
Actual Mode | 24
Pir fan speed level | -1
Highest received CO2 value (Ppm) | 436
Highest received RH value (%RH) | 239
Air Quality (%) | 100
Remaining override timer (Sec) | 0
Fallback speed timer (Sec) | 0
label out of bound error | 0

**Settings**

index|label|current|min|max
-- | -- | -- | -- | --
 0 | Percentage set 2 (%) |   | 25 | 60
1 | Temp frost protection (°C) || 0 | 7
2 | Frost temp offset (°C) || 5 | 25
3 | Min frost speed (%) || 0 | 25
4 | Max frost speed (%) || 10 | 30
5 | Frost supply fan off time (Sec) || 60 | 7200
6 | Frost supply fan on time (Sec) || 60 | 1500
7 | Frost speed change (%) || 1 | 50
8 | Frost speed change (%) || 0 | 0
9 | Max ratio exhaust - supply during frost protection (%) || 100 | 200
10 | Summer temp (°C) || 15 | 25
11 | Summer temp GHE (°C) || 12 | 25
12 | Summer day time (K*hr) || 5 | 15
13 | Wanted temp bypass regulation (°C) || 15 | 30
14 | Offset bypass regulation (K) || 1 | 50
15 | Max bypass open time (hrs) || 24 | 240
16 | Max rpm fast var. Pwm (RPM) || 1000 | 2000
17 | Max rpm slow var. Pwm (RPM) || 1500 | 2500
18 | Max rpm fast fixed pwm (RPM) || 2000 | 2800
19 | Speed offset (RPM) || 15 | 75
20 | High frequency var pwm (kHz) || 15 | 20
21 | Low frequency var pwm (kHz) || 10 | 18
22 | High frequency fixed pwm (kHz) || 5 | 10
23 | Low frequentie fixed pwm (kHz) || 1 | 4
24 | Start speed vkk exhaust fan (%) || 0 | 10
25 | Vkk valve close time (Sec) || 10 | 180
26 | Rpm exhaust fan with min position potmeter low (RPM) || 500 | 1500
27 | Rpm exhaust fan with max position potmeter low (RPM) || 0 | 0
28 | Rpm exhaust fan with vkk with min position potmeter low (RPM) || 700 | 1700
29 | Rpm exhaust fan with vkk with max position potmeter low (RPM) || 1700 | 2700
30 | Rpm exhaust fan with min position potmeter high (RPM) || 2000 | 2500
31 | Rpm exhaust fan with max position potmeter high (RPM) || 2500 | 3500
32 | Min rpm supply fan (RPM) || 500 | 2500
33 | Max rpm supply fan (RPM) || 2000 | 3500
34 | Min value balance setting (%) || 20 | 100
35 | Max value balance setting (%) || 100 | 200
36 | Min zeta supply value || 0 | 50
37 | Max zeta supply value || 0 | 50
38 | Stop both motors with motor fault || 0 | 1
39 | Correction rpm with min rpm during bypass (%) || -50 | 50
40 | Correction rpm with max.rpm during bypass (%) || -50 | 50
41 | HRU version || 0 | 255
42 | OEM value || 0 | 100
43 | Supply fan of during vkk test || 0 | 1
44 | Manual control || 0 | 1
45 | Manual speed supply fan (RPM) || 0 | 3500
46 | Manual speed exhaust fan (RPM) || 0 | 3500
47 | Manual valve position || -800 | 800
48 | Air quality || 5 | 15
49 | Filter live time (Month) || 0 | 24
50 | Filter counter (Hours) || 0 | 4294967295
51 | Output Constant Ca2 || 0 | 0
52 | Output Constant Ca1 || 0 | 0
53 | Output Constant Ca0 || 0 | 0
54 | Output Constant Cb2 || 0 | 0
55 | Output Constant Cb1 || 0 | 0
56 | Output Constant Ca0 || 0 | 0
57 | Output Constant Cc2 || 0 | 0
58 | Output Constant Cc1 || 0 | 0
59 | Output Constant Cc0 || 0 | 0
60 | Supply Constant Ca2 || 0 | 0
61 | Supply Constant Ca1 || 0 | 0
62 | Supply Constant Ca0 || 0 | 0
63 | Supply Constant Cb2 || 0 | 0
64 | Supply Constant Cb1 || 0 | 0
65 | Supply Constant Cb0 || 0 | 0
66 | Supply Constant Cc2 || 0 | 0
67 | Supply Constant Cc1 || 0 | 0
68 | Supply Constant Cc0 || 0 | 0
69 | PIR level 1 (%) || 0 | 100
70 | PIR level 2 (%) || 0 | 100
71 | PIR level 1 wait time (sec) || 1 | 600
72 | PIR level 2 wait time (sec) || 10 | 600
73 | PIR run-on level 1 (sec) || 10 | 3600
74 | PIR run-on level 2 (sec) || 10 | 3600
75 | Max time High speed (Min) || 0 | 1440
76 | Max time other speeds (Min) || 0 | 2880
77 | Fallback previous speeds (-) || 0 | 1
78 | PoorCo2Quality (ppm) || 1501 | 2000
79 | GoodCo2Quality (ppm) || 500 | 1500
80 | Number of floors (floor) || 1 | 2
81 | Inhabitants (inhab) || 0 | 3
82 | Min ventilation level multi-floor (%) || 0 | 100
83 | Min ventilation level one-floor (%) || 0 | 100
84 | Night min vent optima 1 multi-floor 1 person (%) || 0 | 100
85 | Night min vent optima 1 multi-floor 2 persons (%) || 0 | 100
86 | Night min vent optima 1 multi-floor 3+ persons (%) || 0 | 100
87 | Night min vent optima 1 one-floor 1 person (%) || 0 | 100
88 | Night min vent optima 1 one-floor 2 persons (%) || 0 | 100
89 | Night min vent optima 1 one-floor 3+ persons (%) || 0 | 100
90 | Night min vent optima 2 multi-floor 1 person (%) || 0 | 100
91 | Night min vent optima 2 multi-floor 2 persons (%) || 0 | 100
92 | Night min vent optima 2 multi-floor 3+ persons (%) || 0 | 100
93 | Night min vent optima 2 one-floor 1 person (%) || 0 | 100
94 | Night min vent optima 2 one-floor 2 persons (%) || 0 | 100
95 | Night min vent optima 2 one-floor 3+ persons (%) || 0 | 0
96 | Summer night boost enable (-) || 0 | 1
97 | Summer night degree (-) || 0 | 100
98 | Summer night setpoint (°C) || 15 | 35
99 | Summer night boost ventilation level (%) || 30 | 100
100 | Summer night max area degree hours (-) || 0 | -0.1
101 | FrostTimer (sec) || 0 | 9999
102 | StartupCounter (sec) || 0 | 125
103 | BoilerTestTimer (min) || 0 | 360
104 | SummerCounter (K_min) || 0 | 900
105 | BypassTimer (min) || 0 | 20
106 | MaximumOpenCounter (min) || 0 | 14400
107 | FilterUsagePerMin (-) || 0 | 6001
108 | Balance (%) || 0 | 200

arjenhiemstra, 2021-11-29:
Labels and settings do match with the DB, so that is fine. The out of bound error should mean that the length read from the status format query is different from what mapping, which is strange cause it seems that the result does match.

Could you post the result of the status format query?

jasperslits, 2021-11-29:
Result of status format: 80 82 A4 00 01 21 91 11 10 90 10 90 92 92 00 92 92 00 00 91 00 10 10 00 90 00 00 10 00 00 90 90 00 0F 10 10 00 91 00 DD

Status itself: 80 82 A4 01 01 35 FF F6 05 DB 04 7C 04 76 02 FE 02 FB 04 7C 02 01 00 04 7C 02 01 00 00 00 00 00 00 00 00 B1 78 00 00 00 00 0B E1 00 18 FF FF 01 9E EF C8 00 00 00 00 02 00 05 00 C9

arjenhiemstra, 2021-11-29:
thanks, we might have found a bug in the itho firmware here...
Length according to the status format: 21 = 33 decimal
Length according to the itho service tool, 30 decimal

jasperslits, 2021-11-29:
But I don't quite get on why it was working before? That itho firmware bug must have been there from the beginning, no?

arjenhiemstra, 2021-11-29:
Well, it is still working as before... I just included code to check for these kind of issues cause normally this would mean the mapping is missing some references. But in this case it shines light on itho firmware issues as well.

jasperslits, 2021-11-29:
Thanks. For now it's probably fine to leave it as-is. It doesn't look pretty all the relevant statuses are showing up.

But maybe @janbredenbeek has more problems when he checks the results...

janbredenbeek, 2021-11-29:
Now able to retrieve the settings (similar to @jasperslits).  👍
Also still get label out of bound error at end of status...

arjenhiemstra, 2021-11-30:
Implemented with version 2.3.0
https://github.com/arjenhiemstra/ithowifi/releases/tag/Version-2.3.0

Closed 2021-11-30.

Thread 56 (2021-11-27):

CC1101 failed to initialize

jasperslits, 2021-11-27:
**Describe the bug**
Non-CVE unit with latest firmware doesn't detect CC1101 properly. This is showing up when connected to either WPU or HRU-350. This used to work fine but I cannot recall since when it didn't work as I had format the add-on and switched it between HRU and WPU as I only had 1 device.

**To Reproduce**
Steps to reproduce the behaviour:
1) Go to System settings
2) Enable Itho RF Remote Support
3) Reboot
4) Device should be available immediately but it's then inaccessible
5) When the add-on web page is eventually is available CC1101 is disabled in the menu

**Expected behaviour**
RF Remotes shown in left menu, immediate availability.

**Debug logging**
Logs:
2021-11-27 13:08:17 N: IP:192.168.178.37
2021-11-27 13:08:17 N: Setup: Virtual remote ID: 128,223,108
2021-11-27 13:08:17 N: Webserver: started
2021-11-27 13:08:18 N: Setup: init of CC1101 RF module successful
2021-11-27 13:08:18 N: mDNS: started
2021-11-27 13:08:18 N: Hostname: wpu
7377 N: Setup: done
2021-11-27 13:08:26 N: System boot, last reset reason: DEEPSLEEP_RESET
2021-11-27 13:08:26 N: HW rev: NON-CVE 1, FW ver.: 2.3-beta6
2021-11-27 13:08:31 N: WiFi: connection successful
2021-11-27 13:08:31 N: WiFi info:
2021-11-27 13:08:31 N: Mode:STA
2021-11-27 13:08:31 N: Status:3
2021-11-27 13:08:31 N: IP:192.168.178.37
2021-11-27 13:08:31 N: Setup: Virtual remote ID: 128,223,108
2021-11-27 13:08:31 N: Webserver: started
2021-11-27 13:08:31 N: mDNS: started
2021-11-27 13:08:31 N: Hostname: wpu
2021-11-27 13:08:31 N: Setup: done
2021-11-27 13:08:33 N: Setup: init of CC1101 RF module failed
2021-11-27 13:08:37 N: System boot, last reset reason: SDIO_RESET
2021-11-27 13:08:37 N: HW rev: NON-CVE 1, FW ver.: 2.3-beta6
2021-11-27 13:08:42 N: WiFi: connection successful
2021-11-27 13:08:42 N: WiFi info:
2021-11-27 13:08:42 N: Mode:STA
2021-11-27 13:08:42 N: Status:3
2021-11-27 13:08:42 N: IP:192.168.178.37
2021-11-27 13:08:42 N: Setup: Virtual remote ID: 128,223,108
2021-11-27 13:08:42 N: Webserver: started
2021-11-27 13:08:42 N: mDNS: started
2021-11-27 13:08:42 N: Hostname: wpu
2021-11-27 13:08:42 N: Setup: done

**Device information**
- Firmware version [e.g. 2.2.1] 2.3-b6
- Hardware revision (e.g. non-cve 1.1) non-cve 1
- Type/model number Itho (on sticker outside the box) HRU-350
- CC1101 RF module enabled [ yes, no ] yes
- In case of wifi issues, wifi access point make and model: N/A

**Desktop (please complete the following information):**
 - OS: [e.g. iOS] MacOS Monterey
 - Browser [e.g. chrome, safari] Safari
 - Version [e.g. 22] 15

arjenhiemstra, 2021-11-29:
I cannot reproduce this. It might indicate a hardware issue where either a solder joint of the cc1101 module isn't connected anymore or the module itself is broken.

jasperslits, 2021-11-29:
A visual check didn't yield anything. I noticed that it does say 'CC1101 task memory: 0 bytes free' but seems to show up also for devices without the CC1101?

Maybe there's indeed something wrong as this was also giving issues when doing the level3 debugging for the WPU.
Could it be damaged by connecting this unit to the WPU? Maybe the CC1101 doesn't really like that?
The add-on itself works fine with the WPU...

arjenhiemstra, 2021-11-29:
>I noticed that it does say 'CC1101 task memory: 0 bytes free'

That's normal if the module is not active

>Could it be damaged by connecting this unit to the WPU? Maybe the CC1101 doesn't really like that?

No, the CC1101 module is connected only to the ESP32 and if somehow a power spike damaged the board then the ESP32 should be dead as well. I always test the board after soldering because sometimes the solder joint seems ok but does not make contact. It could be that in this case a join was barely making contact (which could also explain issues with debug indeed) and is now not making contact anymore at all.
You could test it with a conductivity / diode meter of a multimeter. If it doesn't sort it out I will repair / replace the module.

jasperslits, 2021-11-29:
And this one worked fine for several weeks so definitely something happened. But it maybe explains the lockups when doing the debugging for the WPU control commands...

Do you have a picture of the back of the non-CVE unit with CC1101 so I can do a comparison against my board?
[https://github.com/jasperslits/ithowiki_content/blob/master/IMG_0500.jpeg](url)

It's a bit blurry, no idea why.

jasperslits, 2021-12-19:
I ordered a new one with CC1101, so we can resume our WPU temp control attempt. I don’t have a multimeter and the unit works fine so that is now connected to autotemp unit in the attic.

Closed 2021-12-19.

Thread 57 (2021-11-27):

CVE ECO-fan 2 incompatible

Mickroz, 2021-11-27:
Ik kan bevestigen dat bovenstaande fan niet compatible is 🤣
Geen aansluiting om de wifi addon te installeren.
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

arjenhiemstra, 2021-11-29:
as documented

Closed 2021-11-29.

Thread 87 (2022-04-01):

Debug page - Descriptions for debug level3 (Feature)

jasperslits, 2022-04-01:
Feature request, not a bug.

On the Debug page you have now 3 buttons which is an improvement over what we had before: Off, level 1, level2, level3

There is however no documentation (other than on the Remotes wiki page) that explains the different levels.
I think it's a good a idea to have this on the webpage of the module.

E.g.
Level 1: Use this with non-working remotes.
Level 2: Use this for ....
Level 3: Show IDs and commands for all packets received, also non itho devices and can clutter the interface.

(I was playing with Level 3 to see how zone temperature settings (with autotemp units) were coming along and couldnt figure when to use level 2)

jasperslits, 2022-04-01:
And related: https://github.com/arjenhiemstra/ithowifi/wiki/Remotes mentions to copy the ID but remotes.json expects decimals while the debug output (with level3) is hex, so you need to convert the numbers from the output from hex to decimal unless I miss anything?

My use-case: adding remotes without having to pair / join them first to avoid power cycles.

arjenhiemstra, 2022-04-15:
I'll update the info in the interface to make this clear

>My use-case: adding remotes without having to pair / join them first to avoid power cycles.

Adding remotes to the add-on is always possible without a power cycle or do I not correctly understand the issue here

jasperslits, 2022-04-15:
I have three remotes (https://www.ventilatieland.nl/artikel/25035/itho-daalderop-rft-co2-sensor-opbouw-met-bediening-230-volt-04-00045.html) on 3 different floors that I needed to pair again to the add-on in order to read their CO2 values in Home Assistant.

I didn't want to do the manual pairing (power cycle / disconnect them from 230v and then put into pairing mode) and I didn't have a backup to restore. I only realised later the HRU-350 cycle was not even needed but still the 'connect-remotes-without-leaving-the-desk' applies.

arjenhiemstra, 2022-04-15:
That clears it up, thx!

jasperslits, 2022-05-01:
Part of alpha6

Closed 2022-05-01.

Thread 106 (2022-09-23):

Control via add-on stops working

RPJacobs, 2022-09-23:
**Describe the bug**
I installed two add-ons (with CC1101) on two CVE-Silent

Itho device type: CVE-Silent
Itho fw version: 11

They both work initially, enabled MQTT -> Homebridge -> Apple Homekit, removed remote from unit and joined the add-on. (works great, thanks Arjen!)

But after a tmie the fan on the ground floor stops controlling the Itho Fan. I can login to the web interface and retrieve the settings, run all debug  queries but not controle the fanspeed! I2C not working? Status page indicates connected... After a power cycle the unit works as accepted then stops again.

Can your please advice?

**To Reproduce**
not sure what is going wrong...

**Expected behaviour**
control the fan by MQTT or the web interface.

**Screenshots**

**Device information**
Configuration of the Itho unit:
Itho device type: CVE-Silent
Itho fw version: 11

- Hardware revision (e.g. non-cve 1.1)

Current firmware version: 2.3.5
Hardware revision: 2

- Type/model number Itho (on sticker outside the box)
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

- CC1101 RF module enabled [ yes, no ] YES
- In case of wifi issues, wifi access point make and model: No issue

**Debug logging**
Please provide debug logging from the debug page if possible:
[logfile0.current (2).log](https://github.com/arjenhiemstra/ithowifi/files/9632668/logfile0.current.2.log)

arjenhiemstra, 2022-09-26:
If debug queries still give a valid result than 9 out of 10 times the fan is not in the correct mode for (PWM2I2C) control.
If the situation occurs again, please go to the Itho status page off the add on and post the value of the label "FanInfo"

On the wiki there is some more info about this:
https://github.com/arjenhiemstra/ithowifi/wiki/Controlling-the-speed-of-a-fan

RPJacobs, 2022-09-26:
Thank for the reply! Dump question but there is no FanInfo on the status page:

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

But I did find:

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

RF Mode it is....

RPJacobs, 2022-09-26:
It’s in the initial post:

Itho device type: CVE-Silent
Itho fw version: 11

arjenhiemstra, 2022-09-26:
> It’s in the initial post:
>
> Itho device type: CVE-Silent Itho fw version: 11

Doh, sorry! Overlooked that..... grrr

RPJacobs, 2022-09-26:
I joined the remote to the fan and removed it again. Then joined the addon again. Now it does not stop working! Also updated to 2.4.0

RPJacobs, 2022-09-26:
If you need more info about the fan contact me directly.

arjenhiemstra, 2022-09-26:
Ah now I see, "Selection" is comparable with "FanInfo" on newer itho models.
This is the table:
0 Off
1 Holiday
2 Low
3 Nominal / auto
4 High
5 Timer

Your fan on the low setting and should be on 2 or Nominal/auto. Probably if you powercyle the unit it will be on 3. Something pushed you itho out of mode 3. Most probably that is a remote (either physical of virtual)

arjenhiemstra, 2022-09-26:
> If you need more info about the fan contact me directly.

Thanks! I'll update the wiki with this info, very helpful! Thanks for creating an issue!

Closed 2022-09-26.

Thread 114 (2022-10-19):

RFE: ability to set itho settings via API

rplevka, 2022-10-19:
**Describe the bug**
It would be useful to be able to set the itho settings (Manual control, bypass valve position, target rpm, reset filter day counter, ...) using API.

these values are already published for reading, but in order to set any of them, I still need to manually set them via UI - this prevents me from using this in my automation, which makes the use of the addon quite limiting.

**Expected behaviour**
since some might consider these settings - "advanced", there could be some opt-in setting (with an appropriate warning message) to enable this api endpoint

**Device information**
- Firmware version [e.g. 2.4.2]
- Hardware revision (e.g. cve 2)
- Type/model number Itho (ECO HRU350)
- CC1101 RF module enabled [ yes ]

arjenhiemstra, 2022-11-08:
I understand the request and you are not the first to ask it. There is a certain danger and difficulty with this.
first: every itho device and even every firmware has a different set of settings
second: errors are easily made and difficult to revert, even with the current web based solution I sometimes get support requests to help users to restore settings...

So an opt-in would be minimum, but I'm still not sure if this at all is a wise move

rplevka, 2022-11-10:
perhaps a flag in the source code that one would have to uncomment and build the firmware themselves?

DutchMikeDutch, 2022-11-16:
I fully understand people can wrongly configure the devices nevertheless to overrule the device in certain situation. I rather have the ability to set settings via an automation on Home Assistant then manually going to the Website and setting it to Manual mode and execute. building a mouseclick script is a bit overkill no?

YorickPeterse, 2023-01-12:
I'm currently evaluating the WiFi add-on, though for a somewhat particular reason: I have an HRU 350 with the Demandflow/Controlflow system attached. This seems to result in it being impossible to reset the filter status, as also discussed on https://gathering.tweakers.net/forum/list_messages/2005642.

The workaround is to buy the ridiculously expensive service interface (€300), then use the Itho service tool to reset it (which in turn seems to only work on Windows. Unfortunately, it seems this interface isn't sold directly to consumers as far as I've been able to find, meaning you need to buy it through your local installation company; assuming they even want to do that.

If the WiFi add-on were to support this, it would prove a much more affordable (and probably easier to use) alternative to work around this problem :smiley:

arjenhiemstra, 2023-01-12:
I have an official service tool for my R&D work. Also the filter reset code is already present in the add-on firmware (although I have not been able to test it because I do not have access to a HRU350)
How you could test it:
first have a recent firmware version where you can select the virtual remote type (ie. latest beta fw version will do)
1- connect the add-on to the HRU
2- configure the first virtual remote to be of the type: RFT AUTO
3- unplug the power from the HRU, wait a bit and power it again
4- within 2 mins. on the virtual remotes page click the join button of the first virtual remote
5- confirm you are able to control the speed of the HRU by clicking ie. high and low buttons on the same page
6- go to the debug page and click the button "filter reset", that should do the trick

YorickPeterse, 2023-01-12:
@arjenhiemstra Thanks for the details. I'll likely buy the add-on this week then, and report back once I've tested it :smiley:

gns1l, 2023-01-13:
Nov last year I tried to reset the filter warning with my remote without success. Then I tried the filter reset command on the Itho-wifi debug page. Also without success. In the end I just changed the filter counter to zero hours. That worked.
vremote is functional but I'm not sure which type.

rplevka, 2023-01-13:
I can confirm i managed to successfully reset the filter "alarm" on my HRU350 using the addon. resetting via the Remote control didn't work for me either

YorickPeterse, 2023-01-14:
I received the module today and managed to get it up and running. As I have a Demandflow/Qualityflow system, the use of an RFT AUTO virtual remote didn't seem to result in it being able to control anything; instead I had to set up the virtual remote as a RFT DF/QF remote. I paired it with the DF/QF control panel, as it seems the HRU ECO 350 doesn't respond to pairing when the DF/QF control panel is hooked up.

In this setup the "Filter reset" button doesn't seem to do anything. Oddly enough, the only filter related setting on the Itho settings page is "Filter factor", set to a value of 5. The reported Itho firmware version is 21.

Should I in this case set up an extra virtual remote and pair that directly with the HRU?

YorickPeterse, 2023-01-14:
I just tried to hook the module up to the HRU's COM port. This port doesn't provide any power so I also had to plug in a USB cable. In this scenario the module is seemingly unable to detect what it's connected to, and thus isn't able to retrieve any settings.

If I had to guess, I suspect the DF/QF control panel simply doesn't read/write the filter related settings, hence the official remotes don't support resetting the filter either.

YorickPeterse, 2023-01-14:
Updating to the beta firmware doesn't seem to have any impact on the filter status being reported. Is there anything I can do to debug this (or any information I can provide to help with that)?

YorickPeterse, 2023-01-14:
After much fiddling I managed to pair a bunch of RFT Auto virtual remotes. It seems the official documentation isn't entirely correct, or maybe my setup was weird: I had to pair my physical DF/QF remote 2-3 times, then press the bottom left/right (previous and next) button once, then all the lights blink and you can start assigning rooms. From that point on you follow the manual, selecting rooms and pairing the next virtual remote. Getting this right took several tries, but now it works.

Unfortunately, the "Reset filter" button still doesn't do anything in this case, even though remote 0 is an RFT Auto one. This further suggests the DF/QF control panel just doesn't forward the signal to the HRU.

rplevka, 2023-01-15:
@YorickPeterse try navigating to `Itho Settings` -> `Retrieve Settings`, then wait till all the values are read and populated.
then try to set Option no. 50:
`Filter counter (Hours)` to `0`. Good luck!

YorickPeterse, 2023-01-15:
@rplevka Unfortunately, I don't have such a setting, and option 50 is "Sample measurement interval (sec)" in my case :confused:

gns1l, 2023-01-15:
@YorickPeterse: Is the module connected to the HRU 350?

YorickPeterse, 2023-01-15:
@gns1l As mentioned in https://github.com/arjenhiemstra/ithowifi/issues/114#issuecomment-1382746884 and https://github.com/arjenhiemstra/ithowifi/issues/114#issuecomment-1382752902, my WiFi module is hooked up to the DemandFlow/QualityFlow control unit, not the HRU directly. Hooking it up directly doesn't seem to work either as no I2C connection is detected, most likely because the DF/QF unit takes over control.

rplevka, 2023-01-15:
I have 0 experience with DF/QF, but would it be a bad idea to temporarily disconnect it from the main unit?
Btw, what do the `device type` and `fw version` at the `Itho Settings` say?
Mine are:
```
Itho device type: HRU 350
Itho fw version: 3
```

gns1l, 2023-01-15:
How are the DF/QF unit and the HRU 350 connected?
Is the HRU 350 a special version?

arjenhiemstra, 2023-01-15:
> @gns1l As mentioned in [#114 (comment)](https://github.com/arjenhiemstra/ithowifi/issues/114#issuecomment-1382746884) and [#114 (comment)](https://github.com/arjenhiemstra/ithowifi/issues/114#issuecomment-1382752902), my WiFi module is hooked up to the DemandFlow/QualityFlow control unit, not the HRU directly. Hooking it up directly doesn't seem to work either as no I2C connection is detected, most likely because the DF/QF unit takes over control.

The filter can only be reset by connecting the add-on to the HRU directly.
The HRU should provide power to the add-on, it doesn’t matter whether there is a DF/QF connected through RF.
If there is no power to the add-on from the HRU, something is wrong with your HRU I’m afraid.

YorickPeterse, 2023-01-15:
@arjenhiemstra

> The filter can only be reset by connecting the add-on to the HRU directly.

I figured as much, but it's fine: I've just set a calendar reminder instead. Instead I'll be using the module to better control the WiFi (i.e. by controlling rooms better using the virtual remotes). Now I just need to settle on a Raspberry Pi or some other small computer for running my own software part of this :smile:

@rplevka The DF/QF unit is pretty crucial for the ventilation system we have, as without it there's no way to, well, ventilate the rooms. Since only the filter reset option is missing I'm just going to leave it as-is.
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
rplevka, 2023-01-20:
The manual function is what i'm actually after as I'm looking to controlling HRU350's fan speeds and a bypass/anti-freeze valve manually (sometimes).
In the future, i was considering to craft/purchase some servo-driven duct valves to introduce "zoning".
Since demand-flow seems to do just that, and you are already experimenting with it - there is one thing i'm curious about whil operating in manual mode - does the system allow you to close all the valves at the same time? if so, that might be quite dangerous as it might (probably) damage the motor.
Would you mind trying that out? :rat:

YorickPeterse, 2023-01-20:
@rplevka

I think you can't close all the valves at exactly the same time, as the DemandFlow system doesn't write back to the I2C slave until a valve reaches its desired value (at least that's what I think is happening). You can also see this in practise: when you flip the system into manual mode, it closes valves one by one instead of all at the same time.

I don't think you'd want this anyway, as this would cut off all ventilation. You'd also have to make sure the exhaust fan isn't running, or it will try to exhaust a more or less airtight plenum, and I'm not sure what the impact of that is.

philipkocanda, 2023-01-23:
Manual control is something that I'd also like to use on my HRU ECO (firmware: v12, hardware: v3) as the built-in algorithm for opening/closing the bypass is just not that great (a good attempt by the Itho folks though given the limited information it has to work with). And I like being able to turn off the supply fan when the neighbors are having a nice BBQ party (🔥), so we still have some exhaust ventilation in the bathroom when needed.

My approach to this used to be a running `rustyx/itho-esp` on a custom ESP32, and passing it messages generated by my own [custom Python library](https://github.com/philipkocanda/ithopy) over MQTT. But I prefer using the ithowifi hardware/software much more for its community and the reliability of having a dedicated piece of hardware.

I'm thinking of just having an option of passing raw messages over MQTT, which given the built-in checksum validation should be a high enough threshold to stop those who don't know what they're doing from clicking some random buttons and frying their expensive machinery.

arjenhiemstra, 2023-01-24:
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

Just FYI, rustyx' tho-esp firmware runs without changes on the ithowifi add-on (non-cve variant), no need for dangling wires :)

yorickpeterse, 2023-03-25:
Re the above bot: This PR is very much still active, I just haven't had the time yet to add the setting to enable/disable the API.

yorickpeterse, 2023-05-24:
Issue is very much still active, just pending review on https://github.com/arjenhiemstra/ithowifi/pull/144.

Closed 2023-10-31.

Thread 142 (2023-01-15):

Floating point rounding error in status

tomkooij, 2023-01-15:
**Describe the bug**
Zero not zero:
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

WPU 5G: Status values that are 0 and "float" (divide by 100) can be some small number instead of 0.
The correspoding statusvalue is `0x0000` datatype `0x92` (2 byte, divide by 100).
`0000` is cast to float and divided by 100 and some floating point rounding error occurs.
Solution: round / limit floats to 2 decimal places. Other datatype `0x92` values are rounded to 2 decimal places.
(See screenshots)

Also in MQTT:
````
"CV pressure (Bar)":2.26,"Compressor current (A)":3.62,"Current e-element (A)":0.000489009,
````

**Expected behaviour**
0 is displayed as 0 or 0.00

**Screenshots**
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

**Device information**
- Firmware version 2.4.4-beta6
- Hardware revision non-cve 2
- Type/model number Itho WPU 5G v37

This is a very minor issue. It's just my OCD. I might fix it sometime.

tomkooij, 2023-03-04:
This is a "feature" of ArduinoJson...
https://arduinojson.org/v6/how-to/configure-the-serialization-of-floats/

Adding a `round2()` function as per the docs, would fix this.

Closed 2023-05-10.

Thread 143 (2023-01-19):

Support for the ITHO HRU-3 GBL-001

galadril, 2023-01-19:
Would it be possible to add support for the ITHO HRU-3 GBL-001?

**Screenshots**
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

**Device information**
- Firmware version - 2.4.3
- Hardware revision - non-cve
- Type/model number Itho - ITHO HRU-3 GBL-001
- CC1101 RF module enabled - no

**Debug logging**
```
2023-01-19 09:02:38 I: HW rev: NON-CVE 1, FW ver.: 2.4.3
2023-01-19 09:02:44 I: WiFi: connection successful
2023-01-19 09:02:44 I: WiFi info:
2023-01-19 09:02:44 I: SSID:******| BSSID[*******]
2023-01-19 09:02:44 I: RSSI:-69dBm
2023-01-19 09:02:44 I: Mode:STA
2023-01-19 09:02:45 I: Status:WL_CONNECTED
2023-01-19 09:02:45 I: IP:*******
2023-01-19 09:02:45 I: Setup: Virtual remotes, start ID: DF,ED,E4 - No.: 1
2023-01-19 09:02:45 I: Setup: remotes configfile loaded
2023-01-19 09:02:25 I: MQTT: connected, System config: 1
2023-01-19 09:02:25 I: Webserver: started
2023-01-19 09:02:25 I: mDNS: started
2023-01-19 09:02:25 I: Hostname: nrg-itho-ede4
2023-01-19 09:02:26 I: Setup: done
2023-01-19 09:02:30 I: I2C init: QueryDevicetype - failed
```

arjenhiemstra, 2023-01-19:
Could you go to the debug page and click the button "Query devicetype" and post the result?

galadril, 2023-01-19:
Result: failed

galadril, 2023-01-19:
yes i tried with 2 cables

arjenhiemstra, 2023-01-19:
What is the length of the cable?
And would it be possible to post some pictures? I'm not sure how your HRU is build but the one I have has a daughterboard inside that houses the connectors. Is that board accessible? If so, could you post a picture of that board (I might be able to trace some PCB tracks to find out if something is physically different on your HRU.

Power comes through the UTP cable (so you have no USB adapter connected I assume)?

galadril, 2023-01-19:
mmm no lights are coming on with only the UTP cable connected.. so i assumed it needed power as well
Ill make some pictures

galadril, 2023-01-19:
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

arjenhiemstra, 2023-01-19:
> mmm no lights are coming on with only the UTP cable connected.. so i assumed it needed power as well
> Ill make some pictures

No power should come through the RJ45 connector. I2C cannot travel long distances, power can. So if that is not available the issue is somewhere in your HRU. That could mean this RJ45 connector does not support the itho service tool (in that case the add-on won't work as well) or there is something inside the HRU that disables the port.

arjenhiemstra, 2023-01-19:
You model looks almost the same from the outside but maybe it's older from the inside and not yet working with the I2C protocol? Not sure at what year tho started adopting the Honeywell ramses-ii based I2C protocol.

galadril, 2023-01-19:
>  That could mean this RJ45 connector does not support the itho service tool (in that case the add-on won't work as well) or there is something inside the HRU that disables the port.

ai that sucks.. :(

dennisvbussel, 2023-01-19:
@galadril
You could take a look in the manual [Eco Fan HRU 3](https://www.vansteenonline.nl/wp-content/uploads/ECO_FAN_HRU_3_installatie_handleding.pdf). Section 3-7 mentions that `Poort 2` is a connector that can be used to connect the HRU to a computer. Not sure if it is the i2c protocol required.

arjenhiemstra, 2023-01-19:
> @galadril You could take a look in the manual [Eco Fan HRU 3](https://www.vansteenonline.nl/wp-content/uploads/ECO_FAN_HRU_3_installatie_handleding.pdf). Section 3-7 mentions that `Poort 2` is a connector that can be used to connect the HRU to a computer. Not sure if it is the i2c protocol required.
>
> Some information can be found regarding connector/protocol on the [circuitsonline](https://www.circuitsonline.net/forum/view/65868/1) forum.

Thanks for the manual and the link. I know the circuitsonline topic (look at the last post ;-)) but it could be that there are different versions of the ecofan 3 just like there are different versions of the CVE ECO 2. Some CVE ECO 2 versions have a 9 pin in a row header, some have to 2x4 pin header. It seems that the models with the 9 pins in a row use a different communication standard. That could also be the case here with the older HRU devices.

galadril, 2023-01-19:
What can i check in the device? Do your rever to making a custom cable?

arjenhiemstra, 2023-01-19:
First of all a photo of the internals of the HRU (PCB) is needed, best to have a picture of both sides of the PCB. That will help to trace the PCB lines to hopefully get a bit of insight into what lines are connected to where. It would also be nice to have a picture of chips on the board with the designators, this will help to find datasheets that describe the chip.
After that I hope to be able to share wether it is possible to solve things be an adapter cable or that a totally different solution is needed (in which case you have to find a newer HRU or a different solution to control this HRU).
Btw, no worries, you can always sent the add-on back might we not get it working.

galadril, 2023-01-19:
ok, i need to find how to get to the PCB then, maybe the screws behind the power/utp cables.
Thanks

galadril, 2023-01-22:
I don't really get how to come to the pcb for pictures. Any tips, or does anyone have the same type?

galadril, 2023-01-31:
Btw i asked Itho for their help/input about the PCD schematics, but they we're not helping and only awnsering:

_Dit is niet mogelijk met de HRU 3, de RJ45 aansluiting is alleen voor het uitlezen met een servicetool, wij hebben hier verder geen ondersteuning voor._

galadril, 2023-04-02:
Anyone with the same device?

arjenhiemstra, 2023-09-29:
In later models (hru ecofan) the connector block is secured with just 1 screw. If you remove the screw you can easily slide out the connector module. There is even a handle like shape for that.
Is something like this not present on your itho?

arjenhiemstra, 2023-09-29:
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

Like in the picture

galadril, 2023-09-30:
ok i could get it out.. (didnt use force at all).. but pushing the unit 2 cm back probably broke my wtw :(
After putting in the power it didnt do anything anymore :(

arjenhiemstra, 2023-09-30:
Oh no! That should not happen :( Maybe just a connector dislodged inside?
I tried googling a bit and found this manual:
https://www.vansteenonline.nl/category/geen-categorie/itho/hru3/

If that type is the same, this might be of help

galadril, 2023-10-01:
I guess it's time for a new one. Probably the eco hru 3 which would then
work with your chip.

Op za 30 sep. 2023 11:10 schreef Arjen Hiemstra ***@***.***>:

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

galadril, 2023-10-02:
@arjenhiemstra  the 'Itho WTW HRU 350 ECO' WtW unit should work out of the box without adjustments right?

arjenhiemstra, 2023-10-02:
Yes that unit works fur sure, out of the box

You weren't successful in reviving your HRU?

galadril, 2023-10-03:
nope the chip seems fried :(

Closed 2023-06-15.

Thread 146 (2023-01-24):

Support for HRU ECO-fan 3 BVF

rvdvoort, 2023-01-24:
I purchased the non-cve addition for the above ITHO unit (approx 12 years old). After connecting with ethernet cable the led on the eth. port is blinking and after a couple of seconds one led is blinking slowly. The SSD shows up as described in the documentation.

 Sometimes I can connect & reach the settings page but only if I am very quick (within 20 - 30 secs). However, after a very short time the ITHO unit start making noises & fan goes up somewhat. At the same time the eth. led starts flashing rapidly with the RX led also flashing slowly. Connection is lost at that time. Resetting the addon doesn't fix it. Only disconnecting the addon and waiting 10 seconds makes the unit stop making noises and fan going down. When connecting the addon everything repeats itsself.

I hooked up the addon to my laptop and it worked without problems. I also was able to connect to my router.
After setting up the unit on my laptop I tried to connect it to the ITHO again. If I was quick I could reach the webpage and was aslo able to load ITHO settings / Status. Controlling the unit with the buttons didn't work. But only after a short-time the same problem repeats. The ITHO is starting to make noises LEDs are flashing etc..

SW version is 24.3 hardware version non-cve 1

Hope some-one can help to fix.

Thx Rob

arjenhiemstra, 2023-01-25:
Have you tried a different cable? Use a high quality cable that is as short as possible would be my advise (Cat6 or better, 15cm rather than lets say 30cm)

rvdvoort, 2023-01-25:
Yes I tried different cables. Same result. I also tried the following:

- Upgrading to to 2.4.4. beta 6 --> same problem
- Downgrading to 2.4.2 --> same problem
- Downgrading to 2.4.1 --> Succes. No direct reset. But if I power-on/off the ITHO with the addon connected resets are starting again. Connecting the addon 20 - 30 secs after power-on is succesful.  In the debug log the following message is shown

2336 I: System boot, last reset reason: RTCWDT_SYS_RESET
2570 I: HW rev: NON-CVE 1, FW ver.: 2.4.1
2249 I: System boot, last reset reason: POWERON_RESET
2421 I: HW rev: NON-CVE 1, FW ver.: 2.4.1
2283 I: System boot, last reset reason: RTCWDT_SYS_RESET
2466 I: HW rev: NON-CVE 1, FW ver.: 2.4.1
2319 I: System boot, last reset reason: POWERON_RESET
2556 I: HW rev: NON-CVE 1, FW ver.: 2.4.1
4975 I: WiFi: connection successful
5193 I: WiFi info:
5502 I: Mode:STA
5635 I: Status:WL_CONNECTED
5778 I: IP:192.168.0.127
5926 I: Setup: Virtual remotes, start ID: DF,EA,E0 - No.: 1
6142 I: Setup: remotes configfile loaded
6339 I: Setup: init of CC1101 RF module successful
6612 I: Setup: remotes configfile loaded
9338 I: MQTT: connection failed, System config: 1
9562 I: Webserver: started
9920 I: mDNS: started
10077 I: Hostname: nrg-itho-eae0
10262 I: Setup: done
2023-01-25 20:24:36 I: I2C init: QueryDevicetype - fw:4 hw:3
2023-01-25 20:24:36 I: I2C init: QueryStatusFormat - items:19
2023-01-25 20:24:36 I: I2C init: QueryStatus
2023-01-25 20:24:37 I: I2C init: Virtual remote join command send

I can reed status & info but there is no way I can get the virtual remote working. Pushing the buttons on webpage  or on virtual remote page do not work. I do get MQTT commands like eg
{"source":"јb interface-vrem��� ��?\b��?nA?qј","command":"high","timestamp":1674680407}

Also using the api is unsuccesful (although page shows ok). Eg commands like the following do not work: http://192.168.0.127/api.html?command=high

Also no reaction in the debug screen on the RF remote. It is an older model pn on box (536-100).

Not sure what is going on but there are some problems.....Hope you can give some insight...

PS: I have another CC1101 RF on a wemos module with some code I found on the internet (running for the last 3-4 years). That one is sending commands that are working. If needed I can share....I might help in finding correct codes for the ITHO unit (if they are different...)

arjenhiemstra, 2023-01-25:
Thank for all the info!!

So it's probably not the cable since fw version 2.4.1 is kinda working...

"{"source":"јb interface-vrem��� ��?\b��?nA?qј","command":"high","timestamp":1674680407}"

The strange characters you see here are the result of a bug that is in fw version 2.4.1 and got fixed later (basically it points to a piece of memory that officially not longer is there). In some cases this could lead to a crash.

Looking at the log, the devicetype is readable. That's good news. The hardware / firmware version is known and supported by the firmware (all fw versions you tried should support it) so that shouldn't be the issue I expect.

If you happen to have a possibility to hook the module up to a computer using the USB interface and run a serial monitor to capture the serial logging created when the module crashes that might greatly help to find the source of the issue.

Not sure about the remote. The code in the firmware supports the newer kind of remotes using the honeywell protocol. The CC1101 RF on a wemos module you mention probably uses a predecessor of the library I'm using for the add-on firmware. I've rewritten part of the original lib to make it possible to use different remote ID's and other things.
The people who originally created the lib had also included (probably without knowing) the older itho protocol. All newer versions in use of this lib dropped support for that. I'm still searching for an older type remote to see if I can reverse engineer the protocol. If you could post a link to the version of software you are using on the wemos, that might be of some help in general.

Not sure of what type the 536-100 is (could you post a picture?) and if your HRU support the older and/or the newer protocol.
If it only supports the older one, that will explain why the virtual remote won't join / work. But the fact that the add-on is able to readout the itho firmware version etc. confirms that (at least a part of) the newer honeywell protocol is present but I'm not sure if the remote part is there as well.

It might not be a bad idea to first try to unpair the virtual remote by sending a leave command, wait a bit and send a join again. If the virtual remote is not paired correctly (or inadvertently joined with a different remote type set) the virtual remote will also not work. For a HRY of that era it's I think best to use the RFT CVE type as that one seems to be around longest.

rvdvoort, 2023-01-26:
Ok, I believe the resets are related to a power issue. With an usb adapter connected to the addon there are no crashes anymore (not sure if this can cause any damage to the ITHO unit).

I have now sw ver 2.4.3 running but cannot get the virtual remote working.  After a reboot of the ITHO unit I tried the leave command on the virtual remote page and would expect ALL remotes including the RF ones to leave. That wasn't the case as the RF remotes kept working. Than I unjoined directly with the ITHO remote (which unjoined all RF remotes) and tried joining again. The RF remotes joined but I don't know if the virtual ones joined (I increased the number virtual remotes to 2). Below is the log.

2249 I: System boot, last reset reason: RTCWDT_SYS_RESET
2360 I: HW rev: NON-CVE 1, FW ver.: 2.4.3
2292 I: System boot, last reset reason: POWERON_RESET
2447 I: HW rev: NON-CVE 1, FW ver.: 2.4.3
8611 I: WiFi: connection successful
8722 I: WiFi info:
8862 I: SSID:ASUS | BSSID[E4:F4:C6:1A:04:4B]
9034 I: RSSI:-49dBm
9230 I: Mode:STA
9527 I: Status:WL_CONNECTED
9657 I: IP:192.168.0.127
9827 I: Setup: Virtual remotes, start ID: DF,EA,E0 - No.: 2
10103 I: Setup: remotes configfile loaded
10334 I: Setup: init of CC1101 RF module successful
10742 I: MQTT: connected, System config: 1
11135 I: Setup: remotes configfile loaded
11275 I: Webserver: started
11401 I: mDNS: started
11530 I: Hostname: nrg-itho-eae0
11670 I: Setup: done
15230 I: I2C init: QueryDevicetype - fw:4 hw:3
15569 I: I2C init: QueryStatusFormat - items:19
15924 I: I2C init: QueryStatus
16115 I: I2C init: Virtual remote join command send

Not sure what to do to get the virtual remote working......Is there a way see if the virtual remote has joined at all? As the leaving command on the webpage doesn't seem to work  maybe the joining command also doesn't work.

The other WEMOS based remote does work and also shows up in the debug  RF menu. The setting to high shows eg the following

26-1-2023 20:46:21: _W 159 --,--,-- --,--,-- 0A,57,51 22F1 3:00,04,04 (cmd:high)
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
arjenhiemstra, 2023-01-28:
Thanks for the link to the wemos firmware, this indeed uses the earlier version of the CC1101 lib for itho.
Looking at the code, this lib actually sends two commands; the old itho protocol and the newer honeywell protocol.
In the source code the old style commands can be found at: "rft message 1 commands"
The makers of the lib (and later editors like me) weren't are of the two protocol parts so the old one was removed.

Both are in the lib, so that is why you see the honeywell part on RF debug page.

> I loaded Beta 6 and with the I2C sniffer I does seem to sent a command (with 0A,57,51 being the remote ID). I pressed the same "high" command twice and below is the outcome

What will be interesting now to see is wether a I2C message will be placed on the I2C bus if you press a button on your physical remote.

> 28-1-2023 08:56:14: [82,60,C1,01,01,11,00,12,C1,23,16,0A,57,51,2D,22,F1,03,00,04,04,F1,00,

This is a sign that the add-on firmware sends a command on the I2C bus, so that is working, but you itho firmware needs an older style command it seems. I'm actually not even sure if the older style command can be send through the i2c bus. That could mean that the only way you can control the HRU is through RF.

> Maybe this version of ITHO doesn't support remote commands via I2C. If that is true than the only option I see is not using I2C for remote commands but the addon's CC1101 . This obviously requires a SW change on the addon with an option to choose between I2C or RF for "virtual" remote control.

True, the code from the wemos lib needs to be changes (it is now basically a copy of a raw RF stream that is not easy to adapt to different remote ID's). This what I did for the newer itho remotes but weren't able to do for the older itho remotes. Maybe the code from the wemos lib is enough to reverse engineer further, maybe I need a real remote to be able to do so.

> PS the addon now runs for more than a day with it own (external) power supply.....so I guess this should be ok?

Yes, I think that is fine. Maybe your model doesn't deliver enough juice through it's RJ45 connecter to power a wifi add-on. The itho service tool is a simple serial bridge that requires maybe a few mAmps instead of the 200-400mA the add-on requres.

arjenhiemstra, 2023-01-28:
Oh and btw;

> Probably need to buy another newer remote.

I think that won't make a difference. I suspect the newer remotes only send the newer signal (in that case I won't work with your HRU) or both the old and new signals. In that case it is just as good as your current remote.

rvdvoort, 2023-01-28:
Just checked, there is no actvitity on the I2C bus when pressing the buttons of the physical remote or the Wemos remote.

So if the Wemos library is sending old & new style commands than the addon probably picks-up the new style (in the debug window) but  the ITHO reacts on the old style command.

So the virtual remote might work if we would be able to understand and could send the old style commands via I2C. However it might also not work as we don't know if Remote commands are accepted via the I2C bus.

Not sure if you are planning to investigate this further but if you do I am willing to test whatever you come with.

Thanks already for your support....can at least read all the status info now and I can still use the Wemos Remote for my home automation.....

Closed 2023-04-06.

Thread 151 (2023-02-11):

Every first command through remote causes OWDT_Reset, after add-on reset, remote works

GelsemaP, 2023-02-11:
**Describe the bug**
I'm running beta 2.4.4-beta6 and have my remotes paired with the add-pm. When I want to control the fan (CVE S ECO SE) from the remote I notice that nothing happens with the fan. In the syslog I notice a OWDT_Reset. After the reset has happened the remote functions, one press and it works.
In Home Assistant nothing shows, everything remains working.

**To Reproduce**
Steps to reproduce the behaviour:
1. On a remote that is paired with the add-on press Timer (any button will do the same)
2. Wait a couple of minutes
3. Press again on a remote that is paired with the add-on any button
4. See error

**Expected behaviour**
I expect that when I press any button on the rf remote that the fan responds.

**Screenshots**
If applicable, add screenshots to help explain your problem.

**Device information**
- Firmware version 2.4.4-beta6
- Hardware revision (e.g. non-cve 1.1) 2
- Type/model number Itho (on sticker outside the box): cve-s eco se
- CC1101 RF module enabled [ yes, no ]: yes
- In case of wifi issues, wifi access point make and model:

**Debug logging**
Please provide debug logging from the debug page if possible:
2023-02-11 14:37:27 I: I2C init: Safe guard enabled
2023-02-11 14:37:26 I: I2C init: QueryStatus
2023-02-11 14:37:26 I: I2C init: QueryStatusFormat - items:12
2023-02-11 14:37:26 I: I2C init: QueryDevicetype - fw:27 hw:27
2023-02-11 14:35:19 I: Hostname: nrg-itho-741c
2023-02-11 14:35:19 I: mDNS: started
2023-02-11 14:35:19 I: Webserver: started
2023-02-11 14:35:18 I: MQTT: connected, System config: 1
2023-02-11 14:35:18 I: Setup: init of CC1101 RF module successful
2023-02-11 14:35:17 I: WiFi: connection successful
2023-02-11 14:35:12 E: Unable to set wifi disconnect
2023-02-11 14:35:11 I: I2C sniffer capable hardware: yes
2023-02-11 14:35:10 I: HW rev: 2, FW ver.: 2.4.4-beta6
2023-02-11 14:35:10 I: System boot, last reset reason: OWDT_RESET
2023-02-11 14:35:52 I: Hostname: nrg-itho-741c
2023-02-11 14:35:52 I: mDNS: started
2023-02-11 14:35:52 I: Webserver: started
2023-02-11 14:35:52 I: MQTT: connected, System config: 1
2023-02-11 14:35:52 I: Setup: init of CC1101 RF module successful
2023-02-11 14:35:51 I: WiFi: connection successful
2023-02-11 14:35:43 E: Unable to set wifi disconnect
2023-02-11 14:35:42 I: I2C sniffer capable hardware: yes
2023-02-11 14:35:42 I: HW rev: 2, FW ver.: 2.4.4-beta6
2023-02-11 14:35:41 I: System boot, last reset reason: OWDT_RESET
2023-02-11 14:34:46 I: I2C init: Safe guard enabled
2023-02-11 14:34:46 I: I2C init: QueryStatus
2023-02-11 14:34:46 I: I2C init: QueryStatusFormat - items:12
2023-02-11 14:34:46 I: I2C init: QueryDevicetype - fw:27 hw:27
2023-02-11 14:34:45 I: Hostname: nrg-itho-741c
2023-02-11 14:34:45 I: mDNS: started
2023-02-11 14:34:44 I: Webserver: started
2023-02-11 14:34:44 I: MQTT: connected, System config: 1
2023-02-11 14:34:44 I: Setup: init of CC1101 RF module successful
2023-02-11 14:36:20 I: WiFi: connection successful
2023-02-11 14:36:08 E: Unable to set wifi disconnect
2023-02-11 14:36:07 I: I2C sniffer capable hardware: yes
2023-02-11 14:36:06 I: HW rev: 2, FW ver.: 2.4.4-beta6
2023-02-11 14:36:06 I: System boot, last reset reason: OWDT_RESET
2023-02-11 14:37:03 I: Hostname: nrg-itho-741c
2023-02-11 14:37:03 I: mDNS: started
2023-02-11 14:37:03 I: Webserver: started
2023-02-11 14:37:03 I: MQTT: connected, System config: 1
2023-02-11 14:37:03 I: Setup: init of CC1101 RF module successful
2023-02-11 14:37:02 I: WiFi: connection successful
2023-02-11 14:36:54 E: Unable to set wifi disconnect
2023-02-11 14:36:53 I: I2C sniffer capable hardware: yes
2023-02-11 14:36:53 I: HW rev: 2, FW ver.: 2.4.4-beta6
2023-02-11 14:36:53 I: System boot, last reset reason: OWDT_RESET

Last command on rf:  lastcmd:0, lastcmdmsg:IthoUnknown

GelsemaP, 2023-02-12:
It’s easy to reproduce this. Just hit the timer button on a remote paired with the add-on. It crashes width the owdt reset. Immediately after reset the timer button works. However if you push another button afterwards the add-on resets again.

sanderkob, 2023-02-12:
Confirmed. It seems that something in the add-on happens, sometime after the reset. This makes that a CC1101 message to the add-on causes a watch-dog reset. There are no clues in the debug log or syslog.

GelsemaP, 2023-02-12:
When the remote is set to monitor only no issues occur. Tonight I will create some automagic that will monitor the lastcmd and manage it from ha. As a workaround.

GelsemaP, 2023-02-13:
Updated to latest beta (7) and issue does not appear anymore. I can use the remote again without any owdt resets. Thanks. Confirmed this can be closed.

Closed 2023-02-13.

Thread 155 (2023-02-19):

Co2 level output missing

mvaneijken, 2023-02-19:
**Describe the bug**
In version 2.3.5 there was a MQTT/API output that shows the current co2 level in ppm. I updated straight to v2.5.0 and in that release this sensor is missing. The sensor seems to be working, because "Highest CO2 concentration (ppm)" provides a value.

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

API request /api.html?get=ithostatus does not show this information also:

`{"temp":23.5,"hum":48.1,"ppmw":8791,"Ventilation setpoint (%)":-1,"Fan setpoint (rpm)":1182,"Fan speed (rpm)":1182,"Error":0,"Selection":7,"Startup counter":323,"Total operation (hours)":23397,"Absence (min)":0,"Highest CO2 concentration (ppm)":806,"Highest RH concentration (%)":49,"RelativeHumidity":"not available","Temperature":"not available"}`

**To Reproduce**
Steps to reproduce the behaviour:
1. Open http://<itho>/api.html?get=ithostatus, co2_le el_ppm missing.

**Expected behaviour**
That the value that was provided before as nrg_itho_6804_co2level_ppm is available.

**Device information**
- Firmware version: v2.5.0
- Hardware revision: 2 (modified to 2.5)
- Type/model number Itho (on sticker outside the box): Itho Daalderop CVE-S CO2 Optima Inside
- CC1101 RF module enabled: No
- In case of wifi issues, wifi access point make and model: N/A

**Debug logging**
Please provide debug logging from the debug page if possible:
`2023-02-18 15:19:17 W: I2C Safe guard disabled due to enabled i2c sniffer
      1368 I: System boot, last reset reason: TG0WDT_SYS_RESET
      1633 I: HW rev: 2, FW ver.: 2.5.0
      1902 I: I2C sniffer capable hardware: yes
      4961 E: Unable to set wifi disconnect
     10550 I: WiFi: connection successful
     12810 I: MQTT: connected, System config: 1
     12998 I: Webserver: started
     13209 I: mDNS: started
     13427 I: Hostname: nrg-itho-6804
     15338 I: I2C init: QueryDevicetype - fw:27 hw:27
     15647 I: I2C init: QueryStatusFormat - items:12
     16076 I: I2C init: QueryStatus
     16566 I: I2C init: Safe guard enabled
     17175 I: I2C init: i2c sniffer enabled
     17422 W: I2C Safe guard disabled due to enabled i2c sniffer
`

arjenhiemstra, 2023-02-19:
>I2C Safe guard disabled due to enabled i2c sniffer

Watch out for this one, the i2c safe guard function is disabled. If your i2c bus gets stuck, disable the sniffer

One to the issue. In 2.5.0 some i2c functions are disabled by default. Maybe you have to enable some of them to get back the co2 reading?

mvaneijken, 2023-02-19:
Thanks for the quick response! Based on your direction I've enabled the setting "Ventilation status (31DA)" and from that on the co2 level measurement came back.

Ps. The IC2 sniffer is disabled now 😅.

Closed 2023-02-19.

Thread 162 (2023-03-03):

i2c bus stuck - please power cycle the itho unit - Firmware 2.5.2

semmtex, 2023-03-03:
**Describe the bug**
After a couple of days the i2c bus on my WPU 5G will get stuck.
I use the MQTT server to get the stats into Home Assistant, nothing else so far...

Last I2C commands:
origin			start		duration	error				final
QUERY_STATUS	237459380	5515	I2C_ERROR_SCL_LOW	I2C_NOK
QUERY_STATUS	237399374	2		I2C_OK
QUERY_STATUS	237339365	2		I2C_OK
QUERY_STATUS	237279341	2		I2C_OK
QUERY_STATUS	237219339	2		I2C_OK
QUERY_STATUS	237159316	2		I2C_OK
QUERY_STATUS	237099304	2		I2C_OK
QUERY_STATUS	237039299	2		I2C_OK
QUERY_STATUS	236979275	2		I2C_OK
QUERY_STATUS	236919274	2		I2C_OK
QUERY_STATUS	236859260	2		I2C_OK
QUERY_STATUS	236799250	2		I2C_OK
QUERY_STATUS	236739226	2		I2C_OK
QUERY_STATUS	236679216	2		I2C_OK
QUERY_STATUS	236619216	2		I2C_OK

**To Reproduce**
Nothing. Just wait a few days.
Resetting using the TEMP/HUM Sensor says connecting.... connected .... stuck...

**Expected behaviour**
Do not get stuck.

**Device information**
- Firmware version 2.5.2.
- Hardware revision NON-CVE 1
- Type/model number Itho WPUG 5G
- No CC1101 RF module enabled
- CVE fan control (PWM2I2C)   OFF
- Ventilation status (31DA)   OFF
- Fan system status (31D9))   OFF
- System status (2401) ON
- i2c safeguard OFF
- i2c debug ON
- i2c sniffer OFF

**Debug logging**
[logfile0.current.log](https://github.com/arjenhiemstra/ithowifi/files/10885450/logfile0.current.log)

arjenhiemstra, 2023-03-03:
You have i2c debug set to ON

What you describe is designed behaviour, also see the description right above the setting:
"This option enables an extra menu where more I2C options and logging is available. Enabling the I2C debug menu **will also halt I2C bus activity** in case of errors to be able to save logging!"

Are you actively debugging the I2C bus?  If not, just switch this feature off. Once in a while an error will always occur on the I2C bus, that is almost nature to how the protocol was designed. Normally this resolves itself.

semmtex, 2023-03-03:
Ah, good to know. I didn't know that it would behave like that. I thought it would simply give me the ability to debug any errors that might happen. I will try and see if this resolves the problem. Thanks...

arjenhiemstra, 2023-03-03:
I'll close the issue for now, if problems keep popping up, please reopen this issue

Closed 2023-03-03.

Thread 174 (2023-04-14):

Can't overrule setting with add-on

0crap, 2023-04-14:
**Describe the bug**
From the `System settings` page I read the following:
"A virtual remote can be used to force the itho unit in medium mode before sending a command from the add-on. This way the add-on can overrule the current speed settings of the itho (ie. due to active input from a built in humidity sensor or another remote)"

When I use the physical remote and set it to Low or High I can't overrule the setting with the add-on.

The physical remote is un-learned from the Itho box and added to the Add-on.
The System setting `Force medium/auto mode` is set to `on`

**To Reproduce**
Steps to reproduce the behaviour:
1. Click Low or High on Physical remote
2. Go to WiFi controller webpage and use slider or buttons to change speed
3. Go to Domoticz and use Fan slider to change speed
4. nothing happens

**Expected behaviour**
Be able to change speed when physical remote is set to Low or High

**Screenshots**
not applicable

**Device information**
- Firmware version: v2.5.6
- Hardware revision: Itho CVE WiFi add-on v2
- Type/model number: Itho CVE-S ECO SP (white lid)
- CC1101 RF module enabled: yes
- In case of wifi issues, wifi access point make and model: -

**Debug logging**
Click for logfile [logfile1.current.log](https://pastebin.com/raw/KMb00S8q)

**Desktop (please complete the following information):**
 - OS: Windows 11 Pro
 - Browser, chrome
 - Version, 112.0.5615.86

**Smartphone (please complete the following information):**
 - Device: Samsung
 - OS: Android
 - Browser Stock
 - Version ?

0crap, 2023-04-14:
This is what the `Itho status` page shows when using the Physical remote on Low, Mid, High.

Low:
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

Mid:
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

High:
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

0crap, 2023-04-14:
And Debug Level2 pressing Low, Mid, High once on the Physical remote.

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

sanderkob, 2023-04-14:
Please make sure that I2C commands for
Ventilation status and Fan system status are enabled.
These settings are on the System settings page.

Op vr 14 apr. 2023 10:58 schreef 0crap ***@***.***>:

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

0crap, 2023-04-14:
Thx!
Those are off by default.
I changed them to `on` but unfortunately no change in behavior.
Still not able to override when Physical remote is set to Low or High.

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

arjenhiemstra, 2023-04-14:
If you go to the virtual remotes page of the add-on. Are you able to control the fan using the buttons of the first virtual remote?

0crap, 2023-04-14:
No, that is not possible.
There is by default already one Virtual Remote visible on index 0.
I have not done anything to it, assuming it is properly working by default.

arjenhiemstra, 2023-04-14:
Then that first remote is not joined correctly to the itho which is a prerequisite for this:
>The System setting Force medium/auto mode is set to on

To have the desired effect,  the first virtual remote must be joined correctly to your itho.

0crap, 2023-04-14:
@arjenhiemstra One more thing I would like to ask.
Before I had the add-on installed I was able to turn the Itho down, by pressing the Low button on the remote, when it kicked in automagically because of humidity.
With the add-on this is not possible.
Is this as intended?

When the humidity sensor gets dirty it often happens the Itho is running way too long after taking a shower in the bathroom.
We always solved it by pressing the Low button until I have the urge to clean the Itho and its humidity sensor.
Missing out on the Low button is a bit of a downside for us.
I'm using the remote as per wiki: [RFT Remote W (RFT bediening stand 1,2,3,T) (536-0124)](https://github.com/arjenhiemstra/ithowifi/wiki/Remotes#use-cases)

arjenhiemstra, 2023-04-14:
The low command can be send using the add-on in multiple ways, it uses the virtual remote function for this (which works just like a normal remote).

Do you use a home domotica system (like Home Assistant)? Using that you can completely control the behaviour of the itho, it is even possible to tune down the control of the humidity sensor so that the itho will not react by itself but only using the input from your domotica system (based on the sensor readout)
Another option is to have a simple push buttom somewhere that will online send the low command etc.

0crap, 2023-04-14:
Walks upstairs, turns on the hot tap to test some more. :-)
I have Domoticz connected via MQTT to the Add-on.
This gives only a fan slider and a temp/hum sensor.

After the humidity sensor puts the Itho full power I pressed the Low button on the Virtual remote webpage.
That works!
However pressing Low on the physical remote, mounted on the bathroom wall, keeps the Itho full speed. (When humidity still kicks the Itho full beans.)
When pressing the Physical remote Low, Medium, High, I do see the slider on the Add-on webpage and Domoticz follow perfectly.
It's just pressing the physical remote Low button does not slow down the Itho.
Only the webpage Virtual remote Low button does.

It would help indeed if I can send the Virtual button Low from Domoticz.
But that does not help with the wife and kids.
Would be perfect if the physical remote Low always works. (Like it did before the Add-on installation.)

roblomq, 2023-04-15:
When I read this, the main cause is in my opinion that the sensor gets "dirty". What do you mean with that, and how do you solve this?

0crap, 2023-04-15:
> When I read this, the main cause is in my opinion that the sensor gets "dirty". What do you mean with that, and how do you solve this?

Yep, just normal dust. Vacuum it out and use a paint brush to clean the sensor.

arjenhiemstra, 2023-04-15:
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

There are a few ways to approach this, mine is to control the itho only by 0-100 pwm2i2c protocol (so no (virtual) remotes commands at all). As said, logic of the humidity (and in my case CO2 sensor) is done in the home domotica software space.

The other option is to control the itho using (virtual remote) commands, this can be done through the add-on's CC1101 module or having remotes joined to the itho, what you prefer. The down side, the speed status is not available in your home domotica software by default. Domoticz is even more limited because of its MQTT topic structure but this can be overcome using the WebAPI.
On the MQTT topic itho/ithostatus or through the WebAPI there is a topic FanInfo (you might need to activate some i2c functions for this to be available) which shows the remote status (ie. low, medium high etc), you can use this in you own integration. There is most of the times also a topic "Fan setpoint (%)" which shows the speed of the fan (independant wether this speed was set using the pwm2i2c protocol (slider on the web page of the add-on) or a (virtual) remote. You can use this to make a status slider in ie. domoticz to show the current speed.

These are just a few examples what you could do, I have seen other examples of creative solutions as well. Just keep in mind which control options you have and what the limitations of those are.
Some extra info can be found here:
https://github.com/arjenhiemstra/ithowifi/wiki/Controlling-the-speed-of-a-fan

0crap, 2023-04-15:
Thx, I appreciate your reply.

For other family members it's most convenient if the physical remote just works as it did before.
Any explanation why it is not possible to make the Low button not override when the Itho is in humid condition?
It seems/feels to me the Add-on is technically capable of doing it...

(Of course I can learn them to the Itho box again if not possible.)

Closed 2023-04-14.

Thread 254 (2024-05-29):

Losing System status (2401) counters after a while

ndewijer, 2024-05-29:
**Describe the bug**

After booting up, All counters work. 2401 and 4210. After a few hours, only the 4210 counters remain.

Working situation at 29-05-2024 14:35

This is from the MQTT server:

```{"Outside temp (°C)":20.66,"Boiler temp down (°C)":59.45,"Boiler temp up (°C)":58.92,"Evaporator temp (°C)":16.58,"Suction gas temp (°C)":28.6,"Compressed gas temp (°C)":52.04,"Liquid temp (°C)":42.5,"Temp to source (°C)":15.89,"Temp from source (°C)":17.84,"CV supply temp (°C)":25.16,"CV return temp (°C)":30.5,"CV pressure (Bar)":2.17,"Compressor current (A)":0,"Current e-element (A)":0,"Pressure switch":0,"Tariff":0,"Condensation protection":0,"Spare input":0,"Correction measurement delta source temperature (K)":-0.57,"Flow sensor (lt_hr)":0,"Phase detection":0,"Cv pump (%)":0,"Well pump (%)":0,"Boiler pump (%)":0,"Free cooling valve (%)":100,"CV_DHW or cooling temp valve (%)":0,"Compressor":0,"Element":0,"Trickle heating":0,"Error":1,"Free cooling":1,"Expansion valve (pls)":0,"Room temp (°C)":20.08,"Requested room temp (°C)":20,"Heat demand thermost. (%)":0,"Status":4,"Sub_status":255,"Blockage":0,"Calculated evaporation temp CV (°C)":16.08,"Calculated CV condensation temp (°C)":45.18,"Calculated evaporation temp DHW (°C)":16.08,"Calculated condensation temp DHW (°C)":45.18,"Error_found":0,"Error_retry":0,"Task active":0,"Manual operation":0,"Compr block (sec)":0,"Elek block (sec)":0,"Cv for _ naddraai (sec)":0,"Source for _ nadraai (sec)":0,"Boiler for _ nadraai (sec)":0,"Delay electr (sec)":0,"Min running time compr (sec)":0,"Drain time (sec)":0,"EV pressure offset (sec)":0,"EV adjust (sec)":0,"Free cooling interval (sec)":180,"Manual control (sec)":0,"Low pressure timer (sec)":0,"Compressor start (sec)":0,"Compr power on delay (sec)":0,"Delay cv start (sec)":0,"Delay cv stop (sec)":0,"Adaptive timer (sec)":0,"Adaptive overheat (K)":5.5,"adaptive fifo index":8,"Fault highest priority":0,"UTC time":1,"Max CV return temp (°C)":10,"Source pump speed free cooling mode":0,"Compressor in Cv mode":0,"Compressor in boiler mode":0,"Element in CV mode":0,"Element in boiler mode":0,"CV mode blocked":0,"Boiler mode blocked":0,"Free cooling mode blocked":0,"Bleeding mode blocked":0,"Electr element blocked":0,"Electr element DHW blocked":0,"Compressor blocked":0,"Off mode active":0,"CV mode active":0,"Boiler mode active":0,"Free cooling mode active":1,"CV pump prime":0,"Well pump prime":0,"Element released":0,"Additional cooling release":0,"CV enabled":0,"Free cooling enabled":1,"Tariff low from thermostat":0,"Venting from thermostat":0,"ECO selected on thermostat":0,"Comfort selected on thermostat":1,"Boiler blocked from thermostat":0,"Boiler boost from thermostat":0,"Heat demand total (%)":0,"E-consumption during stand-by (kWh)":0,"E-consumption during heating (kWh)":0,"E-consumption during DHW (kWh)":0,"E-consumption during cooling (kWh)":0,"Preheat tap water":0,"Element blocked during retry":1,"Pi error sourceflow":0,"Current source valve position (%)":0,"Utc Time offset (min)":0,"Free cooling block time (min)":0,"Cooling temp control valve setpoint (%)":0,"CO valve position (%)":0,"HRU blowout temp (°C)":22.66,"HRU blowout flow (m3_h)":150,"Regeneration active":0,"Latest valid source supply temp. (°C)":12.54,"Source pump flow setpoint (l_h)":1600,"Well pump speed at compr (%)":0,"Source pump speed at free cooling (%)":0,"Well pump speed at airreg (%)":0,"Free cooling mode":2,"Time CO valve start position (sec)":0,"Minimum release time external cooling (sec)":0,"Block time-release external cooling (sec)":0,"External heating release time (sec)":0,"Blocking time trickle low after power-up (sec.)":0,"Blocking time trickle low after CV operation (sec)":0,"Block time pre-heating tap water (sec)":0,"Slow start well pump (sec)":0,"Source return temperature too low (sec.)":0,"Source flow control period (sec)":0,"Stabilisation waiting time-free cooling (sec.)":0,"Minimum time for preheating potable water (sec)":0,"Maximum time for preheating potable water (sec)":0,"Electrical element release (min)":0}```

Syslog since turning on:

```
  18442 I: I2C init: QueryStatus
     18256 I: Hostname: nrg-itho-9e4c
     18078 I: mDNS: started
     17664 I: I2C init: QueryStatusFormat - items:134
     17410 I: Webserver: started
     17144 I: MQTT: connected, System config: 1
     16917 I: I2C init: QueryDevicetype - mfr:0x00 type:0x0D fw:0x25 hw:0x4E
     14795 I: Timezone: Europe/Amsterdam, specifier CET-1CEST,M3.5.0,M10.5.0/3
     14628 I: WiFi: connection successful
      8710 I: wifi AP mode started
      6963 E: Unable to set wifi disconnect
      4524 I: I2C sniffer capable hardware: yes
      4322 I: HW rev: NON-CVE 1, FW ver.: 2.8.0
      3804 I: Device UUID: 993c8f2b-1d34-4771-82fe-35acee3d2f54
      3492 I: System boot, last reset reason: POWERON_RESET
```

counters
``` 80 82 C2 10 01 35 1A 11 49 12 B2 01 9A 05 B8 00 00 04 80 01 AF 0D 4C 27 1C 0B 33 0B 42 06 51 08 95 00 00 06 1A 02 C2 01 14 00 11 00 00 00 00 00 00 00 00 00 00 00 00 02 C2 02 40 07 ```

Connection:
Config version: 005
Itho I2C connection status: connected
File system: 32768 bytes used / 131072 bytes total

Then, at 29-05-2024 21:12

MQTT
```
{"CH pump on (h)":4432,"Source pump on (h)":4792,"DHW pump on (h)":410,"Compressor on (h)":1464,"Electrical element on (h)":0,"CH mode (h)":1152,"DHW mode (h)":431,"Free cooling mode (h)":3410,"Total runtime (h)":10018,"CH pump starts":2868,"Source pump starts":2883,"DHW pump starts":1617,"Compressor starts":2197,"Electrical element starts":0,"CH mode starts":1562,"DHW mode starts":706,"Free cooling starts":276,"System starts":17,"DHW element on (h)":0,"DHW element starts":0,"E-consumption stand-by (kWh)":0,"E-consumption heating (kWh)":0,"E-consumption DHW (kWh)":0,"E-consumption cooling (kWh)":0,"Energy out of source (MWh)":706,"Energy returned to source (MWh)":577}
```

Syslogs since last messages:
```
2024-05-29 16:48:34 I: I2C init: QueryStatus
2024-05-29 16:48:34 I: I2C init: QueryStatusFormat - items:0
2024-05-29 16:48:34 I: I2C init: QueryDevicetype - mfr:0x00 type:0x0D fw:0x25 hw:0x4E
2024-05-29 16:48:34 I: Hostname: nrg-itho-9e4c
2024-05-29 16:48:33 I: mDNS: started
2024-05-29 16:48:33 I: Webserver: started
2024-05-29 16:48:33 I: MQTT: connected, System config: 1
2024-05-29 16:48:31 I: Timezone: Europe/Amsterdam, specifier CET-1CEST,M3.5.0,M10.5.0/3
2024-05-29 16:44:49 I: WiFi: connection successful
2024-05-29 16:44:43 I: wifi AP mode started
2024-05-29 16:44:41 E: Unable to set wifi disconnect
2024-05-29 16:44:38 I: I2C sniffer capable hardware: yes
2024-05-29 16:44:38 I: HW rev: NON-CVE 1, FW ver.: 2.8.0
2024-05-29 16:44:38 I: Device UUID: 993c8f2b-1d34-4771-82fe-35acee3d2f54
2024-05-29 16:44:37 I: System boot, last reset reason: OWDT_RESET
2024-05-29 16:44:33 E: Unable to set wifi disconnect
2024-05-29 16:44:30 I: I2C sniffer capable hardware: yes
2024-05-29 16:44:30 I: HW rev: NON-CVE 1, FW ver.: 2.8.0
2024-05-29 16:44:30 I: Device UUID: 993c8f2b-1d34-4771-82fe-35acee3d2f54
2024-05-29 16:44:30 I: System boot, last reset reason: OWDT_RESET
2024-05-29 16:44:25 E: Unable to set wifi disconnect
2024-05-29 16:44:23 I: I2C sniffer capable hardware: yes
2024-05-29 16:44:22 I: HW rev: NON-CVE 1, FW ver.: 2.8.0
2024-05-29 16:44:22 I: Device UUID: 993c8f2b-1d34-4771-82fe-35acee3d2f54
2024-05-29 16:44:22 I: System boot, last reset reason: SDIO_RESET
2024-05-29 16:47:34 W: Warning: Task MQTT timed out!
```
counters
```
80 82 C2 10 01 35 1A 11 50 12 B8 01 9A 05 B8 00 00 04 80 01 AF 0D 52 27 23 0B 34 0B 43 06 51 08 95 00 00 06 1A 02 C2 01 14 00 11 00 00 00 00 00 00 00 00 00 00 00 00 02 C2 02 41 EA
```

Connection:
Config version: 005
Itho I2C connection status: connected
File system: 32768 bytes used / 131072 bytes total

**To Reproduce**
Steps to reproduce the behaviour:
unknown

**Expected behaviour**
All counts stay active.

**Screenshots**
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
Import of the MQTT into homeassistant. You can see the counters working until 16:45.

**Device information**
- Firmware version 2.8.0
- Hardware revision non-cve 1.
- Type/model number Itho (on sticker outside the box) wpu 5g
hw version: 78
fw version: 37
- CC1101 RF module enabled no
- In case of wifi issues, wifi access point make and model:

**Debug logging**
Please provide debug logging from the debug page if possible:

See above in description.

arjenhiemstra, 2024-05-29:
What is the output of "Query Status" on the debug page? (FYI; Query Status == 2401 command)

ndewijer, 2024-05-29:
Query status
```Result: 80 82 A4 01 01 D5 05 E9 16 5D 16 79 07 06 08 02 09 F8 09 3A 06 7C 05 44 07 08 07 46 01 21 00 00 00 00 00 00 00 00 FF C7 00 F5 00 64 06 00 64 64 00 00 00 01 01 00 00 07 E5 07 D0 00 04 FF 00 06 D4 09 B9 06 D4 09 B9 00 00 00 00 00 00 00 00 00 00 00 00 00 00 00 00 00 00 00 00 00 00 00 00 00 00 00 00 00 00 00 00 00 00 00 00 00 00 00 00 00 02 26 08 00 66 57 AF 45 0A 06 00 00 00 00 00 00 00 00 00 00 00 00 00 00 01 00 00 00 00 00 01 00 00 00 01 00 00 00 00 00 00 00 00 00 00 00 00 00 00 00 00 00 00 00 00 01 00 00 00 00 00 00 00 64 00 06 B1 00 96 00 06 7C 06 40 00 06 00 01 00 00 00 00 00 00 00 00 00 00 00 00 00 00 01 00 00 00 00 00 00 00 00 00 00 00 00 00 00 8C```

and Query 2410
```
Result: 80 82 A4 10 01 13 00 00 00 00 00 00 00 00 FF FF FF FF 00 00 00 01 10 00 F0 39
Current: 0
Minimum value: 0
Maximum value: 65535
```

ndewijer, 2024-05-30:
Just to clarify, the 2401 counters don't show up on the "Itho Status" page ether. MQTT matches what's on the status page.

Closed 2024-08-06.

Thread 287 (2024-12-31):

2.9.0b10 - MQTT rfremotecmd call no longer work

jasperslits, 2024-12-31:
**Describe the bug**
In 2.8.0 and prior versions this worked fine but in 2.9.0b10 nothing happens when rfremotecmd is used. In logs below ithohru/deviceinfo and ithohru/remotesinfo trimmed for brevity. I have the non-CVE add-on with CC1101.

The problem is that the add-on doesn't seem to relay the commands to the Itho unit as the mode does not change from auto to autonight.

There are no errors in syslog and reverting back to 2.8.0 restores original behaviour.

```
2024-12-31T13:15:08+0100 ithohru/cmd { rfremotecmd: 'autonight'}
2024-12-31T13:15:55+0100 ithohru/lastcmd {"source":"MQTT API","command":"rfremotecmd:autonight, idx:0","timestamp":1735647308}
2024-12-31T13:15:55+0100 ithohru/state 120
2024-12-31T13:16:38+0100 ithohru/ithostatus {"Requested fanspeed (%)":-0.99,"Balance (%)":99.8,"Supply fan (RPM)":758,"Supply fan actual (RPM)":758,"Exhaust fan (RPM)":760,"Exhaust fan actual (RPM)":765,"Supply temp (°C)":16.92,"Exhaust temp (°C)":7.23,"Status":0,"Room temp (°C)":16.92,"Outdoor temp (°C)":7.23,"Valve position":0,"Bypass position":0,"Summercounter":0,"Summerday (K_min)":0,"Frost timer":0,"Boiler timer":177,"Frost block":120,"Current position":0,"VKKswitch":0,"GHEswitch":0,"Airfilter counter":2282,"Global fault code":0,"Actual Mode":24,"Pir fan speed level":-1,"Highest received CO2 value (Ppm)":562,"Highest received RH value (%RH)":239,"Air Quality (%)":100,"Remaining override timer (Sec)":0,"Fallback speed timer (Sec)":0,"Label out of bound error":0}
2024-12-31T13:16:38+0100 ithohru/lastcmd {"source":"MQTT API","command":"rfremotecmd:autonight, idx:0","timestamp":1735647308}
```

Syslog shows no problems

```
2024-12-30 11:57:35 I: I2C init: QueryStatus
2024-12-30 11:57:35 I: I2C init: QueryStatusFormat - items:33
2024-12-30 11:57:35 I: Hostname: hru
2024-12-30 11:57:34 I: mDNS: started
2024-12-30 11:57:34 I: Webserver: started
2024-12-30 11:57:34 I: MQTT: connected, System config: 1
2024-12-30 11:57:34 I: I2C init: QueryDevicetype - mfr:0x00 type:0x2B fw:0x04 hw:0x0A
2024-12-30 11:57:34 I: Setup: CC1101 RF module found, chip version: 0x14
2024-12-30 11:57:31 I: Timezone: Europe/Amsterdam, specifier CET-1CEST,M3.5.0,M10.5.0/3
2024-12-30 11:57:31 I: WiFi: connection successful
2024-12-30 11:57:26 I: wifi AP mode started
2024-12-30 11:57:25 E: Unable to set wifi disconnect
2024-12-30 11:57:22 I: I2C sniffer capable hardware: yes
2024-12-30 11:57:22 I: HW rev: NON-CVE 1, FW ver.: 2.9.0-beta10
2024-12-30 11:57:22 I: Device UUID: df15c2bb-d2f7-4944-8e41-21eb26592412
2024-12-30 11:57:21 I: System boot, last reset reason: SW_RESET
2024-12-30 11:57:02 I: Firmware update: nrgitho-v2.9.0-beta10.bin
2024-12-14 22:51:43 I: I2C init: QueryStatus
2024-12-14 22:51:43 I: Hostname: hru
2024-12-14 22:51:42 I: mDNS: started
2024-12-14 22:51:42 I: Webserver: started
2024-12-14 22:51:42 I: MQTT: connected, System config: 1
```

arjenhiemstra, 2024-12-31:
Thanks for reporting this but I cannot reproduce it. Tested with beta10 and 2.8.0 result in the same behaviour. I can also not find any relevant code changes in the MQTT callback function between these versions.

The only thing I notice in your log and what might have changed due to the lib ArduinoJSON being updated in the mean time; JSON parsing might be more strict. If you actually feed this command to the MQTT API:
`{ rfremotecmd: 'autonight'}`

That is not a valid JSON

Please try this instead:
`{"rfremotecmd":"autonight"}`

jasperslits, 2024-12-31:
Does not make a difference: nothing happens. But upon further testing there's nothing happening when using the buttons in the add-on. Not on the virtual remote nor under RF devices.

Could pairing be 'broken' somehow?

arjenhiemstra, 2024-12-31:
What remote type have you configured?

jasperslits, 2024-12-31:
RFT CO2 as vremote and same under RF devices.

arjenhiemstra, 2024-12-31:
OK, thanks! Thats useful info. I'll test with the CO2 remote.
Have you configured bi-directional?

jasperslits, 2024-12-31:
The RF devices are in monitoring only. And they have been like that since day 1.

Closed 2025-03-08.

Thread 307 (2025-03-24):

Can anyone with a HRU 300 WTW validate these read-outs?

mkleijn, 2025-03-24:
Hi, I successfully connected the non-CVE module to my HRU 300, partly because I want to monitor the WTW performance in HA but also because I wanted to get more information about the error I received on the display. I suspected one or more temp sensors where malfunctioning and the readouts seem to prove that:

| Label                                                 | Value    |
|-------------------------------------------------------|----------|
| Error number                                          | 53       |
| Status                                                | 0        |
| Measured outside temperature (°C)                     | -327.68  |
| Measured temperature of mixed outside air (°C)        | -327.68  |
| The flow of the inflated air (M3/h)                   | 0        |
| Inlet temperature (°C)                                | 25.2     |
| Temperature of the extracted air (°C)                 | 25.17    |
| Temperature of the blown out air of the house (°C)    | 21.63    |
| The flow of the blown air (m3/h)                      | 0        |
| Relative fanspeed (%)                                 | 99.5     |
| Absolute speed of the fan (%)                         | 99.5     |
| Hysteresis use in control mode (K)                    | 0        |
| Timer for how long the house is cooled (hour)         | 0        |
| Timer for how long the house is heated (hour)         | 16       |
| The mass flow of the air entering the house (kg/h)    | 0        |
| The mass flow of the air leaving the house (kg/h)     | 0        |
| Percentage that the bypass valve is open (%)          | 100      |
| The desired inlet temperature (°C)                    | 20       |
| Hysteresis of the frost (K)                           | 0.5      |
| Number of steps the frost valve is open (steps)       | 0        |
| Number of hours of too cold air (hour)                | 6        |
| Temporary speed reduction (rpm)                      | 0        |
| Sample timer in frost mode (min)                      | 0        |
| RPM of the motor (rpm)                                | 2095     |
| Measured waste temperature heated NTC (°C)            | -327.68  |
| Measured blend temperature heated NTC (°C)            | 327.67   |
| Desired capacity (m3/h)                               | 0        |
| Busy doing adjustments (-)                            | 0        |
| Current consumption of fan (mA)                       | 11334    |
| Desired current consumption of fan (mA)               | 0        |
| Highest measured RH (%)                               | 0        |
| Highest measured CO2 (ppm)                            | 0        |

Outside temp, mixed air temp and the waste/blend(?) temp sensors give a invalid values of (-)32K but I know some values are "supposed" to be missing for this model. Of course the error code 53 is a giveaway as well, but I can't seem to find a reference list of these codes on the internet.

Anyway, the whole thing is placed in a not so serviceable location so when I go and try to open the thing up to locate the broken or dirty sensors I prefer to know where to look. Does anyone have a fully functional HRU300 that can share their status readouts for me to compare, or anyone has any info for me that can help me pinpoint the faulty sensors?

mkleijn, 2025-03-24:
Great, thanks. I found that replacement kit (price is ridiculous if you look at the electronics involved, but guess that's how it is with OEM replacement kits). Unfortunately I just left my extended warranty on parts slip by a few months. Sounds like a design fault if the original sensors can't survive the environment they are installed in. Anyway, small hope its just a bad connection or something.

EdwinGH, 2025-03-24:
The properties of my unit:
Itho device type: HRU 250-300
Itho hw version: 6
Itho fw version: 7
Manufacturer: 7

It's current values are as follows: (I think the 25.xx values are sensors replaced with resistors):
Label | Value
-- | --
Error number | 2
Status | 5
Measured outside temperature (°C) | 16.48
Measured temperature of mixed outside air (°C) | 16.11
The flow of the inflated air (M3/h) | 404.5
Inlet temperature (°C) | 20.25
Temperature of the extracted air (°C) | 20.43
Temperature of the blown out air of the house (°C) | 25.12
The flow of the blown air (m3/h) | 307.6
Relative fanspeed (%) | 0.5
Absolute speed of the fan (%) | 4
Hysteresis use in control mode (K) | 0
Timer for how long the house is cooled (hour) | 0
Timer for how long the house is heated (hour) | 0
The mass flow of the air entering the house (kg/h) | 491.93
The mass flow of the air leaving the house (kg/h) | 362.66
Percentage that the bypass valve is open (%) | 74.5
The desired inlet temperature (°C) | 22
Hysteresis of the frost (K) | 0
Number of steps the frost valve is open (steps) | 1400
Number of hours of too cold air (hour) | 0
Temporary speed reduction (rpm) | 0
Sample timer in frost mode (min) | 0
RPM of the motor (rpm) | 356
Measured waste temperature heated NTC (°C) | 25.27
Measured blend temperature heated NTC (°C) | 25.25
Desired capacity (m3/h) | 0
Busy doing adjustments (-) | 0
Current consumption of fan (mA) | 535
Desired current consumption of fan (mA) | 0
Highest measured RH (%) | 0
Highest measured CO2 (ppm) | 704

<!--EndFragment-->
</body>
</html>

GraceGRD, 2025-03-25:
I no longer have the ithowifi module connected to my HRU and read-out my sensors wirelessly.

Recently I got my sensors replaced as well.
* Outside temperature and temperature blown into the home have the same value.
* Indoor temperature seems correct
* Blow out temperature seems fixed around 25 deg (looks like a fixed resistor).

mkleijn, 2025-03-25:
Thanks @EdwinGH and @GraceGRD for your reply! I have the same HW and FW versions as EdwinGH mentioned. When I compare my values against his combined what GraceGRD mentions, it seems like my sensors for outside temp and mixed outside air are toasted. And the ones on the heated NTC, but these are replaced by a resistor anyway apparently.

Also I have no values for the flow of inflated and blown air. Anyone knows how this is measured? I don't believe these sensors are part of the sensor replacement pack, or are they?

Maybe it is not measuring because the whole thing is in an error state.

mkleijn, 2025-04-02:
Just a quick update, managed to open the unit and clean some of the sensors and connectors in the fan part of the unit.
Seems to have done something as the "Measured blend temperature heated NTC (°C)" is now showing a valid value.

Outside, mixed and waste are still reporting as -327.68 so I guess those sensors just died. Time to order that replacement kit. Apparently it is a design mistake, the open sensors are prone to corrosion

GraceGRD, 2025-04-15:
They have a warranty check on their website:
https://www.ithodaalderop.nl/nl-NL/professional/garantiecheck

Standard 2y warranty on parts / labor costs.
If you register your product the parts waranty is extended to 5y.

I had to contact a 3rd party certified installer to get the sensors replaced (Itho no longer does it themselves in our area). This 3rd party installer shipped back the sensors to Itho and got it replaced under waranty. Sadly not the laber cost as my unit was 3y old at the time of service.

Hopefully this info helps.

arjenhiemstra, 2025-04-15:
> > Apparently it is a design mistake, the open sensors are prone to corrosion
>
> So then the manufacturer should pay, no?

Unfortunately, manufacturer warranties are not legally bound.

The only warranties statutory guaranteed are between seller and buyer and in the EU the minimal statutory guaranteed duration of the warranty is 2 years, for consumers.

In The Netherlands there is no fixed maximum duration defined (ie. it can extend for way more than 2 years depending on the expected life-cycle of a product).
Manufacturer warranties are an "extra" service from the manufacturer (this will differ per country based on local legislation).
If you buy a product directly from a manufacturer (ie. you order a product from Itho instead of buying at company abc), the manufacturer is of course also the seller and in that the manufacturer is also bound to the same consumer warranty rules.
All of this does not apply to B2B sales btw.

> Itho asks ridiculous prices for a temp sensor.

Without any doubt!

Closed 2025-06-21.

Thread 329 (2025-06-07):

Support request: remaining time of timer command

retorquere, 2025-06-07:
## Describe the bug

I have RF remotes paired to the addon on a CVE, and the addon configured in home assistant. If a timer1/timer2/timer3 command is sent, would it be possible to expose the time remaining in a way that it can be read in HA?

## To Reproduce

1. Join the remotes on the addon
2. Give a timer command with the remote, the CVE goes to high
3. The time remaining is not available on the HA device

## Device information
- Firmware version  2.8.0
- Hardware revision CVE 2
- CC1101 RF module enabled yes

retorquere, 2025-06-07:
Apologies, I should not have submitted this without complying with the submission template -- will get one when I'm home!

retorquere, 2025-06-07:
[logfile1.current.txt](https://github.com/user-attachments/files/20642190/logfile1.current.txt)
[logfile0.txt](https://github.com/user-attachments/files/20642191/logfile0.txt)

arjenhiemstra, 2025-06-08:
Thanks!
Looking at your model number, you should be able to activate the i2c command "System settings" -> "Ventilation status (31DA)" to on

This will give you a few extra items on the "Itho status" page. One of them is: "RemainingTime (min)" which is the remaining timer time if a timer is active.

btw. if you update to the latest beta13 version, you can expose these status items to HA through auto discovery.

retorquere, 2025-06-08:
Alright, I've turned that on and installed beta 13, I have restarted the addon and HA to be on the safe side, but I'm not seeing any entities on the device (which is what I thought you described as being one of the benefits of the beta). In the DevTools/States tab, I currently see

```
preset_modes: Low, Medium, High, Timer 10min, Timer 20min, Timer 30min
percentage: 8
percentage_step: 1
preset_mode: null
Ventilation level (%): 2
Fan setpoint (rpm): 577
Fan speed (rpm): 583
Error: 0
Selection: 3
Startup counter: 97
Total operation (hours): 113907
friendly_name: Ventilatie
supported_features: 57
```

but I think that this is what I saw before.

retorquere, 2025-06-08:
I do have the itho wifi addon installed. I'm new to HA and there's a lot to process, but before you do more work on my behalf let me just read read the wiki again -- a lot of stuff is starting to click now.

retorquere, 2025-06-08:
OK so I have the entities card installed but when filtering I don't see anything relating to time remaining. I tried to download a new log, and it did download (see attachment), but the addon UI is stuck on

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

[logfile1.current.txt](https://github.com/user-attachments/files/20646759/logfile1.current.txt)

arjenhiemstra, 2025-06-08:
If you go to HA Discovery you should be able to check the items you would like to have in HA

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

In HA the device will be discovered and that should look something like this:

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

arjenhiemstra, 2025-06-08:
https://github.com/user-attachments/assets/5d076eab-e313-4b8b-b998-25490c6a76f5

Here is a small clip of how it should work

retorquere, 2025-06-08:
I set it to 10, saved, and waited one minute, but the "HA Discovery" remained at "I2C command 31da activated but not ready". As soon as I turn that off, the HA Discovery page returns. That is with just `PWM2I2C` and `2401` on, rest off.

Should I try with the release build to see whether that makes a difference?

Minor point, but there's an extra parenthesis in

> Fan system status (31D9))

> If you open the developer console of you browser you might see some relevant error messages related to this.

Nothing at all. When I enable everything, including requests, I see a single call to http://nrg-itho-bc4c.local/curlog when I open the tab, but nothing else, even when I click "download log" (which may mean download just takes whatever is already displayed?). But I've now tried on Firefox, Safari and Edge, and it only happens on Firefox (on the beta FW).

arjenhiemstra, 2025-06-09:
Then I'm afraid your model's firmware version doesn't support the 31DA command unfortunately...

retorquere, 2025-06-09:
Ah well, I'm very happy with the functionality the addon does provide, the timer would just have been the icing on the cake.

I think the addon does expose the commands being sent, is that correct? Then I'll just try to synthesize the time remaining. If not, no problem.

arjenhiemstra, 2025-06-09:
With
`api.html?get=lastcmd`

You can get the last command processed.

If you activate api v2 you get an output like this:

```JSON
{
    "status": "success",
    "data": {
        "timestamp": 1749464119,
        "cmdkey": "get",
        "cmdvalue": "lastcmd",
        "lastcmd": {
            "source": "MQTT API",
            "command": "speed:255",
            "timestamp": 1749462852
        }
    }
}
```

within "lastcmd" there is a timestamp, this was the moment the last command was executed.

retorquere, 2025-06-09:
Excellent!

Closed 2025-08-15.

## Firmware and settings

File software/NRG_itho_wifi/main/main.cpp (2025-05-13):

#include <Arduino.h>
#include "globals.h"
#include "tasks/task_init.h"

#define TASK_MAIN_PRIO 5

// locals
TaskHandle_t xTaskInitHandle = NULL;
StaticTask_t xTaskInitBuffer;
StackType_t xTaskInitStack[STACK_SIZE];

void setup()
{
  // put your setup code here, to run once:

#if defined(ENABLE_SERIAL)
  Serial.begin(115200);
  Serial.flush();
  delay(100);
#endif

  xTaskInitHandle = xTaskCreateStaticPinnedToCore(
      TaskInit,
      "TaskInit",
      STACK_SIZE,
      (void *)1,
      TASK_MAIN_PRIO,
      xTaskInitStack,
      &xTaskInitBuffer,
      CONFIG_ARDUINO_RUNNING_CORE);
}

void loop()
{
  // put your main code here, to run repeatedly:
  yield();
  esp_task_wdt_reset();
}

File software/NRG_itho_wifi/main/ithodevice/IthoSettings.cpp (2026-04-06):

#include "IthoDevice.h"
#include "devices/error_info_labels.h"

ithoSettings *ithoSettingsArray = nullptr;
int32_t *resultPtr2410 = nullptr;
bool i2c_result_updateweb = false;

struct retryItem
{
  int index;
  int retries;
};

std::vector<retryItem> retryList;

int getSettingsLength(const uint8_t deviceGroup, const uint8_t deviceID, const uint8_t version)
{

  const struct ihtoDeviceType *ithoDevicesptr = ithoDevices;
  const struct ihtoDeviceType *ithoDevicesendPtr = ithoDevices + ithoDevicesLength;
  while (ithoDevicesptr < ithoDevicesendPtr)
  {
    if (ithoDevicesptr->DG == deviceGroup && ithoDevicesptr->ID == deviceID)
    {
      if (ithoDevicesptr->settingsMapping == nullptr)
      {
        return -2; // Settings not available for this device
      }
      if (version > (ithoDevicesptr->versionsMapLen - 1))
      {
        return -3; // Version newer than latest version available in the firmware
      }
      if (*(ithoDevicesptr->settingsMapping + version) == nullptr)
      {
        return -4; // Settings not available for this version
      }

      for (int i = 0; i < 999; i++)
      {
        if (static_cast<int>(*(*(ithoDevicesptr->settingsMapping + version) + i)) == 999)
        {
          // end of array
          if (ithoSettingsArray == nullptr)
            ithoSettingsArray = new ithoSettings[i];
          return i;
        }
      }
    }
    ithoDevicesptr++;
  }
  return -1;
}

const char *getSettingLabel(const uint8_t index)
{

  const uint8_t deviceID = currentIthoDeviceID();
  const uint8_t version = currentItho_fwversion();
  const uint8_t deviceGroup = currentIthoDeviceGroup();

  int settingsLen = getSettingsLength(deviceGroup, deviceID, version);

  const struct ihtoDeviceType *settingsPtr = ithoDeviceptr;

  if (settingsPtr == nullptr)
  {
    if (systemConfig.api_normalize == 0)
    {
      return ithoLabelErrors[0].labelFull;
    }
    else
    {
      return ithoLabelErrors[0].labelNormalized;
    }
  }
  else if (settingsLen == -2) // Settings not available for this device
  {
    if (systemConfig.api_normalize == 0)
    {
      return ithoLabelErrors[1].labelFull;
    }
    else
    {
      return ithoLabelErrors[1].labelNormalized;
    }
  }
  else if (settingsLen == -3) // Version newer than latest version available in the firmware
  {
    if (systemConfig.api_normalize == 0)
    {
      return ithoLabelErrors[2].labelFull;
    }
    else
    {
      return ithoLabelErrors[2].labelNormalized;
    }
  }
  else if (settingsLen == -4) // Settings not available for this version
  {
    if (systemConfig.api_normalize == 0)
    {
      return ithoLabelErrors[3].labelFull;
    }
    else
    {
      return ithoLabelErrors[3].labelNormalized;
    }
  }
  else if (!(index < settingsLen)) // out of bound
  {
    if (systemConfig.api_normalize == 0)
    {
      return ithoLabelErrors[4].labelFull;
    }
    else
    {
      return ithoLabelErrors[4].labelNormalized;
    }
  }

  return settingsPtr->settingsDescriptions[static_cast<int>(*(*(settingsPtr->settingsMapping + version) + index))];
}

void getSetting(const uint8_t index, const bool updateState, const bool updateweb, const bool loop)
{

  const uint8_t deviceID = currentIthoDeviceID();
  const uint8_t version = currentItho_fwversion();
  const uint8_t deviceGroup = currentIthoDeviceGroup();

  int settingsLen = getSettingsLength(deviceGroup, deviceID, version);
  if (settingsLen < 0)
  {
    logMessagejson("Settings not available for this device or its firmware version", WEBINTERFACE);
    return;
  }

  // const struct ihtoDeviceType *settingsPtr = ithoDeviceptr;

  JsonDocument doc;
  JsonObject root = doc.to<JsonObject>();

  root["Index"] = index;
  root["Description"] = getSettingLabel(index);

  if (!updateState && !updateweb) // -> first run, just send labels and null values
  {
    root["update"] = false;
    root["loop"] = loop;
    root["Current"] = nullptr;
    root["Minimum"] = nullptr;
    root["Maximum"] = nullptr;
    logMessagejson(root, ITHOSETTINGS);
  }
  else if (updateState && !updateweb) // -> 2nd run update setting values of settings page
  {
    // index2410 = index;
    // i2c_result_updateweb = false;
    resultPtr2410 = nullptr;
    // get2410 = true;
    i2cQueueAddCmd([index]()
                      { resultPtr2410 = sendQuery2410(index, false); });
    i2cQueueAddCmd([index, loop]()
                      { processSettingResult(index, loop); });
  }
  else // -> update setting values from other source (ie. debug page)
  {
    // index2410 = i;
    // i2c_result_updateweb = updateweb;
    resultPtr2410 = nullptr;
    // get2410 = true;
    i2cQueueAddCmd([index, updateweb]()
                      { resultPtr2410 = sendQuery2410(index, updateweb); });
  }
}
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

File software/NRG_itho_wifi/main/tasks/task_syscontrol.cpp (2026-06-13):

#include "tasks/task_syscontrol.h"
#include "../sys_log.h"
#include "generic_functions.h"

#define TASK_SYS_CONTROL_PRIO 6
// globals
uint32_t TaskSysControlHWmark = 0;
bool runscan = false;
bool saveSystemConfigflag = false;
bool saveLogConfigflag = false;
bool saveWifiConfigflag = false;
bool saveHADiscConfigflag = false;
bool resetWifiConfigflag = false;
bool resetSystemConfigflag = false;
bool resetHADiscConfigflag = false;
bool clearQueue = false;
bool shouldReboot = false;
bool restest = false;
bool i2c_safe_guard_log = true;
unsigned long getFWupdateInfo = 0;
struct firmwareinfo firmwareInfo;

// locals
StaticTask_t xTaskSysControlBuffer;
StackType_t xTaskSysControlStack[STACK_SIZE_MEDIUM];
TaskHandle_t xTaskSysControlHandle = NULL;

Ticker scan;

unsigned long lastWIFIReconnectAttempt = 0;
unsigned long wifiLedUpdate = 0;
unsigned long SHT3x_readout = 0;
unsigned long query2401tim = 0;
unsigned long query4210tim = 0;
unsigned long mqttUpdatetim = 0;
unsigned long lastVersionCheck = 0;
unsigned long lastIthoStatusFormatCheck = 0;

void startTaskSysControl()
{
  xTaskSysControlHandle = xTaskCreateStaticPinnedToCore(
      TaskSysControl,
      "TaskSysControl",
      STACK_SIZE_MEDIUM,
      (void *)1,
      TASK_SYS_CONTROL_PRIO,
      xTaskSysControlStack,
      &xTaskSysControlBuffer,
      CONFIG_ARDUINO_RUNNING_CORE);
}

void TaskSysControl(void *pvParameters)
{
  configASSERT((uint32_t)pvParameters == 1UL);
  Ticker TaskTimeout;
  Ticker queueUpdater;

  networkManager.initialize(); // Initialize network clients (sets secure client to skip CA verification)

  delay(2000);
  wifiInit();
  delay(2000);
  syslog.appName(logConfig.logref);
  syslog.deviceHostname(hostName());
  syslog.server(logConfig.logserver, logConfig.logport);
  syslog.defaultPriority(LOG_KERN);

  init_vRemote();

  initSensor();

  startTaskCC1101();

  esp_task_wdt_add(NULL);

  queueUpdater.attach_ms(QUEUE_UPDATE_MS, updateQueue);

  for (;;)
  {
    yield();
    esp_task_wdt_reset();

    TaskTimeout.once_ms(TASK_SYSCONTROL_TIMEOUT_MS, []()
                        { W_LOG("SYS: warning - Task SysControl timed out!"); });

    execSystemControlTasks();

    if (shouldReboot)
    {
      TaskTimeout.detach();
      N_LOG("SYS: reboot requested");
      delay(1000);
      ACTIVE_FS.end();
      esp_restart();
    }

    TaskSysControlHWmark = uxTaskGetStackHighWaterMark(NULL);
    vTaskDelay(25 / portTICK_PERIOD_MS);
  }

  // else delete task
  vTaskDelete(NULL);
}

void execSystemControlTasks()
{
  if (otaUpdateRequested)
  {
    otaUpdateRequested = false;
    if (otaUpdateURL[0] != '\0')
      performOTAUpdateFromURL(otaUpdateURL);
    else
      performOTAUpdate(otaUpdateBeta);
  }

  i2cManager.processQueue();

  if (systemConfig.itho_rf_standalone == 1)
  {
    // RF standalone mode: skip I2C, mark init done
    if (!i2c_init_functions_done)
    {
      i2c_init_functions_done = true;
      ithoInitResult = 2; // 2 = RF standalone (not I2C), avoids low-power TX path
      I_LOG("SYS: RF standalone mode - I2C disabled");
      sendHomeAssistantDiscovery = true;
    }

    // In standalone mode the Itho only reaches us over RF, so the I2C
    // status-polling loop in the else branch never runs. Reuse the same
    // configured "Itho status update frequency" to actively request
    // 31DA + 31D9 over RF — addressed from the first bi-directional
    // Send remote that's been joined to the unit. Skipped silently when
    // there is no CC1101, when no qualifying remote is configured, or
    // when update frequency is set to 0 (off).
    static unsigned long rfStatusReqTim = 0;
    if (systemConfig.rfInitOK
        && systemConfig.itho_updatefreq > 0
        && millis() - rfStatusReqTim >= systemConfig.itho_updatefreq * 1000UL)
    {
      rfStatusReqTim = millis();
      int idx = findFirstBidirectionalSendRemote();
      if (idx >= 0)
        sendRFStatusRequest(static_cast<uint8_t>(idx));
    }
  }
  else
  {
    if (!i2c_init_functions_done)
    {
      initI2cFunctions();
      if (i2c_init_functions_done)
      {
        // Reset timers so normal intervals start from init completion
        query4210tim = millis();
        query2401tim = millis();
      }
    }
    // request itho counter status every systemConfig.itho_counter_updatefreq sec.
    else if (millis() - query4210tim >= systemConfig.itho_counter_updatefreq * 1000UL)
    {
      query4210tim = millis();
      if (systemConfig.itho_4210 == 1)
      {
        i2cQueueAddCmd([]()
                          { sendQueryCounters(false); });
        i2cQueueAddCmd([]()
                          { updateMQTTihtoStatus = true; });
      }
    }
    // request itho status every systemConfig.itho_updatefreq sec.
    else if (millis() - query2401tim >= systemConfig.itho_updatefreq * 1000UL)
    {
      query2401tim = millis();
      bool _updateMQTT = false;
      if (systemConfig.itho_2401 == 1)
      {
        _updateMQTT = true;
        i2cQueueAddCmd([]()
                          { sendQueryStatus(false); });
      }
      if (systemConfig.itho_31da == 1)
      {
        _updateMQTT = true;
        i2cQueueAddCmd([]()
                          { sendQuery31DA(false); });
      }
      if (systemConfig.itho_31d9 == 1)
      {
        _updateMQTT = true;
        i2cQueueAddCmd([]()
                          { sendQuery31D9(false); });
      }
      if (_updateMQTT)
      {
        i2cQueueAddCmd([]()
                          { updateMQTTihtoStatus = true; });
      }
    }

    if (systemConfig.itho_sendjoin > 0 && !joinSend && ithoInitResult == 1)
    {
      joinSend = true;
      i2cQueueAddCmd([]()
                        { sendRemoteCmd(0, IthoJoin); });

      I_LOG("I2C init: Virtual remote join command send");

      if (systemConfig.itho_sendjoin == 1)
      {
        systemConfig.itho_sendjoin = 0;
        saveSystemConfig("flash");
      }
    }

    // Itho queue (I2C PWM control)
    if (clearQueue)
    {
      clearQueue = false;
      ithoQueue.clearQueue();
    }
    if (ithoQueue.ithoSpeedUpdated)
    {
      ithoQueue.ithoSpeedUpdated = false;
      uint16_t speed = ithoQueue.get_itho_speed();
      char buf[32]{};
      snprintf(buf, sizeof(buf), "speed:%d", speed);

      if (writeIthoVal(speed, &ithoCurrentVal, &updateIthoMQTT))
      {
        if (strcmp(lastCmd.source, "") == 0)
          logLastCommand(buf, "ithoQueue");
        sysStatReq = true;
      }
      else
      {
        logLastCommand(buf, "ithoQueue_error");
      }
    }
  }
  // System control tasks
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

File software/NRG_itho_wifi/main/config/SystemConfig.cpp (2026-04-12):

#include "config/SystemConfig.h"

SystemConfig systemConfig;

// default constructor
SystemConfig::SystemConfig()
{
  // default config
  strlcpy(config_struct_version, CONFIG_VERSION, sizeof(config_struct_version));
  strlcpy(sys_username, "admin", sizeof(sys_username));
  strlcpy(sys_password, "admin", sizeof(sys_password));
  syssec_web = 0;
  syssec_api = 0;
  syssec_edit = 0;
  api_normalize = 0;
  api_settings = 0;
  api_reboot = 0;
  itho_rf_co2_join = 0;
  itho_control_interface = 0;
  itho_rf_standalone = 0;
  syssht30 = 0;
  mqtt_active = 0;
  strlcpy(mqtt_serverName, "192.168.1.123", sizeof(mqtt_serverName));
  strlcpy(mqtt_username, "", sizeof(mqtt_username));
  strlcpy(mqtt_password, "", sizeof(mqtt_password));
  mqtt_port = 1883;
  mqtt_version = 1;
  strlcpy(mqtt_base_topic, "itho", sizeof(mqtt_base_topic));
  strlcpy(mqtt_ha_topic, "homeassistant", sizeof(mqtt_ha_topic));
  strlcpy(mqtt_state_retain, "yes", sizeof(mqtt_state_retain));
  mqtt_domoticz_active = 0;
  mqtt_ha_active = 0;
  strlcpy(mqtt_domoticzin_topic, "domoticz/in", sizeof(mqtt_domoticzin_topic));
  strlcpy(mqtt_domoticzout_topic, "domoticz/out", sizeof(mqtt_domoticzout_topic));
  mqtt_idx = 1;
  sensor_idx = 1;
  JsonArray arr __attribute__((unused)) = api_settings_activated.to<JsonArray>();

  itho_fallback = 20;
  itho_low = 20;
  itho_medium = 120;
  itho_high = 220;
  itho_timer1 = 10;
  itho_timer2 = 20;
  itho_timer3 = 30;
  itho_numvrem = 1;
  itho_numrfrem = 10;
  itho_updatefreq = 10;
  itho_counter_updatefreq = 3600;
  itho_sendjoin = 0;
  itho_pwm2i2c = 1;
  itho_31da = 0;
  itho_31d9 = 0;
  itho_2401 = 1;
  itho_4210 = 0;
  itho_forcemedium = 0;
  itho_vremoteapi = 0;
  itho_rf_support = 1;
  i2cmenu = 0;
  i2c_safe_guard = 2;
  i2c_sniffer = 0;
  fw_check = 1;
  rfInitOK = false;
  nonQ_cmd_clearsQ = 1;

  itho_updated = false;
  mqtt_updated = false;
  get_mqtt_settings = false;
  get_sys_settings = false;
  get_rf_settings = false;

  configLoaded = false;

} // SystemConfig

// default destructor
SystemConfig::~SystemConfig()
{
} //~SystemConfig

bool SystemConfig::set(JsonObject obj)
{
  bool updated = false;

  if (!configLoaded)
  {
    if (obj["version_of_program"] != CONFIG_VERSION)
    {
      return false;
    }
  }
  if (!obj["sys_username"].isNull())
  {
    updated = true;
    strlcpy(sys_username, obj["sys_username"] | "", sizeof(sys_username));
  }
  if (!obj["sys_password"].isNull())
  {
    const char* new_password = obj["sys_password"] | "";

    // SECURITY: Ignore placeholder, only update if actual new password
    if (strcmp(new_password, "********") != 0 && strlen(new_password) > 0)
    {
      updated = true;
      strlcpy(sys_password, new_password, sizeof(sys_password));
    }
    // If empty string sent, means user wants to clear password
    else if (strlen(new_password) == 0)
    {
      updated = true;
      memset(sys_password, 0, sizeof(sys_password));
    }
    // If "********", ignore (user didn't change the password field)
  }
  if (!obj["syssec_web"].isNull())
  {
    updated = true;
    syssec_web = obj["syssec_web"];
  }
  if (!obj["syssec_api"].isNull())
  {
    updated = true;
    syssec_api = obj["syssec_api"];
  }
  if (!obj["syssec_edit"].isNull())
  {
    updated = true;
    syssec_edit = obj["syssec_edit"];
  }
  if (!obj["api_normalize"].isNull())
  {
    updated = true;
    api_normalize = obj["api_normalize"];
  }
  if (!obj["api_settings"].isNull())
  {
    updated = true;
    api_settings = obj["api_settings"];
  }
  if (!obj["api_reboot"].isNull())
  {
    updated = true;
    api_reboot = obj["api_reboot"];
  }
  if (!obj["itho_rf_co2_join"].isNull())
  {
    updated = true;
    itho_rf_co2_join = obj["itho_rf_co2_join"];
  }
  if (!obj["itho_control_interface"].isNull())
  {
    updated = true;
    itho_control_interface = obj["itho_control_interface"];
  }
  if (!obj["itho_rf_standalone"].isNull())
  {
    updated = true;
    itho_rf_standalone = obj["itho_rf_standalone"];
  }
  if (!obj["api_settings_activated"].isNull())
  {
    updated = true;
    JsonArray arr = obj["api_settings_activated"].as<JsonArray>();
    api_settings_activated.set(arr);
  }
  if (!obj["syssht30"].isNull())
  {
    updated = true;
    unsigned char value = obj["syssht30"];
    if (value == 0 && syssht30 == 1)
      value = 2; // reset itho setting if applicable
    syssht30 = value;
  }
  // MQTT Settings parse
  if (!obj["mqtt_active"].isNull())
  {
    mqtt_updated = true;
    updated = true;
    mqtt_active = obj["mqtt_active"];
  }
  if (!obj["mqtt_serverName"].isNull())
  {
    updated = true;
    strlcpy(mqtt_serverName, obj["mqtt_serverName"] | "", sizeof(mqtt_serverName));
  }
  if (!obj["mqtt_username"].isNull())
  {
    updated = true;
    strlcpy(mqtt_username, obj["mqtt_username"] | "", sizeof(mqtt_username));
  }
  if (!obj["mqtt_password"].isNull())
  {
    const char* new_password = obj["mqtt_password"] | "";
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

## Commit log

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2020-04-30 Release 1.2
    - Updated PCB design to accommodate a ATTiny 1614 to handle the I2C init with the itho box (Wemos often boots too slow to handle this reliable)
    - Added firmware for the ATTiny
    - Updated Wemos and basic firmware to work with the ATTiny 1614
    - Improved WiFi stability
    [ithowifi-B_Cu.gbl, ithowifi-B_Mask.gbs, ithowifi-B_Paste.gbp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]
2020-06-06 Version 1.2.1 - Wifi config bug fixed (wrong file linked) - Replaced WiFi.status() with wifi_station_get_connect_status() (WiFi.status() buggy??) - Added simple system log to the debug page - Code cl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
    [01_Statics.ino, 04_JS_UI.ino, NRG_itho_wifi.ino]
2020-06-06 Version 1.2.2
    - Static IP config: Whoepsie, forgot to implement code to activate it when selected, corrected
    - Removed port setting, not implemented. Will implement this when requested
    [NRG_itho_wifi.ino]
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2020-11-05 Version 1.3.1
    - Fixed memory leak in hostname construction
    - Moved to stack based JSON object declarations where possible
    - Limited usage op String object as much as possible
    [04_JS_UI.ino, NRG_itho_wifi.ino]
2020-11-15 Version 1.4.0
    - low, medium, high speeds can be changed on setup page
    - MQTT command topic now accepts commands low, medium, high next to integer 0-254
    - Added web API to control itho without MQTT
    - Updated config structure to more easily support future updates
    - BREAKING: this update will reset your system config (wifi settings are not affected), you will have to redefine your MQTT settings.
    [01_Statics.ino, NRG_itho_wifi.ino, SystemConfig.cpp]
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2021-01-03 Version 1.4.3
    - Bugfix: Static IP option was not available during AP mode
    - Bugfix: Domoticz IDX option field displayed wrong
    [04_JS_UI.ino, NRG_itho_wifi.ino]
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2021-01-14 Firmware version 2.0.4
    - Added support for itho remote RFT AUTO C02 (536-0150)
    - Extended RF debug option to include command bytes (useful for adding new remotes or fix non working buttons)
    [04_JS_UI.ino, NRG_itho_wifi.ino]
2021-01-15 Firmware version 2.0.5
    - Added hardware revision and firmware version info to update page
    hardware rev 2 specific:
    - Improved RF receive performance for RFT AUTO C02 (536-0150) remote
    - Bugfix: multiple quick succession remote saves could crash the ESP32, DelayedSave implemented
    [04_JS_UI_HW1.ino, NRG_itho_wifi.ino]
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2021-01-17 Version 2.0.7
    Implemented a firmware check on the update page
    If a newer version of the firmware is available the correct download link will be presented for the hardware revision
    Hardware rev. 2 compiled against new SDK, (wifi) stability improvements observed
    [04_JS_UI_HW1.ino, NRG_itho_wifi.ino]
2021-01-30 Version 2.0.8
    Small logging update (show CC1101 init status in the log)
    Fixed newline bug and potential buffer overflow in logging
    [NRG_itho_wifi.ino]
2021-01-31 Version 2.0.9
    - Added i2c bus busy timeout and logging if this happens
    - AP mode now times out after 15 minutes after which the add-on reboots
    [NRG_itho_wifi.ino]
2021-02-01 Version 2.0.10
    - Simplified the ISR for CC1101 packet handling to one boolean set to improve stability
    - Moved all CC1101 related code to its own task
    - Added a CC1101 task timeout logging to monitor possible CC1101 issues
    [CC1101Task.ino, NRG_itho_wifi.ino]
2021-02-04 Version 2.1
    IMPORTANT FIX: To prevent flash issues, don't store WiFi RF calibration data on flash. In some situations this may lead to flash wear out and stability issues (thanks TD-er!)
    FEATURE: itho speed is retained after reboot (not in case of config reset and file system format)
    FEATURE: File system usage info on debug page
    FEATURE: RF debug logging moved to debug page (will show up at first RF debug message, see manual for debugging details)
    FEATURE: Improved handling of logging and memory use (moved const strings to flash)
    [04_JS_UI_HW1.ino, CC1101Task.ino, NRG_itho_wifi.ino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]
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2021-02-06 Version 2.2b beta
    - BUGFIX: SHT30 humidity/temp sensor detection always returned true also if not present
    - FEATURE: SHT30 sensor detection logged in log
    - FEATURE: SHT30 sensor with alternative address supported
    [NRG_itho_wifi.ino]
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2021-02-19 Version 2.2-beta
    HW Rev 2:
    - Spilt program in multiple tasks, this makes it easier to spot issues
    - Stale tasks at least should result in a log entry
    - Include reset reason in human readable format
    All HW revs:
    - Prevent memory corruption in MQTT PubSubClient lib (issue https://github.com/knolleary/pubsubclient/issues/832)
    - Switch to MQTT PubSubClient lib without dynamic memory allocation
    - MQTT subscribed topic buffer max size
    - MQTT Dynamic JSON to Static JSON buffer
    - Logging buffer as local short lived vars
    - Config save and reset moved to looptask
    - More robust wifi scan code
    - Monitor heap largest block free
    - Added build instructions
    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
    [NRG_itho_wifi.ino]
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2021-02-22 Version 2.2-beta1
    - Bugfix: config could not be saved on HW rev 1
    - Bugfix: Itho init on older devices showed failed status on cold boot
    - Bugfix: Further improve PubSubClient MQTT stability
    - Improvement: move MQTT code to one function / task
    - Improvement: update build instructions
    [NRG_itho_wifi.ino]
2021-02-23 Bugfix for issue #11 (cannot connect to WiFi reliably with firmware v2.0.9 and higher)
    [NRG_itho_wifi.ino]
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2021-02-26 Version 2.2-beta5
    Bugfix: Failed MQTT connection causes WDT reset, WDT timer set to a value bigger than MQTT Connection timeout
    Bugfix: Removed unnecessary wdt_init statements
    Feature: Added MQTT last will topic
    [04_JS_UI_HW1.ino, SystemConfig.cpp]
2021-02-27 Feature: Autodetect for itho temp/hum sensor added (for testing purposes, activate through web interface) Feature: Username and password are configurable Feature: Added basic authentication support (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
    [04_JS_UI.ino, NRG_itho_wifi.ino, SystemConfig.cpp]
2021-03-05 Version 2.2-beta7
    Bugfix: static IP config subnet and gateway value were switched
    [NRG_itho_wifi.ino]
2021-03-17 Versie 2.2 beta-8
    Breaking: system config and remote config will be reset after this update. Wifi settings will be retained.
    Breaking: sensor topic changed from itho/state/sensor to itho/sensor (configurable).
    - Feature: 'virtual' remote functionality has been added. It is now possible to emulate a remote through the i2c bus. With this is is possible to put the itho unit in medium mode at all times by the add-on. Finally a workaround for this issue!
    - Feature: Timer length configurable
    - Feature: Domoticz support for built-in itho temp/hum sensor present in many in newer itho units (or manual added alternative sensor)
    - Feature: The CC1101 library has had a mayor overhaul.
    - Feature: Limite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
    [04_JS_UI.ino, CC1101.cpp, NRG_itho_wifi.ino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]
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2021-03-18 add testing binary. Rough, has debug prints all over, needs reboot after changing every setting to see effect.
    [NRG_itho_wifi.ino]
2021-03-18 Cleanup
    Revert "remove some debug stuff to build test release"
    This reverts commit e17d3fe4b62756ed0c66cb11ddd7760bdb6897e6.
    bugfix: add a freaking ',' to allow webgui to load ... took me a while
    cleanup
    add check if HA discovery is enabled
    typo/cleanup
    plant correct hook, inside setupMQTTClient()
    rename mqttHADiscovery() to mqttHomeAssistantDiscovery()
    restart mqttClient when making changes to settings
    remove some debugging tools
    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
    [04_JS_UI.ino, NRG_itho_wifi.ino, SystemConfig.cpp]
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2021-03-21 Version 2.2-beta9
    - MQTT cleanup: do not subscribe to own published topcs (thanks to sjorsjuhmaniac)
    - added basis filename check on update page
    - bugfix: websocket disconnect during firmware update
    - bugfix: some newer itho remotes (536-0150) were not working correctly
    - bugfix: OTA hangs when serial debugging is enabled
    [04_JS_UI.ino, NRG_itho_wifi.ino]
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2021-04-06 Version 2.2-beta10
    feat: display hum/temp values on webpage if sensor is present (#21)
    feat: home assistant auto discovery implemented (#15)
    feat: show itho speed val above slider on web page (#20)
    feat: add file system format button to debug page
    feat: update hardware design files
    fix: a little more robust itho init check
    [04_JS_UI.ino, NRG_itho_wifi.ino]
2021-04-08 Version 2.2-rc1
    fix: beta10 had an issue with the CC1101 module, a recompile seems to have 'fixed' it
    fix: typo in CC1101 lib
    [NRG_itho_wifi.ino]
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2021-04-16 Version 2.2
    breaking: if FW version =< 2.1.2 or < 2.2-beta8 the system config and remote config will be reset after this update. Wifi settings will be retained.
    General:
    feat: Autodetect for itho temp/hum sensor added (activate through web interface)
    feat: Use wifi mac address to register 'unique' RF remote ID
    feat: Added link to spiffs file editor on debug page
    feat: added basis filename check on update page
    feat: Logging buffer as local short lived vars
    feat: Conf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
    [NRG_itho_wifi.ino]
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2021-09-11 Version 2.3-alpha6
    - Added possibility to readout status of internal itho firmware values
    - Code refactoring and restructuring to compile without warning
    - Bugfix in MQTT password config code
    [NRG_itho_wifi.ino, SHTSensor.cpp, SystemConfig.cpp]
2021-09-15 Version 2.3-alpha7
    - Status values as JSON on sensor MQTT topic
    - itho2401len value added for monitoring of potential i2c readout issues
    [NRG_itho_wifi.ino]
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2021-09-21 Version 2.3alpha9
    - I2C timeout tweaks, still not there yet
    - Corrected settings map for some itho units
    - Fixed parsing of values (uint vs int and length)
    - Decode of 31DA message
    Todo:
    * make hostname configurable
    * make MQTT sensor update time configurable
    * Add DemandFlow and HRU information
    * Add remote buttons to API
    * Decode 31D9 message
    * Improve I2C reliability
    * Restore compatibility with HW rev 1
    * Restructure MQTT topics
    * Include support for RFT-RV and RFT-CO2 remotes
    [NRG_itho_wifi.ino]
2021-10-15 Version 2.3-beta1
    feat: make hostname configurable
    feat: make API sensor update frequency configurable
    feat: Add DemandFlow and HRU eco/350 settings and labels
    feat: Add virtual remote buttons to API
    feat: Include support for RFT-RV and RFT-CO2 remotes (full join handshake not possible yet)
    feat: Add remote hum/temp/co2/battery to html api
    feat: Decode 31D9 message
    feat: Improve I2C reliability (please test)
    feat: Mutex i2c tasks
    feat: Add last command, command origin + timestamp to API
    fix: provide don't save config checkbox before reboot (otherwise changes using the file system editor were overwritten on reboot)
    fix: status page could keep updating even if page was left
    [NRG_itho_wifi.ino, SystemConfig.cpp]
2021-10-22 Version 2.3-beta2
    fix: bogus temperature/humidity value visible even if no sensor present
    fix: remote on index 0 could not be removed
    fix: remove remote wasn't handled correctly in the CC1101 library
    fix: CC1101 support was not working for the NON-CVE wifi module
    fix: removed some unused settings
    fix: simplify hum/temp sensor support setting
    fix: HA autodiscovery not working for hum/temp sensor data
    fix: last command string incorrectly referenced as const char * instead of copy
    fix: failed i2c request' CRC incorrectly resulted in checked OK
    fix: wifi reconnect could result in timeout on task SysControl
    [NRG_itho_wifi.ino, SystemConfig.cpp]
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2021-10-28 Version 2.3-beta3
    fix: timer would always go to high speed, restored API functionality to set speed & timer values at the same time
    fix: add-on settings sometimes not loaded correctly due to websocket connection not active yet
    fix: add units to HA auto discovery sensors
    known issue: some itho settings should not be 32bit wide values. This results in some negative numbers not being parsed correctly in the itho firmware.
    https://github.com/arjenhiemstra/ithowifi/issues/40
    [NRG_itho_wifi.ino, SystemConfig.cpp]
2021-11-01 Version 2.3-beta4
    fix: itho status signed value not correctly handled
    fix: itho settings, fixed support for signed values, < 32 bit wide values and added support for float values
    fix: allocate large MQTT buffer to prevent constant buffer resizing
    fix: reboot after file system format
    fix: format button not reachable in case of file system issues / debug page not loading. Moved to rest page.
    fix: small textual changes on the webinterface
    fix: upgrade to ArduinoJSON 6.18.5
    fix: switch to ESPAsyncWebServer branch with several fixes
    [NRG_itho_wifi.ino]
2021-11-18 Version 2.3-beta5
    - fix: prevent crashes unsupported or partly supported itho devices
    - breaking: On the up-side; all settings and labels have been regenerated and checked (and some translated) with a script, units have been added where available and labels are more descriptive. On the flip-side; automations based on the API, specifically the itho status label based automations might need to be updated.
    - add: support for itho HeatPumt (WPU) devices and AutoTemp devices.
    Please check labels for status and settings, if you see anything wrong, please let me know.
    [itho_rv_sensor-B_Cu.gbr, itho_rv_sensor-B_Mask.gbr, itho_rv_sensor-B_Paste.gbr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]
2021-11-19 Version 2.3-beta6
    fix: CVE 1B version 27 mapping not included
    fix: settingsmap out of bound issue
    fix: statusmap out of bound issue
    fix: status format loop not working as expected
    fix: get status label if statements not working properly
    fix: corrected some labels
    [NRG_itho_wifi.ino]
2021-11-30 - clean-up code - removed ESP8266 support (net enough memory to run all the new features of this version) - removed all PROGMEM en FlashStringhelper code which is not usefull on ESP32 - Textual corre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
    [CC1101.cpp, NRG_itho_wifi.ino, SHTSensor.cpp]
2021-11-30 Version 2.3.0
    Suitable for CVE add-on hardware revision 2 and non-CVE add-on revision 1. The first revision of the add-on based on the ESP8266 is not supported due to memory limitations.
    !Upgrading to this version will format the flash drive and reset all settings (incl. wifi)!
    Device Support:
    feat: Add DemandFlow/QualityFlow, HRU eco/350, AutoTemp and HeatPump (WPU) settings and status labels
    feat: rewritten i2c for HW rev 2, added itho query commands to debug page.
    feat: add possibility to change settings of itho CVE units, use on your own risk
    feat: move add-on settings to menu system settings
    API:
    feat: Add virtual remote buttons to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
    [NRG_itho_wifi.ino]
2021-11-30 Version 2.3.1
    fix: failsave format not working due to missing FS begin satement
    [NRG_itho_wifi.ino]
2021-12-02 Version 2.3.2
    - fix: typo in javascript preventing 'don't save config flag' to get processed correctly
    - fix: small code optimisations
    [NRG_itho_wifi.ino]
2021-12-05 Version 2.3.3
    - Move the Mongoose for WebSocket server to fix stability issues and win10 WebSocket issues
    - Round hum and temp values to 1 decimal
    - clean-up includes, move to c++ libs
    [NRG_itho_wifi.ino, SHTSensor.cpp, SystemConfig.cpp]
2021-12-09 Version 2.3.4
    - fix: original itho temp/hum sensor (de)activation not handled correctly
    - fix: WebAPI speed & timer combo not parsed correctly
    - fix: buffer for queue debug JSON not big enough
    - fix: on mobile devices the speed slider did not work as expected
    [NRG_itho_wifi.ino, SystemConfig.cpp]
2021-12-10 Version 2.3.5
    Version 2.3.5
    - fix: typo in WebAPI causing timer always being set to speed amount of minutes
    [ithowifi_4l.kicad_pcb]
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2022-02-20 Version 2.4.0-alpha1
    For testing purposes only!
    Feat: Add support for extra itho remote commands (Auto, AutoNight, Cook30, Cook60)
    Feat: Add possibility to configure number of virtual remotes
    Feat: Add possibility to copy ID of existing remote to be used with a virtual remote
    Feat: Add filterReset command to debug page (need testing)
    Feat: Log deviceType query failure
    Fix: update MQTT status when no itho is detected
    Fix: crash when having multiple browser tabs open and requesting settings
    Fix: properly initialise RF debug buffer
    Version 2.4.0-alpha1
    For testing purposes only!
    Feat: Add support for extra itho remote commands (Auto, AutoNight, Cook30, Cook60)
    Feat: Add possibility to conf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
    [NRG_itho_wifi.ino, SystemConfig.cpp]
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2022-03-02 Version 2.4.0-alpha2
    - feat: add option to only monitor remote (ie. remote commands and values like CO2 will be present on the API but will not be send to the itho)
    - feat: add RF debug button to the debug page for easier access to the debug function
    - feat: add timer1-timer3 buttons to web interface
    - feat: tie web interface buttons to backend commands
    - fix: level commands not parsed correctly, mainly for the RFT-AUTO 536-0150 remote (issue https://github.com/arjenhiemstra/ithowifi/issues/81)
    - fix: prevent nullptr exception when no itho is present and a setting is updated through the debug page
    - fix: rounding issue with remote hum/temp values
    [NRG_itho_wifi.ino]
2022-03-02 Version 2.4.0-alpha2
    Version 2.4.0-alpha2
    - feat: make NTP server configurable (https://github.com/arjenhiemstra/ithowifi/pull/79)
    - fix: prevent nullptr exception when no itho is present and a setting is updated through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
    [NRG_itho_wifi.ino]
2022-03-04 Version 2.4.0-alpha3
    feat: add virtual remotes changes to API, update API documentation
    feat: add support for away command of 536-0020 and 536-0024 remotes
    fix: remove unused code
    fix: restore send join command on power-on function
    [NRG_itho_wifi.ino, SystemConfig.cpp]
2022-03-05 Version 2.4.0-alpha4
    fix: HTML API not working correctly for some commandos
    fix: Update itho setting on debug page does not give back result of change
    fix: Update itho setting on debug page does not handle floats correctly
    [NRG_itho_wifi.ino]
2022-03-23 Version 2.4.0-alpha5
    fix: correct rounding issues since ArduinoJSON library update
    fix: restore RF debug function to show all devices when in debug level 1 or 3 mode
    fix: domoticz slider value cannot go to 0
    fix: remove unused DHCP renew option
    [NRG_itho_wifi.ino]
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2022-05-20 Version 2.4.0-alpha7
    Feat: Restructure code to support VSCode and PlatformIO
    Feat: Script web page header file creation and compression
    Feat: Clean up formatting of sources
    Feat: Added RFT RF/CO2 virtual remote support
    Fix: remove fallback speed being set on MQTT update
    [CC1101.cpp, NRG_itho_wifi.ino, SHTSensor.cpp]
2022-05-20 Version 2.4.0-alpha7
    Update websource headers
    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
    [CC1101.cpp, NRG_itho_wifi.ino, SHTSensor.cpp]
2022-07-07 Version 2.4.0-alpha8
    - Include first support for HRU250 and HRU300 devices
    - Fix issue #94 - https://github.com/arjenhiemstra/ithowifi/issues/94
    [generic_functions.cpp, main.cpp, task_syscontrol.cpp]
2022-09-18 Version 2.4.0-beta1
    Changes:
    feat: moved to latest version (5.1.1) of platform-espressif32 (with ESP-IDF 4.4.1, Arduino core 2.0.4)
    feat: moved to new version of the file editor, lowering the dependancy on ESPAsyncWebserver libs (in the future everything web related will probably move to mongoose)
    feat: slider hidden on devices that do not support PWM2I2C protocol (NON-CVE) to prevent control confusion
    feat: slider move will immediately update slider value in web interface
    feat: add preliminary support for ORCON 15LF01 remote
    feat: added option to show wifi password
    fix: HRU 250-300 incorrectly reported as HRU 200-250
    fix: unify i2c mutex control to same layer
    fix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
    [CC1101.cpp, SHTSensor.cpp, generic_functions.cpp]
2022-09-26 Version 2.4.0
    Changes from version 2.3.5
    Feat: Added option to update remote ID's through the web interface
    Feat: Slider hidden on devices that do not support PWM2I2C protocol (NON-CVE) to prevent control confusion
    Feat: Slider move will immediately update slider value in web interface
    Feat: Add preliminary support for ORCON 15LF01 remote
    Feat: Added option to show wifi password
    Feat: Include first support for HRU250 and HRU300 devices
    Feat: Add HRU200 settings and status labels
    Feat: Add virtual remotes changes to API, update API documentation
    Feat: Add support for away command of 536-0020 and 536-0024 remotes
    Feat: Add option to only monitor r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
    [generic_functions.cpp, task_configandlog.cpp]
2022-09-27 Version 2.4.2-beta1
    For testing purposes!
    Changes since 2.4.1:
    Fix: disable storage and usage of wifi parameters on ESP32 NVS partition
    [task_syscontrol.cpp]
2022-10-03 Version 2.4.2-beta2
    Fix: possible fix for WiFi connect issues #108 with input of @vandenberghev, thanks!
    Fix: Replace strcpy by strlcpy for buffer overflow protection
    [generic_functions.cpp, task_configandlog.cpp]
2022-10-04 Version 2.4.2-beta3
    Fix: connection issues were multiple APs have same SSID name and add-on connects to first AP to react and not AP with best signal #108
    Feat: added extra wifi logging; which BSSID is connected and what is the signal strength
    Feat: update to latest ESP32 arduino core (5.2.0) for PIO
    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
    [task_syscontrol.cpp]
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2022-10-12 Version 2.4.3-beta1
    Changes since 2.4.2:
    Fix: lastCmd.source points sometimes point to bogus mem location
    Fix: Added I2C unblock function, tries to reset I2C bus and logs result (for issues: #111, #102, #61)
    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
    [generic_functions.cpp]
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2022-10-27 Version 2.4.3
    Fix: improve I2C stability and multi-master checking before every I2C master call
    Feat: add (hidden) setting to prevent PWM2I2C init
    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
    [SystemConfig.cpp, task_syscontrol.cpp]
2022-11-11 Version 2.4.4-beta1
    Fix: add I2C debug option to config, enabling logging of last i2c commands to help solve I2C issues on newer CVE devices
    Feat: On NON-CVE devices to buttons on the index page now reflect the first virtual remote
    [SHTSensor.cpp, SystemConfig.cpp]
2022-12-02 Version 2.4.4-beta2
    Version 2.4.4-beta2
    Feat: i2c commands queued
    Feat: log now queue based
    Feat: syslog option
    Feat: Make log level configurable
    Feat: Error checking on received JSON to prevent websocket crashes
    Feat: Unified firmware, firmware now autodetects device type
    Feat: Implemented I2C sniffer option (only for sniffer capable devices, autodetected and logged at boot)
    Feat: I2C2PWM command can now correctly handle 255 as max setting
    Bugfix: Made debug page dynamic to prevent big load and issues with memory allocation leading to crashes
    temp remove i2c log to webinterface
    [NRG_itho_wifi.ino, SHTSensor.cpp, SystemConfig.cpp]
2022-12-07 Version 2.4.4-beta3
    Changes since 2.4.4-beta2:
    fix: improve system stability (still a workaround)
    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
    [NRG_itho_wifi.ino, task_syscontrol.cpp, websocket.cpp]
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2023-01-04 - check if i2c returned buffer is reply of requested command - fix mqtt web interface issues - change syslog queue from FreeRTOS queue to stl deque
    [task_configandlog.cpp, task_syscontrol.cpp]
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2023-01-12 Version 2.4.4-beta6
    fix: replace all sprintf statements to prevent buffer overflows
    fix: limit i2c queue size to prevent memory issues
    fix: limit syslog queue size to prevent memory issues
    fix: tweak task timeout values
    fix: raise syscontrol task prio to improve settings retrieval reliabiltiy
    fix: improve settings retrieval error reporting
    fix: i2c sniffer to webinterface
    fix: do not truncate i2c sniffer output to syslog server
    fix: tweak task stack sizes
    [generic_functions.cpp]
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
